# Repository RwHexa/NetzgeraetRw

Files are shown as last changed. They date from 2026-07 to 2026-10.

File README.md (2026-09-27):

# NetzgeraetRw — 12‑V‑Sperrwandler verstehen, prüfen & simulieren

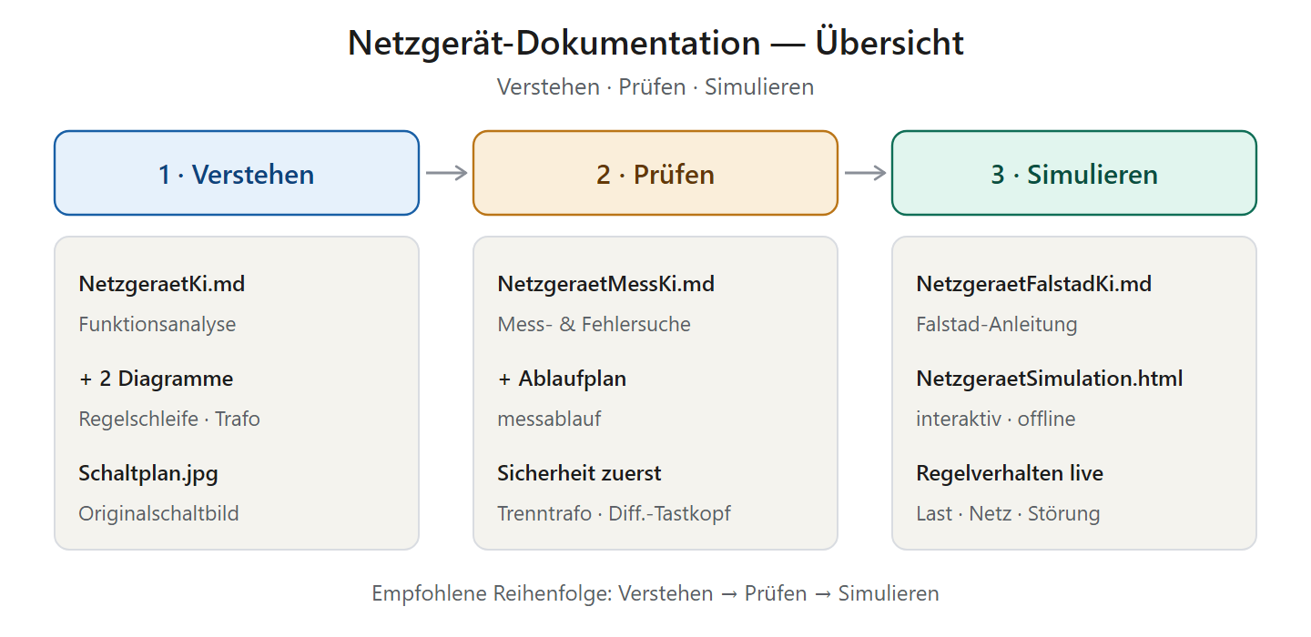
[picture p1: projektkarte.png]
Projektkarte


Dokumentation eines isolierten **Sperrwandler‑Netzteils** (12 V, ~10–15 W) mit dem PWM‑Controller **OB2263**, Optokoppler **PC817** und **TL431** — aufbereitet als Lehr‑/Werkstattbericht in drei Schritten: **Verstehen → Prüfen → Simulieren**.

## 📚 Inhalt

| Teil | Datei | Inhalt |
|---|---|---|
| 🗂️ Start | [NetzgeraetUebersichtKi.md](NetzgeraetUebersichtKi.md) | Gesamtübersicht mit Inhaltsverzeichnis & Lernpfad |
| 📘 Verstehen | [NetzgeraetKi.md](NetzgeraetKi.md) | Funktionsanalyse (Regelung, Trafo, Bauteile) |
| 🔧 Prüfen | [NetzgeraetMessKi.md](NetzgeraetMessKi.md) | Störungs‑ & Fehleranalyse (sichere Messungen) |
| 🖥️ Simulieren | [NetzgeraetFalstadKi.md](NetzgeraetFalstadKi.md) | Aufbau im Falstad‑Browser |
| 🎛️ Interaktiv | [NetzgeraetSimulation.html](NetzgeraetSimulation.html) | Offline‑Simulation des Regelverhaltens |
| 📄 Heft | `NetzgeraetHeft.pdf` | Alles gebündelt als gestaltetes PDF‑Heft |

## 🎛️ Interaktive Simulation

`NetzgeraetSimulation.html` einfach im Browser öffnen (läuft offline, keine Installation). Schieberegler für **Netzspannung** und **Laststrom**, Knöpfe für **Lastsprung** und **Regelung öffnen** — zeigt live, wie der Regelkreis die 12 V hält und was bei offener Rückkopplung passiert.

## 🖼️ Diagramme

Alle selbst erstellten Diagramme liegen als `.svg` (Quelle) **und** `.png` (2×) vor:
`regelschleife` · `trafo_zwei_phasen` · `messablauf` · `vergleich_schaltplaene` · `projektkarte`.

## ⚖️ Rechte & Quellen

- **Eigene Inhalte** (Texte, selbst erstellte Diagramme, HTML‑Simulation, Heft, Logo): © Reinhard Wermeling (RwTec), erarbeitet mit Claude Code.
- ⚠️ **Fremde Bilder** (nur zu Lern‑/Referenzzwecken): einige Bitmap‑Schaltbilder und Fotos stammen aus dem Web und unterliegen fremdem Urheberrecht — u. a. `Schaltplan_vollstaendig.jpg` (Wasserzeichen ornatepixels.com), `Schaltplan.jpg` / `SchaltplanKl.JPG`, `PlatineKl.JPG`. **Nicht für Weiterverbreitung.** Vor einer etwaigen Veröffentlichung entfernen oder durch eigene Nachzeichnungen ersetzen.

---
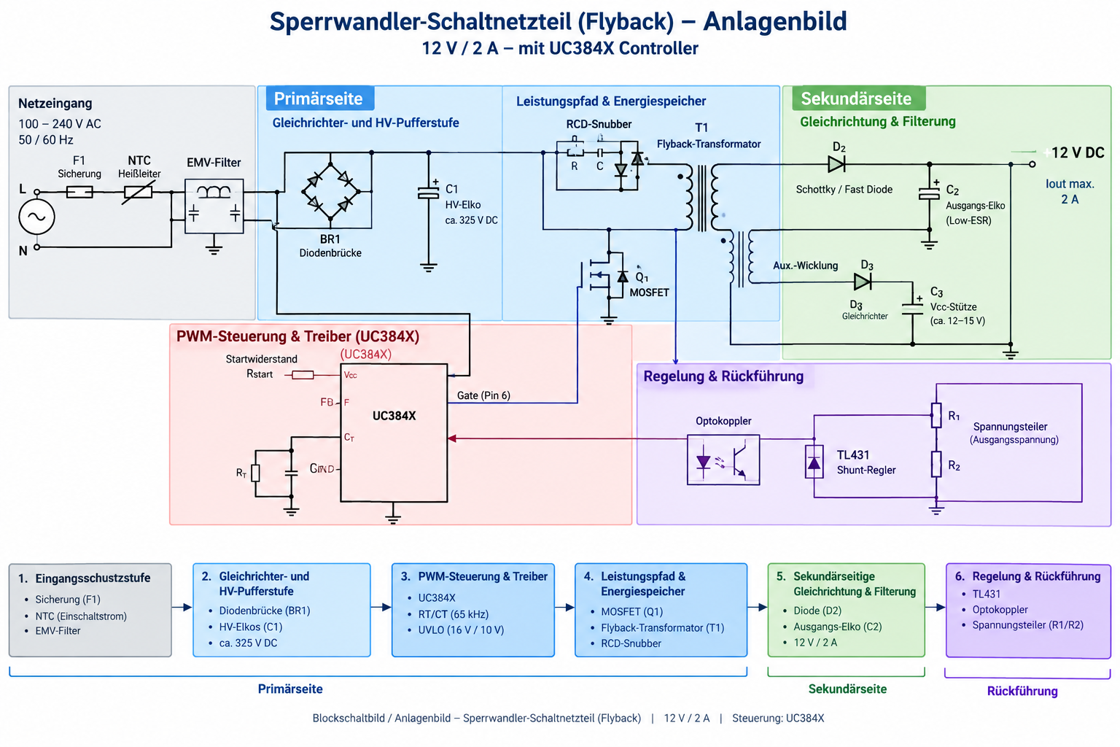
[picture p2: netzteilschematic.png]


*Werkstattbericht · RwTec · 2026 · erstellt mit Claude Code*

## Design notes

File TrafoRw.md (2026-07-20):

## 1. Einleitung und Historie
Der Flyback-Wandler (Sperrwandler) gehört zu den am weitesten verbreiteten Topologien für Schaltnetzteile. Kommerziell wird diese Technologie seit den **1940er und 1950er Jahren** genutzt. Ihr ursprünglicher Einsatzbereich lag in Röhrenfernsehern, wo der Flyback-Transformator (Zeilentransformator) die extrem hohen Spannungen für die Bildröhre generierte. Mit dem Aufkommen moderner Leistungshalbleiter (MOSFETs) in den **1970er Jahren** wandelte sich das Einsatzgebiet hin zu kompakten, hocheffizienten Netzteilen.
## 2. Funktionsprinzip und Besonderheiten
Entgegen einem klassischen Netztransformator überträgt der Flyback-Transformator die elektrische Energie nicht sofort, sondern arbeitet als **gekoppelte Speicherdrossel**:
1. **Leitphase (Ein):** Der primärseitiger Schalter schießt. Energie baut sich im Magnetfeld auf. Die sekundundärseitige Diode sperrt.
2. **Sperrphase (Aus):** Der Schalter oeffnet. Das Magnetfeld bricht zusammen und induziert eine Spannung. Die Diode leitet und die Energie wird zeitversetzt an den Ausgang abgegeben.
Um eine magnetische S\'e4ttigung des Kerns zu verhindern und eine hohe Energiespeicherung zu erm\'f6glichen, besitzt der Kern fast immer einen definierten **Luftspalt**.
## 3. Mathematische Zusammenhänge (Dimensionierung)
Die Ausgangsspannung ($U_\{out\}$) wird nicht allein durch das Windungsverhältnis ($n = N_P / N_S$) bestimmt, sondern maßgeblich durch den Tastgrad ($D$) des Schalters gesteuert:
$$U_\{out\} = U_\{in\} \\cdot \\frac\{1\}\{n\} \\cdot \\frac\{D\}\{1-D\}$$

* **Spannungsbelastung:** Beim oeffnen des Schalters entsteht eine reflektierte Spannung ($U_\{ref\} = n \\cdot U_\{out\}$) auf der Primärseite. Der Halbleiterschalter muss so dimensioniert sein, dass er die Summe aus Eingangsspannung und reflektierte Spannung ($U_\{in\} + U_\{ref\}$) sicher blockieren kann.
## 4. Wicklungsdesign und Querschnitte
Wegen der unterschiedlichen Spannungs- und Stromniveaus sind Primär- und Sekundundärseite asymmetrisch dimensioniert:
* **Leiterquerschnitt ($A$):** Bestimmt sich \'fcber den effektiven Strom ($I_\{RMS\}$) und die zul\'e4ssige Stromdichte ($J$, praxisnah $3$ bis $5\\text\{ A/mm\}^2$) nach der Formel: $A = I_\{RMS\} / J$.
* **Skin-Effekt:** Da Flyback-Wandler bei hohen Frequenzen ($50\\text\{ kHz\}$ bis \'fcber $300\\text\{ kHz\}$) arbeiten, verdr\'e4ngt der Skin-Effekt den Strom an die Drahtoberfläche. 
* **Praktische Umsetzung:** Dicke Einzeldr\'e4hte werden vermieden. Stattdessen kommen mehrere parallel gewickelte, d\'fcnne Dr\'e4hte oder flexible **HF-Litzen** (B\'fcndel isolierter Einzeladern) zum Einsatz, um den Innenwiderstand und die Erw\'e4rmung zu minimieren.
## 5. Heutige Haupteinsatzgebiete
Aufgrund der geringen Bauteilanzahl, der galvanischen Trennung und der kosteng\'fcnstigen Produktion ist der Flyback-Transformator heute der Standard f\'fcr kleine bis mittlere Leistungen (**bis ca. 150 Watt**):
* Steckernetzteile und Ladeger\'e4te (Smartphones, Laptops)
* Hilfs- und Standby-Stromversorgungen in Haushaltsger\'e4ten und PCs
* Treiberstufen f\'fcr LED-Beleuchtungen
* Kompakte Stromversorgungen in der Industrie- und Automobiltechnik
# Anhang: Stückliste ein Flyback-Beispielnetzteil

### Spezifikation des Referenzdesigns:
* **Eingangsspannung ($U_\{in\}$):** 9 V bis 16 V DC (Nennwert: 12 V)
* **Ausgangsspannung ($U_\{out\}$):** 2,67 V DC (geregelt)
* **Ausgangsstrom ($I_\{out\}$):** Max. 3 A ($I_\{RMS\} \\approx 3\\text\{ A\}$ auf der SekundundärSeite)
* **Schaltfrequenz ($f_\{sw\}$):** 100 kHz

| Bauteil-ID | Komponente | Beschreibung / Technische Daten | Menge | Geh\'e4useform / Typ |
| :--- | :--- | :--- | :--- | :--- |
| **TR1** | **Flyback-Transformator** | Kern: Ferrit (z. B. EF20 oder E25/13/7)<br>Luftspalt: ca. 0,2 mm<br>Windungsverh\'e4ltnis (n): 3:1 ($N_P = 18$, $N_S = 6$)<br>Prim\'e4rdraht: 1\'d7 0,4 mm Kupferlackdraht<br>Sekund\'e4rdraht: **HF-Litze 24\'d7 0,2 mm** (wegen Skin-Effekt) | 1 | E-Kern horizontal / Kundenspezifisch |
| **IC1** | **PWM-Controller** | Current-Mode Flyback-Controller mit fester Frequenz (100 kHz), integrierter Unterspannungssperre und Sanftanlauf. | 1 | SOIC-8 (z. B. UC384x-Serie oder LM5021) |
| **Q1** | **Leistungsschalter (MOSFET)** | N-Kanal MOSFET<br>Spannungsfestigkeit: \f1\u8805?\f0  30 V (berechnet: 20 V + Sicherheitsreserve)<br>Strombelastbarkeit: \f1\u8805?\f0  6 A<br>Niedriger Einschaltwiderstand ($R_\{DS(on)\} < 10\\text\{ m\}\\Omega$) | 1 | TO-220 oder DPAK |
| **D1** | **Ausgangsdiode** | Schottky-Diode (f\'fcr schnelles Schalten bei 100 kHz)<br>Sperrspannung: \f1\u8805?\f0  20 V<br>Dauerstrom: \f1\u8805?\f0  5 A (z. B. wegen Anlaufstr\'f6men) | 1 | TO-220AC oder SMC |
| **C_IN** | **Eingangskondensator** | Elektrolytkondensator (Low-ESR)<br>Kapazit\'e4t: 470 \'b5F / Spannungsfestigkeit: 25 V | 1 | Radial, durchsteckbar (PTH) |
| **C_OUT** | **Ausgangskondensator** | Elektrolytkondensator (Low-ESR) zur Gl\'e4ttung der pulsierenden Sperrwandler-Str\'f6me.<br>Kapazit\'e4t: 1000 \'b5F / Spannungsfestigkeit: 6,3 V | 1 | Radial, durchsteckbar (PTH) |\par
| **R_SENSE** | **Strommesswiderstand** | Shunt-Widerstand zur \'dcberwachung des Prim\'e4rstroms (\'dcberlastschutz).<br>Wert: 0,1 \f2\lang1032\'d9 / Leistung: 0,5 W | 1 | SMD 1206 oder Metallschicht |
| **IC2** | **Spannungsregler / Optokoppler** | Zur galvanisch getrennten R\f0\lang1033\'fcckf\'fchrung des Ausgangssignals an den Controller IC1.<br>Bestehend aus Referenz-IC (z. B. TL431) und Optokoppler. | 1 | DIP-4 / SOT-23 |
| **R1, C1** | **Snubber-Netzwerk (RCD)** | Bed\'e4mpft die zerst\'f6rerischen Spannungsspitzen beim Ausschalten von Q1.<br>R: 1 k\f2\lang1032\'d9 (1 W), C: 2,2 nF (100 V), D: Schnelle Diode (z. B. 1N4148) | 1 Set | SMD 1206 / DO-35 |
### Design-Hinweise zur St\f0\lang1033\'fcckliste:
1. **Der Transformator (TR1):** Da es Flyback-Transformatoren selten als Standardbauteil von der Stange gibt, wird er f\'fcr das jeweilige Projekt basierend auf dem Kernmaterial (Ferrit) und den berechneten Drahtquerschnitten (HF-Litze sekund\'e4r) meist selbst gewickelt oder als Custom-Bauteil bestellt.
2. **Die Kondensatoren (C_IN / C_OUT):** Wegen der hohen Schaltfrequenz und Rippelstr\'f6me m\'fcssen unbedingt **Low-ESR-Typen** (geringer Innenwiderstand) verwendet werden, da Standard-Elkos sonst überhitzen.

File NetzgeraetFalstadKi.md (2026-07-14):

# Den Sperrwandler in Falstad simulieren (vereinfacht)

*Schritt für Schritt zu einer animierten, geregelten Flyback‑Schaltung im Browser — ein Werkstattbericht (Simulations‑Teil)*

> **Kurzfassung:** Mit dem kostenlosen **Falstad CircuitJS** (läuft im Browser, keine Installation) lässt sich das Prinzip des Netzteils anschaulich nachbauen: Zwischenkreis → Schalter → Trafo → Gleichrichtung → **geschlossener Regelkreis**. Den OB2263 ersetzen wir durch einen kleinen PWM‑Erzeuger + Fehlerverstärker (gleiche Wirkung). Am Ende siehst du den Strom fließen und kannst live an Last und Eingangsspannung drehen — genau wie im Lern‑Widget.

---

## 🧭 Warum Falstad — und was es kann/nicht kann

- ✅ **Sofort startklar:** [falstad.com/circuit](https://www.falstad.com/circuit/) im Browser öffnen, fertig. Es gibt auch eine Desktop‑Version.
- ✅ **Animierter Stromfluss** — ideal fürs Verstehen von Gleichrichtung, Trafo und Rückkopplung.
- ⚠️ **Kein OB2263‑Modell** (gibt es nirgends frei). Wir bauen seine *Architektur* nach: Sägezahn + Komparator = PWM, Op‑Amp = Fehlerverstärker.
- ⚠️ **Vereinfachte Trennung:** Für die Anschauung lassen wir TL431 + Optokoppler weg und regeln mit **einem** Op‑Amp auf gemeinsamer Masse. Das zeigt das Regelverhalten korrekt — nur eben ohne galvanische Trennung. (Erweiterung siehe unten.)

---

## ⚙️ Vorbereitung (wichtig!)

Ein Schaltnetzteil taktet mit ~65 kHz. Damit Falstad das sauber rechnet:

1. Menü **Options → Other Options**: **Time step size** auf ca. **`1e-7` … `2e-7` s** stellen (Standard 5e‑6 ist viel zu grob → unbrauchbar).
2. Oben den Regler **Simulation Speed** langsam stellen, um die Vorgänge zu beobachten.
3. Menü **Scopes**: Später Messpunkte hinzufügen (Rechtsklick auf Bauteil → *View in Scope*).

---

## 🗺️ Detaillierter Schaltplan (zum Nachbauen)

Dieser Plan zeigt jeden Knoten. **Gleiche Netznamen** (`VOUT`, `GATE`, `CONTROL`, `FB`) sind in Falstad **derselbe Knoten** — du kannst sie entweder direkt verdrahten oder in Falstad als *Labeled Node* (`Draw → Outputs and Labels → Add Labeled Node`) gleich benennen. Die Schaltung ist **nicht isoliert** (eine gemeinsame Masse).

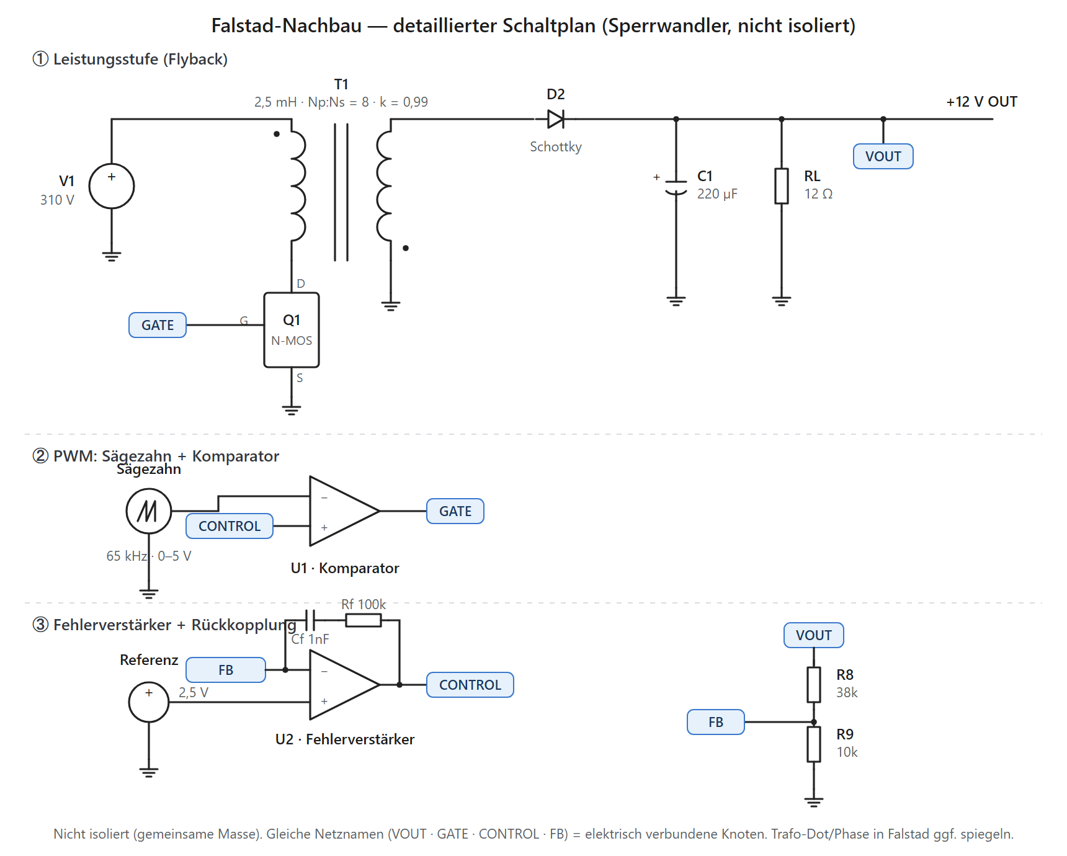
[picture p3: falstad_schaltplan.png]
Detaillierter Falstad-Schaltplan des Sperrwandlers


### Verdrahtungs-Checkliste (Knoten für Knoten)

| Knoten | Verbindet |
|---|---|
| **VIN** | V1 (+) · T1 Primär oben |
| **DRAIN** | T1 Primär unten · Q1 Drain · (Snubber optional) |
| **GATE** | Q1 Gate · Komparator‑Ausgang (U1) |
| **RAMP** | Sägezahn‑Quelle · Komparator **−**‑Eingang (U1) |
| **CONTROL** | Fehlerverstärker‑Ausgang (U2) · Komparator **+**‑Eingang (U1) |
| **SEK** | T1 Sekundär · D2 Anode |
| **VOUT** | D2 Kathode · C1 (+) · RL · R8 (oben) |
| **FB** | R8/R9‑Mittelabgriff · U2 **−**‑Eingang · RC‑Glied (Rf/Cf) |
| **REF** | 2,5‑V‑Quelle · U2 **+**‑Eingang |
| **GND** | V1 (−) · Q1 Source · T1 Sekundär (andere Seite) · C1/RL (−) · R9 · alle Quellen‑Massen |

> 💡 **Reihenfolge, die selten hakt:** erst die **Leistungsstufe** (V1 → T1 → Q1 → D2 → C1/RL) aufbauen und mit einer festen Gate‑Rechteckquelle testen (schaltet der MOSFET, kommt Spannung raus?). Dann **U1 + Sägezahn** dranhängen (PWM steht). Zuletzt **U2 + Teiler + Referenz** — jetzt schließt sich der Regelkreis.

---

## 🛠️ Der Aufbau in 7 Schritten

Bauteile kommen aus dem **Draw**‑Menü (Kategorien heißen je nach Version leicht anders). Werte per **Rechtsklick → Edit** einstellen.

**① Zwischenkreis (die „~310 V")**
- `Draw → Inputs and Sources → Add Var Rail` (einstellbare DC‑Quelle). Wert **310 V**. Der Schieberegler dieser Quelle wird später dein „Netzspannungs"-Regler.
- `Add Ground` als Bezugsmasse.

**② Sperrwandler‑Trafo**
- `Draw → Passive Components → Add Transformer`.
- Rechtsklick → Edit: **Primary Inductance ≈ 2,5 mH**, **Turns Ratio (Np:Ns) ≈ 8**, **Coupling Coefficient 0,99**.
- Primär‑oben an **+310 V**.

**③ Schalttransistor (statt Q1)**
- `Draw → Active Components → Add MOSFET (N‑Channel)`.
- **Drain** an Primär‑unten, **Source** an Masse, **Gate** kommt später vom PWM (Schritt ⑤).

**④ Sekundär‑Gleichrichtung**
- `Add Diode` von der Sekundärwicklung zum Ausgangsknoten (**+12 V**).
- `Add Capacitor` **220 µF** vom Ausgang zur Sekundärmasse.
- `Add Resistor` **12 Ω** als Grundlast (≈ 1 A). Optional einen `Add Switch` mit zweitem Lastwiderstand für den „Lastsprung".
- 🔎 *Dot‑Test:* Leitet die Diode schon in der **Einschaltphase**, ist die Wicklung falsch herum — dann die **beiden Sekundär‑Anschlüsse tauschen** (Flyback ⇒ Diode leitet in der Ausschaltphase).

**⑤ PWM erzeugen (statt Oszillator im OB2263)**
- `Add A/C Voltage Source` → Edit: **Waveform = Sawtooth**, **Frequency = 65k**, Amplitude/Offset so, dass sie **0…5 V** rampt.
- `Add Op Amp` als **Komparator**: **−**‑Eingang = Sägezahn, **+**‑Eingang = Regelspannung (aus ⑥), **Ausgang → Gate** des MOSFET. So gilt: Regelspannung hoch ⇒ Tastverhältnis groß.

**⑥ Rückkopplung / Fehlerverstärker (statt TL431 + Opto)**
- Teiler **R8 = 38 kΩ** (oben, von +12 V) und **R9 = 10 kΩ** (unten, zur Masse). Mittelabgriff = Istwert.
- Referenz **2,5 V**: eigener `Add Var Rail` (2,5 V) oder Zenerdiode.
- `Add Op Amp` als **Fehlerverstärker**: **−**‑Eingang = Istwert (Teiler), **+**‑Eingang = 2,5 V, **Ausgang = Regelspannung** → an den +‑Eingang des Komparators (⑤).
- Zur Stabilität ein **RC‑Glied** (z. B. 100 kΩ + 1 nF) vom Op‑Amp‑Ausgang zurück auf den −‑Eingang (macht ihn zum PI‑Regler).
- 🔑 Vorzeichen: Steigt U_out → Istwert steigt → (invertierender Eingang) Regelspannung sinkt → Duty sinkt → U_out sinkt. **Gegenkopplung.** Ausgangsspannung stellt sich auf `U_out = 2,5 V × (1 + R8/R9) = 2,5 × 4,8 = 12 V` ein.

**⑦ Messen & Ausprobieren**
- Rechtsklick → *View in Scope* auf: **Ausgang (+12 V)**, **Gate**, **Primärwicklung (Strom)**.
- Grundlast ändern (Widerstand editieren) → U_out bleibt ~12 V.
- **Var Rail (310 V) schieben** → U_out bleibt stabil, Duty ändert sich.
- **Regelung „öffnen":** die Regelspannung fest verdrahten (Fehlerverstärker abklemmen) → bei kleiner Last **läuft U_out in die Überspannung** — dieselbe Aussage wie im Lern‑Widget.

---

## 📋 Bauteil-/Wertetabelle

| Element (Falstad) | Wert | Rolle in der echten Schaltung |
|---|---|---|
| Var Rail | 310 V | Zwischenkreis C2 (~325 V) |
| Transformer | L₁ 2,5 mH · n 8 · k 0,99 | T1 (EE16) |
| MOSFET (N) | Standard | Q1 (7N65) |
| Diode | Standard/Schottky | D2 (SR540) |
| Capacitor | 220 µF | C6 |
| Resistor (Last) | 12 Ω | Verbraucher |
| A/C Source (Sawtooth) | 65 kHz, 0–5 V | Oszillator im OB2263 |
| Op Amp (Komparator) | ideal | PWM‑Vergleicher (CS/FB‑Logik) |
| Op Amp (Fehlerverst.) | + RC 100k/1nF | TL431 |
| R8 / R9 | 38 kΩ / 10 kΩ | Sollwert‑Teiler |
| Var Rail (2,5 V) | 2,5 V | interne TL431‑Referenz |

---

## ⚠️ Stolpersteine

- **Time step vergessen** → 65 kHz wird nicht aufgelöst, „Konvergenzfehler" oder Unsinn. Immer ~`1e-7` setzen.
- **Trafo‑Kopplung 0,99**, nicht 1,0 — sonst kein realistisches Verhalten; eine kleine Streuung erzeugt eine Drain‑Spitze (dafür bräuchte man einen Snubber).
- **Falsche Dot‑Orientierung** → Diode leitet zur falschen Zeit → Sekundär‑Anschlüsse tauschen.
- **Vorzeichen der Regelung** → läuft U_out weg oder auf 0, die beiden Op‑Amp‑Eingänge tauschen.
- **Op‑Amp schwingt** → RC‑Kompensation vergrößern (Cf erhöhen).

---

## ✅ Funktionierende Simulation (Ergebnis)

So sieht der laufende Regelkreis in Falstad aus — stabile Ausgangsspannung, alle Blöcke aktiv:

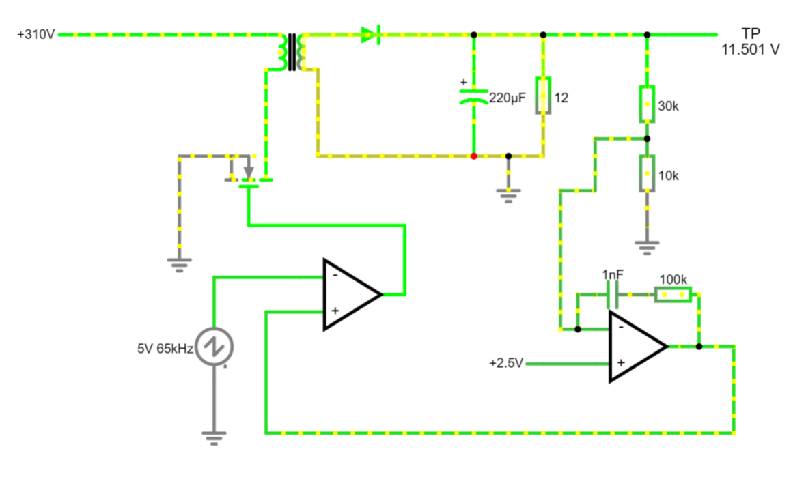
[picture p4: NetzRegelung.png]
Falstad-Simulation der Regelung — TP ≈ 11,5 V


> **Kurzfassung:** Der Teiler **30k/10k** ergibt den Lehrbuch‑Sollwert `2,5 V × (1 + 30/10) = 10 V`; angezeigt werden **11,5 V**. Dieser kleine Rest‑Offset ist normal — der vereinfachte Fehlerverstärker ist kein idealer Integrator (endliche Schleifenverstärkung). Reale Controller wie der OB2263 fahren die Verstärkung so hoch, dass er praktisch verschwindet.

- **Regelung nachweisen:** Last ändern (12 Ω → 8/24 Ω) oder die 310‑V‑Rail schieben → TP bleibt (nahezu) stehen = die Schleife regelt.
- **Exakt 12 V:** oberen Teilerwiderstand trimmen, bis TP 12,0 V zeigt — oder U2 als echten Integrator (Serien‑C + Eingangswiderstand) verschalten.

---

## 🚀 Ausbaustufen

1. **Netzeingang echt:** Var Rail ersetzen durch `A/C Voltage Source` (325 V Spitze, 50 Hz) + 4 Dioden‑Brücke + 47 µF → man sieht die ~310 V entstehen.
2. **Snubber:** RCD‑Glied über der Primärwicklung, um die Drain‑Spitze zu zähmen.
3. **Echte Trennung:** Optokoppler als LED + lichtgesteuerte Stromquelle nachbilden und Fehlerverstärker auf eine zweite Masse legen — anspruchsvoll, aber näher am Original.

> 💡 Für den Unterricht reichen die Schritte ①–⑦ völlig: Man sieht **Leistungspfad** (Var Rail → MOSFET → Trafo → Diode → Last) und **Regelpfad** (Teiler → Fehlerverstärker → Komparator → Gate) zusammenspielen — und im „offenen" Zustand, warum die Rückkopplung überlebenswichtig ist.

---

## 🎯 Fazit

Falstad bildet nicht den Chip, aber sein **Verhalten** ab — und genau das will man beim Verstehen. In wenigen Minuten steht ein animierter, geschlossener Sperrwandler‑Regelkreis, an dem man Last und Eingangsspannung live variieren kann. Wer es quantitativer braucht, baut dieselbe Topologie später in **LTspice** nach.

---



*Erstellt: 2026‑07‑11 · OB2263‑Sperrwandler · Simulation in Falstad · erarbeitet mit Claude Code (Opus 4.8) + Rw*

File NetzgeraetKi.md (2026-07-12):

# Ein 12‑V‑Schaltnetzteil verstehen — OB2263, Optokoppler & TL431

*Wie aus 230 V Netzspannung geregelte, berührsichere 12 V werden — ein Werkstattbericht*

> **Kurzfassung:** Die Schaltung ist ein ==isolierter Sperrwandler== (Flyback‑Schaltnetzteil) mit rund 12 V Ausgang und etwa 10–15 W. Ein PWM‑Controller **OB2263** taktet einen MOSFET, ein kleiner Trafo speichert die Energie häppchenweise und trennt gleichzeitig die gefährliche Netzseite von der sicheren 12‑V‑Seite. Geregelt wird die Ausgangsspannung sekundärseitig mit einem **TL431** und isoliert über einen **Optokoppler PC817** an den Controller zurückgemeldet. Dieses Prinzip steckt in fast jedem Steckernetzteil und Ladegerät.

---

## 🧭 Ausgangslage — was liegt auf dem Tisch?

Vor uns liegt der Schaltplan eines kompakten Netzteils, das aus dem 230‑V‑Wechselstromnetz stabile **12 V Gleichspannung** macht. Es ist ein **primärgetaktetes Schaltnetzteil** — kein schwerer 50‑Hz‑Trafo, sondern ein winziger Hochfrequenz‑Trafo (Kerngröße EE16), der mit rund 65 kHz betrieben wird. Das macht das Ganze klein, leicht und effizient.

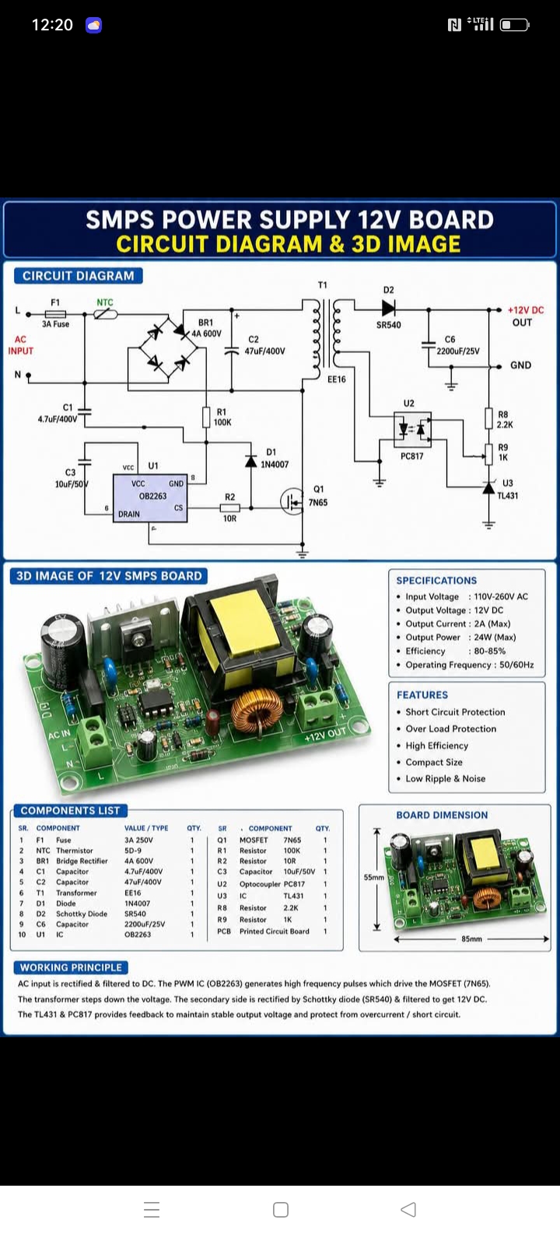
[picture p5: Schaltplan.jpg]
Schaltplan des 12‑V‑Netzteils


Die Schaltung zerfällt in ==zwei galvanisch getrennte Welten==:

- **Primärseite** — direkt am Netz, führt lebensgefährliche ~325 V Gleichspannung
- **Sekundärseite** — berührsichere 12 V für den Verbraucher

Verbunden sind beide **nur** über zwei Bauteile: den **Trafo** (überträgt Energie) und den **Optokoppler** (überträgt Information). Genau diese Trennung ist das Sicherheitsherz der Schaltung.

---

## 📐 Der große Überblick — die Topologie

Das Funktionsprinzip heißt **Sperrwandler** (englisch *flyback*):

> Der MOSFET zerhackt die Gleichspannung in schnelle Impulse. In der Einschaltphase wird Energie im Trafo gespeichert, in der Ausschaltphase an den Ausgang „ausgeworfen". Primär- und Sekundärseite leiten dabei **nie gleichzeitig**.

Der Regelkreis schließt sich einmal im Uhrzeigersinn: Der Controller steuert den Schalter (Leistung), die 12 V werden gemessen und über den Optokoppler zurückgemeldet (Information) — und der Controller korrigiert nach.

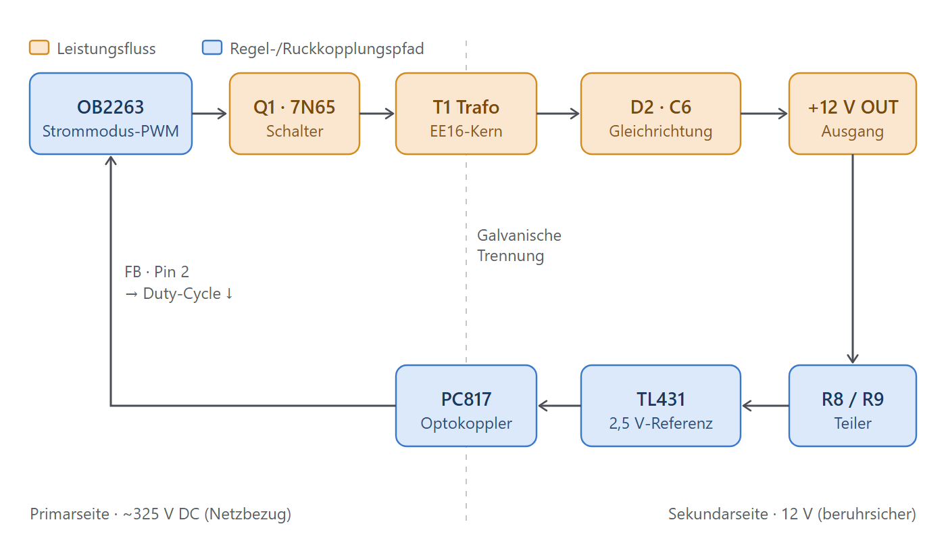
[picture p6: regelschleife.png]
Die Regelschleife im Überblick


🟠 = Leistungsfluss · 🔵 = Regel-/Rückkopplungspfad. Der Trafo (oben) und der Optokoppler (unten) sind die einzigen Brücken über die galvanische Trennung.

---

## 🔩 Signalfluss — Block für Block

**1. Netzeingang & Schutz**
- 🛡️ **F1 (3 A)** — Sicherung gegen Überstrom und Brandfall
- 🛡️ **NTC** — Einschaltstrombegrenzer: kalt hochohmig, dämpft den Ladestromstoß beim Einschalten; erwärmt sich dann und wird niederohmig
- **C1 (4,7 µF / 400 V)** — Eingangs‑/Entstörkondensator

**2. Gleichrichtung & Sieben**
- **BR1 (4 A / 600 V)** — Brückengleichrichter: macht aus 230 V~ pulsierenden Gleichstrom
- **C2 (47 µF / 400 V)** — Lade‑Elko: glättet auf die ==~325 V Zwischenkreisspannung==. Das ist die „Batterie", aus der der Wandler schöpft.

**3. Anlauf & Controller‑Versorgung**
- **R1 (100 k)** — Anlaufwiderstand: lädt beim Einschalten langsam den VCC‑Kondensator, bis der OB2263 seine Einschaltschwelle (UVLO) erreicht
- **C3 (10 µF / 50 V)** — VCC‑Stützkondensator
- **D1 (1N4007) + Hilfswicklung** — nach dem Anlauf versorgt eine Hilfswicklung am Trafo den Controller dauerhaft

**4. Schaltstufe**
- **Q1 (7N65)** — der Leistungs‑MOSFET, das eigentliche Schaltventil (Details unten)
- **T1 (EE16)** — der Sperrwandler‑Trafo, Energiespeicher und Trennstelle (Details unten)
- **R2 (10 Ω)** — Strom‑Messwiderstand für die Stromregelung

**5. Sekundär‑Gleichrichtung**
- **D2 (SR540)** — Schottky‑Diode (5 A / 40 V): leitet in der Ausschaltphase, geringe Verluste
- **C6 (2200 µF / 25 V)** — Ausgangs‑Elko: glättet auf saubere 12 V

---

## 🎯 Herzstück: Die Regelung (OB2263 + Optokoppler + TL431)

Der OB2263 ist ein ==Strommodus‑PWM‑Controller==. Das Besondere: Er regelt nicht direkt die Spannung, sondern in **jedem einzelnen Takt den Spitzenstrom** durch den MOSFET. Daraus ergeben sich zwei ineinander verschachtelte Regelschleifen.

### 🔬 Innere, schnelle Schleife — Stromregelung (CS / R2)

Sobald Q1 einschaltet, steigt der Strom rampenförmig an. R2 (10 Ω) bildet ihn als Spannung am **CS‑Pin** ab. Erreicht diese die vom FB‑Pin vorgegebene Schwelle, schaltet der OB2263 den MOSFET ==Takt für Takt sofort ab==. Vorteile: sehr gute Netzausregelung — und der **Überstromschutz ist praktisch geschenkt**. Interne Extras: *Leading‑Edge‑Blanking* (blendet den Einschalt‑Stromspike aus) und *Slope‑Kompensation* (verhindert Schwingen bei >50 % Tastverhältnis).

### 🔑 Äußere, langsame Schleife — Spannungsregelung (der Optokoppler‑Pfad)

Hier läuft die eigentliche „12 V"-Regelung, komplett **sekundärseitig gemessen** und isoliert zurückgemeldet:

1. **U3 (TL431)** — eine programmierbare Präzisionsreferenz mit interner **2,5‑V‑Referenz**. Sie ist Referenz **und** Fehlerverstärker in einem Bauteil und vergleicht über den Teiler **R8/R9** die Ausgangsspannung mit ihrem Sollwert.
2. **U2 (PC817)** — der Optokoppler. Seine LED steuert der TL431 an; der Fototransistor sitzt primärseitig am **FB‑Pin (Pin 2)** des OB2263 und ist die einzige Signalbrücke über die Trennstelle.

Die Wirkungskette bei **steigender** Ausgangsspannung (das Vorzeichen der Regelung):

> U_out ↑ → Teiler hebt REF über 2,5 V → TL431 zieht mehr Strom → PC817‑LED heller → Fototransistor leitet stärker → **FB‑Pin wird heruntergezogen** → OB2263 senkt die Stromschwelle → Q1 schaltet früher ab → weniger Energie pro Takt → **U_out sinkt wieder.**

Und exakt umgekehrt, wenn die Spannung einbricht. Das ist eine saubere ==Gegenkopplung==. Laut Datenblatt liegt die *Zero‑Duty‑Schwelle* bei FB ≈ 0,75 V: Zieht der Optokoppler FB so weit herunter, geht das Tastverhältnis gegen null.

### 🧮 Der Sollwert (TL431‑Formel)

Der TL431 regelt so, dass an seinem REF‑Pin genau 2,5 V anliegen:

$$U_{out} = 2{,}5\,\text{V} \times \left(1 + \frac{R_{oben}}{R_{unten}}\right)$$

> ⚠️ **Zum Mitrechnen:** Mit den *im Schaltbild angeschriebenen* Werten R8 = 2,2 k / R9 = 1 k käme rechnerisch 2,5 × (1 + 2,2) = **≈ 8 V** heraus, nicht 12 V. Für echte 12 V braucht man R_oben/R_unten ≈ 3,8 (z. B. ~3,8 k / 1 k). Solche „Circuit‑Diagram"-Grafiken sind **prinzipiell** korrekt — die konkreten Bauteilwerte sollte man aber nicht als exakt nehmen.

---

## 🧲 Der Sperrwandler‑Trafo als Energiespeicher

Das Wichtigste vorweg: **T1 ist gar kein „Trafo" im klassischen Sinn**, sondern eine ==gekoppelte Speicherdrossel==. Er arbeitet im Zweitakt.

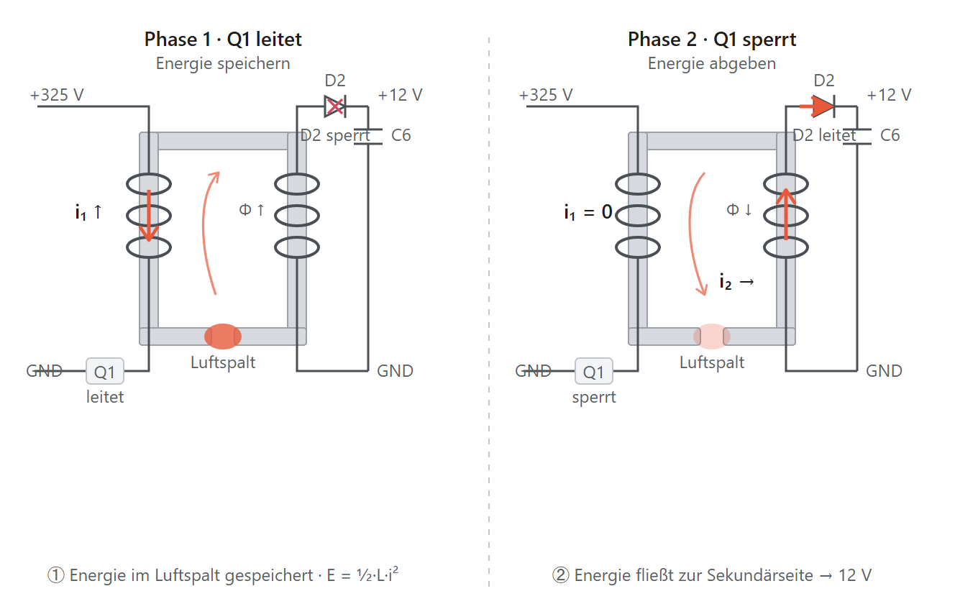
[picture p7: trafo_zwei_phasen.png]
Energie speichern und abgeben — die zwei Phasen


| Klassischer Trafo | Sperrwandler‑Trafo (Flyback) |
|---|---|
| Energie fließt gleichzeitig rein und raus | erst speichern, dann abgeben |
| Primär & Sekundär leiten zusammen | leiten **nie** gleichzeitig |
| speichert (idealerweise) keine Energie | **muss** Energie zwischenspeichern |

**① Speichern (Q1 leitet):** Der Primärstrom steigt rampenförmig, der magnetische Fluss wächst, Feldenergie lädt sich auf: $E = \tfrac{1}{2}\,L\,i^2$. Die Diode D2 sperrt — noch fließt nichts zum Ausgang.

**② Abgeben (Q1 sperrt):** Der Strom wird schlagartig unterbrochen. Der Fluss kann nicht springen, also kehrt sich die Spannung um, D2 wird leitend, und die gespeicherte Energie wird an C6/den Ausgang „ausgeworfen" (daher *Fly‑back*).

> 🔑 **Warum der Luftspalt entscheidend ist:** Im kleinen Luftspalt des EE16‑Kerns steckt der Löwenanteil der Energie. Ohne Spalt würde das Ferrit schon bei kleinem Strom in die **Sättigung** gehen und der MOSFET durchbrennen. Ein reiner Trafo *will* keinen Spalt — ein Flyback‑Trafo *braucht* ihn.

Nebenbei leistet T1 noch zweierlei: die **Spannungsübersetzung** über das Windungsverhältnis $n = N_p/N_s$ (aus 325 V werden 12 V) und die **galvanische Trennung** der beiden Wicklungen.

**Die Brücke zur Regelung:** Die pro Takt übertragene Leistung ist im lückenden Betrieb (DCM) grob $P \approx \tfrac{1}{2}\,L\,i_{pk}^2 \cdot f$. Genau an dieser Schraube — *wie hoch der Primärstrom pro Takt laufen darf* — dreht der Regelkreis.

---

## 🔦 Der Optokoppler PC817 — Information über die Grenze

Der PC817 vereint **LED und Fototransistor** in einem Gehäuse, die sich nur mit Licht verständigen. Es gibt ==keine elektrische Verbindung== — es wandern nur Photonen über einen Isolierspalt (typ. bis ~5000 V spannungsfest). Das übertragene Signal ist ein **Strom bzw. eine Lichtstärke**, keine Spannung.

Der Kennwert ist das **CTR** (Current Transfer Ratio), das Verhältnis von Kollektor‑ zu LED‑Strom:

$$I_C = \text{CTR} \times I_{LED}$$

Beim PC817 liegt CTR grob bei 50–600 % (die Bauteile sind in Klassen sortiert). Wichtig: Er arbeitet hier **analog im linearen Bereich** — er überträgt einen stufenlosen Fehlerpegel, nicht nur „ein/aus". Weil der Fototransistor relativ langsam ist, begrenzt er die Regelbandbreite; deshalb braucht der TL431 in der Praxis noch ein RC‑Kompensationsglied.

> 💡 **Merksatz:** Der Trafo überträgt die **Energie** isoliert, der Optokoppler überträgt die **Information** isoliert. Zusammen schließen sie den Regelkreis über die Sicherheitsgrenze hinweg.

---

## 🔀 Der MOSFET 7N65 — der Zerhacker

Q1 (**650 V / ~7 A N‑Kanal‑Leistungs‑MOSFET**) ist das schnell schaltende Ventil, das aus der ruhenden Gleichspannung erst die hochfrequenten Impulse macht — ein Trafo koppelt nur *Wechsel*-/Impulsgrößen, reinen Gleichstrom nicht.

**Warum ausgerechnet 650 V?** In der Ausschaltphase liegt am Drain die Summe aus:

$$U_{Drain} \approx \underbrace{U_{Bus}}_{\sim325\,V} + \underbrace{n\cdot(U_{out}+U_{D2})}_{\text{reflektiert}} + \underbrace{\text{Leck-Spitze}}_{\text{Streuinduktivität}}$$

Das kann leicht 450–550 V erreichen — der 650‑V‑Typ liefert die nötige Sicherheitsreserve.

Q1 spielt drei Rollen zugleich:

| Rolle | Wie |
|---|---|
| **Leistungsschalter** | zerhackt den HV‑Bus mit ~65 kHz → Energie in den Trafo |
| **Stellglied der Regelung** | seine Einschaltdauer bestimmt die übertragene Energie |
| **Strom‑Messpunkt** | sein Source‑Strom über R2 liefert die Strommodus‑Info + Überstromschutz |

Q1 ist damit der Punkt, an dem **Steuerung (Gate), Leistung (Drain/Trafo) und Rückmeldung (Source/CS)** zusammenlaufen.

---

## 🛡️ Schutzfunktionen (im OB2263 integriert)

- ✅ **UVLO** — Unterspannungssperre für sicheren An-/Auslauf
- ✅ **Zyklischer Überstromschutz** — über CS/R2, Takt für Takt
- ✅ **Überlast / Kurzschluss** — Umschalten in *Hiccup*/Auto‑Restart (periodisches Wiederanlaufen statt Durchbrennen)
- ✅ **Übertemperatur** und teils **Ausgangs‑Überspannungsschutz**

---

## ⚠️ Stolpersteine & Hinweise zum Schaltbild

Das vorliegende „Circuit‑Diagram" ist vereinfacht und an einigen Stellen ungenau — gut zu wissen beim Nachvollziehen:

- **Pin‑Beschriftung „DRAIN / 6" am U1** passt nicht zum realen OB2263‑Pinout. Funktional relevant: **FB (Pin 2)** ← Optokoppler, **CS (Pin 4)** ← R2, dazu **GATE** (treibt Q1), **VDD**, **GND**, **RT** (Frequenz). Der Pin zum MOSFET ist der Gate‑Treiber.
- Die **Hilfswicklung** für die VCC‑Versorgung ist nicht eingezeichnet (D1 gehört dazu).
- Ein **Primär‑Snubber (RCD‑Klemme)** über der Primärwicklung, der die Leck‑Spitze am Drain begrenzt, fehlt — auf einer echten Platine ist er praktisch immer vorhanden.
- Der **Spannungsteiler R8/R9** ergibt rechnerisch ~8 V (siehe Formel‑Kasten oben).

---

## 🔁 Vollständiger vs. vereinfachter Schaltplan

Das obige „Circuit‑Diagram" (`Schaltplan.jpg`) lässt einige Verbindungen weg — vor allem die **Rückmeldeleitung vom Optokoppler zum FB‑Pin**. Deshalb wirkt der Optokoppler dort scheinbar „unverbunden". Ein vollständigerer Referenzplan desselben Prinzips (generischer Controller **U1**, aus dem Kontext „LED‑TV — PWM Controlled SMPS") zeichnet sie ausdrücklich ein:

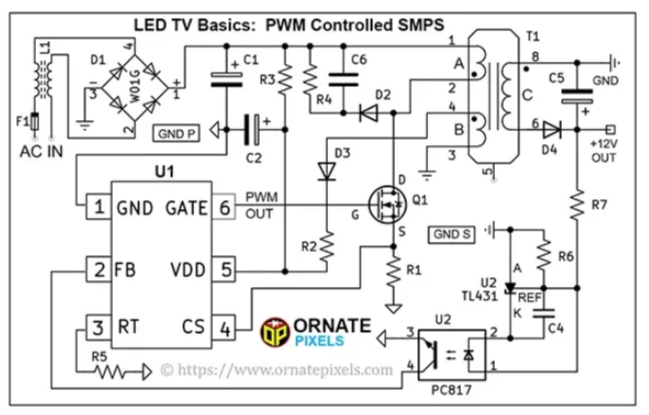
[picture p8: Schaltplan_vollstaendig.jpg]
Vollständiger Referenz-Schaltplan (gleiches Sperrwandler-Prinzip)


Dort trägt der Controller genau das Pin‑Schema, das wir für den OB2263 beschrieben haben: **1 GND · 2 FB · 3 RT · 4 CS · 5 VDD · 6 GATE**. Und der Regelweg ist lückenlos gezeichnet:

> **+12 V OUT** → Teiler **R7 / R6** → **REF** des **TL431** → TL431 steuert den **PC817**‑LED‑Strom → Licht → Fototransistor → **FB (Pin 2)** von U1 → Emitter auf **GND P**.

Damit wird sichtbar, was im ersten Bild fehlte:

| Detail | Vereinfacht (`Schaltplan.jpg`) | Vollständig (Referenzplan) |
|---|---|---|
| FB‑Pin + Opto‑Rückleitung | fehlt | ✅ gezeichnet |
| RT‑Widerstand (Frequenz) | fehlt | ✅ R5 an Pin 3 |
| Primär‑Snubber (RCD‑Klemme) | fehlt | ✅ R3 / R4 / C6 / D2 |
| Getrennte Massen | nicht markiert | ✅ GND P / GND S |

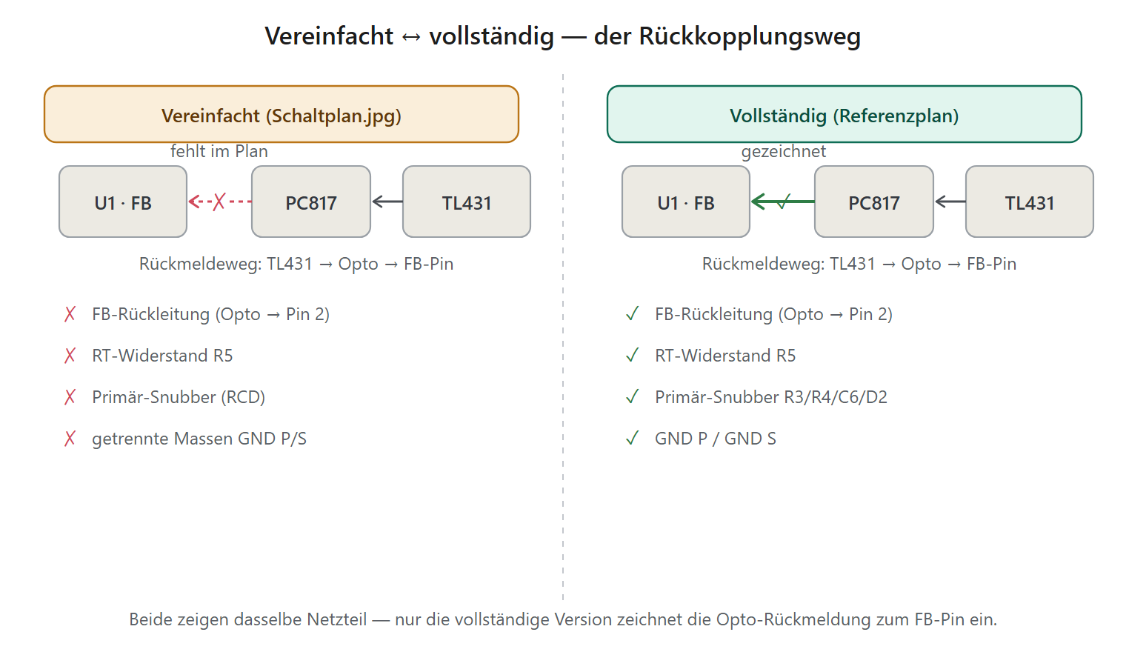
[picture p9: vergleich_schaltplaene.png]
Gegenüberstellung: vereinfachter vs. vollständiger Schaltplan — der Rückkopplungsweg


> 🔑 **Merke:** Über die galvanische Trennung führt **nie ein Draht** — die „Verbindung" ist das Licht im Optokoppler. Die einzige elektrische Rückleitung liegt auf der Primärseite: ==Fototransistor‑Kollektor → FB (Pin 2)==.

Zwei Beschriftungs‑Stolpersteine in diesem Referenzplan: **TL431 und PC817 sind beide mit „U2" beschriftet** (richtig wäre U2 / U3), und **D2** ist dort die **Klemmdiode des Snubbers** — der Ausgangsgleichrichter heißt hier **D4**.

---

## 📚 Bauteilliste

| Bauteil | Wert / Typ | Funktion |
|---|---|---|
| F1 | 3 A | Netzsicherung |
| NTC | Thermistor | Einschaltstrombegrenzung |
| C1 | 4,7 µF / 400 V | Eingangs‑/Entstörkondensator |
| BR1 | 4 A / 600 V | Brückengleichrichter |
| C2 | 47 µF / 400 V | Zwischenkreis‑Elko (~325 V) |
| R1 | 100 k | Anlaufwiderstand |
| D1 | 1N4007 | Gleichrichter Hilfswicklung (VCC) |
| C3 | 10 µF / 50 V | VCC‑Stützkondensator |
| U1 | OB2263 | Strommodus‑PWM‑Controller |
| Q1 | 7N65 | Leistungs‑MOSFET (650 V / ~7 A) |
| R2 | 10 Ω | Strom‑Messwiderstand (CS) |
| T1 | EE16 | Sperrwandler‑Trafo (Speicher + Trennung) |
| D2 | SR540 | Schottky‑Sekundärgleichrichter (5 A / 40 V) |
| C6 | 2200 µF / 25 V | Ausgangs‑Elko |
| U3 | TL431 | Präzisionsreferenz / Fehlerverstärker |
| U2 | PC817 | Optokoppler (isolierte Rückmeldung) |
| R8 / R9 | 2,2 k / 1 k | Spannungsteiler (Sollwert) |

---

## 💡 Verständnisfragen (für den Unterricht)

1. Warum leiten Primär- und Sekundärseite eines Sperrwandlers nie gleichzeitig?
2. Wozu dient der Luftspalt im Trafokern — und was passiert ohne ihn?
3. Welchen Weg nimmt die Regelinformation vom 12‑V‑Ausgang zurück zum Controller?
4. Warum muss der MOSFET 650 V aushalten, obwohl der Bus nur ~325 V führt?
5. Was übernimmt der Optokoppler, was der Trafo — und warum braucht es beide?

---

## 🎯 Fazit

Dieses kleine Netzteil zeigt ein komplettes Regelungskonzept auf engstem Raum: Ein **Strommodus‑Controller** taktet einen MOSFET, ein **Speichertrafo** portioniert die Energie und trennt sicher, und eine **sekundärseitige Regelung aus TL431 + Optokoppler** hält die 12 V stabil — isoliert und präzise. Wer dieses Zusammenspiel aus **Leistungspfad** und **Regelpfad** einmal verstanden hat, erkennt es in fast jedem modernen Steckernetzteil wieder.

---



*Erstellt: 2026‑07‑11 · OB2263‑Sperrwandler‑Analyse · erarbeitet mit Claude Code (Opus 4.8) + Rw*

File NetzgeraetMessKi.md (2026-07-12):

# Störungs- und Fehleranalyse am 12‑V‑Sperrwandler

*Durchführbare Messungen an der OB2263‑Schaltung — ein Werkstattbericht (Service‑Teil)*

> **Kurzfassung:** Dieser Zusatz zeigt, **wie** man das Netzteil systematisch durchmisst — vom spannungsfreien Bauteiltest bis zur Oszilloskop‑Messung unter Spannung. ==Achtung: Die Primärseite führt Netzpotential (~325 V).== Die primäre „Masse" ist **nicht** Schutzerde. Ohne Trenntransformator und Differenztastkopf ist Messen an der Primärseite lebensgefährlich. Zu jedem Messpunkt steht der Sollwert und was eine Abweichung bedeutet.

---

## ⚡ Sicherheit zuerst — bitte vollständig lesen

> 🛑 **Lebensgefahr.** Ein Fehler an der Primärseite kann tödlich sein. Wer sich unsicher ist, misst **nicht** unter Spannung.

- **Primäre „Masse" ≠ Schutzerde.** Der Minuspol von C2 liegt am gleichgerichteten Netz (~325 V gegen Erde). ==Niemals die Masseklemme eines geerdeten Oszilloskops an die Primärseite klemmen== → Kurzschluss über den Schutzleiter, Lichtbogen, Lebensgefahr.
- **Trenntransformator ist Pflicht** für alle Arbeiten unter Spannung. Er hebt den Erdbezug auf, sodass eine einzelne versehentliche Erdberührung nicht sofort einen Stromschlag auslöst. ⚠️ Er macht die Schaltung **nicht** berührsicher — zwischen den Primärpunkten liegen weiterhin ~325 V.
- **Differenztastkopf** (oder galvanisch getrenntes Oszilloskop) für jede primärseitige Scope‑Messung. Sonst gilt die Masse‑Regel oben.
- **C2 entladen vor jeder Arbeit.** Der 47‑µF‑Elko hält nach dem Abschalten gefährliche Ladung. Über einen Widerstand (~10 kΩ / 5 W) entladen, dann mit dem Multimeter auf **< 30 V** prüfen — erst dann anfassen.
- **Erst‑Einschalten über Reihen‑Glühlampe** („Dim‑Bulb‑Tester", 40–100 W in Reihe zum Netz): begrenzt den Strom bei einem Kurzschluss. Lampe leuchtet dauerhaft hell = Kurzschluss; kurz hell, dann dunkel = normal.
- **Einhand‑Regel**, isoliertes Werkzeug, trockener Standplatz, **nie allein** arbeiten.
- Bauteile können **heiß** sein (Q1, Trafo, D2, R1).

---

## 🧰 Ausrüstung

| Gerät | Wofür |
|---|---|
| Trenntransformator (ideal: regelbar / Stelltrafo) | netzbezugsfreies Arbeiten unter Spannung |
| Differenztastkopf + Oszilloskop | Gate‑, Drain‑, CS‑, FB‑Signale primärseitig |
| Digital‑Multimeter (True‑RMS, Dioden-/Ω‑Bereich) | statische Bauteiltests, DC‑Pegel |
| Reihen‑Glühlampe (Dim‑Bulb‑Tester) | Strombegrenzung beim ersten Einschalten |
| Entladewiderstand ~10 kΩ / 5 W | C2 sicher entladen |
| ESR‑Messgerät | Elkos C2 / C6 / C3 bewerten (im ausgebauten/entladenen Zustand) |
| Elektronische Last oder Lastwiderstände | Verhalten unter Last, Regelung prüfen |

---

## 🟢 Teil A — Statische Prüfung (spannungsfrei, C2 entladen)

Multimeter im **Dioden-/Ω‑Bereich**. Deckt die häufigsten Totalausfälle ab, bevor überhaupt Netz angelegt wird.

| Prüfling | Messung | Sollwert / Befund | Deutung bei Abweichung |
|---|---|---|---|
| **F1** | Durchgang | ~0 Ω | unterbrochen → Folgefehler (oft Q1/BR1‑Kurzschluss) suchen |
| **BR1** | 4 Dioden vorwärts/rückwärts | je ~0,4–0,6 V vorwärts, sperrt rückwärts | Kurzschluss → Ursache für durchgebrannte F1 |
| **Q1 (7N65)** | D–S, G–S, G–D | D–S sperrt beidseitig (mit Bodydiode 1 Richtung); G isoliert | ==D–S niederohmig = MOSFET durchlegiert== (klassischer Defekt) |
| **R2** | Widerstand | 10 Ω | hochohmig/offen → kein CS‑Signal, Q1 ungeschützt |
| **R1** | Widerstand | 100 kΩ | offen → kein Anlauf (keine VCC) |
| **D1 / D2** | Diodentest | Durchlass ~0,3 V (D2 Schottky) / ~0,6 V (D1) | Kurzschluss D2 → Ausgang tot / Hiccup |
| **C2 / C6 / C3** | Sichtprüfung + ESR | keine Wölbung, niedriger ESR | aufgebläht/hoher ESR → Ripple, Anlaufprobleme |
| **PC817‑LED** | Diodentest (Pins 1–2) | Durchlass ~1,0–1,2 V | offen → Regelkreis unterbrochen → Überspannung |
| **R8 / R9** | Widerstand | 2,2 kΩ / 1 kΩ | Drift → falsche Ausgangsspannung |

---

## 🟠 Teil B — Messungen unter Spannung (Trenntrafo + Differenztastkopf!)

Reihenfolge nach dem Ablauf‑Diagramm unten. Netz **über den Dim‑Bulb‑Tester** zuschalten.

| Messpunkt | Gerät | Sollwert | Deutung bei Abweichung |
|---|---|---|---|
| **C2 (Zwischenkreis)** | DMM DC, Ref. Primärmasse | ~300–325 V DC | kein/zu niedrig → Eingang, BR1, NTC, C2, Last/Kurzschluss |
| **VCC / VDD am OB2263** | Scope, Ref. Primärmasse | steigt auf Einschaltschwelle (~16 V), dann stabil aus Hilfswicklung | ==sägezahnartig pulsierend (2–16 V) = Hiccup== → Überlast, Kurzschluss sekundär, offener Regelkreis oder fehlende Hilfsversorgung |
| **Gate von Q1** | Differenztastkopf | Rechteck, ~65 kHz, ~10–18 V | kein Signal → Controller startet nicht (VCC/UVLO); Dauer‑High/Low → Defekt |
| **Drain von Q1** | Differenztastkopf | Schaltflanken; Spitze = Bus + reflektiert + Leck‑Spike | ==Spitze nahe/über 650 V== → Snubber fehlt/defekt, Q1 gefährdet |
| **CS‑Pin (an R2)** | Differenztastkopf | Sägezahn je Takt, Spitze an der Strombegrenzung (~0,5–1 V) | flach/0 → R2 offen; ständig am Limit → Überlast/Trafo/Kurzschluss |
| **FB‑Pin** | Differenztastkopf | DC ~1–3 V im Regelbetrieb | ~0,75 V = Duty→0 (Überspannung sekundär?); dauerhaft hoch = offener Regelkreis → volle Leistung |
| **+12 V Ausgang** | DMM DC + Scope AC, Ref. Sekundärmasse | 12 V ±5 %, Ripple < ~100 mVpp | zu niedrig/instabil → Regelkreis/Last/C6; zu hoch → Regelkreis offen |
| **C6 Ripple** | Scope AC‑Kopplung | einige 10 mVpp | großer Ripple/Brumm → C6 Kapazität/ESR, D2 |
| **TL431 REF** | DMM, Ref. Sekundärmasse | ~2,5 V bei Regelung | ≠ 2,5 V → TL431 oder Teiler R8/R9 defekt |

> 💡 **Massebezug beachten:** Sekundärmessungen (Ausgang, TL431) referenzieren die **Sekundärmasse** (sicher, isoliert) — hier genügt ein normaler Tastkopf. Primärmessungen (C2, VCC, Gate, Drain, CS, FB) referenzieren die **Primärmasse** (netzbezogen) — nur mit Differenztastkopf.

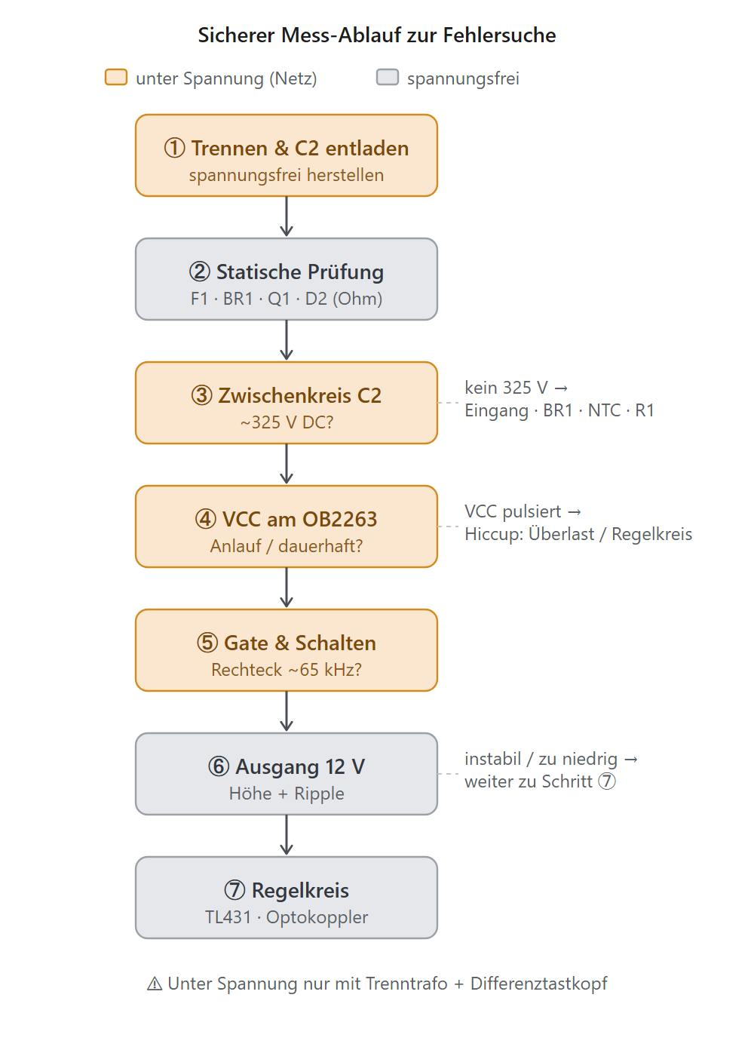
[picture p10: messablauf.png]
Sicherer Mess-Ablauf zur Fehlersuche


---

## 🔎 Symptom → Ursache (Schnelldiagnose)

| Symptom | Wahrscheinliche Ursachen | Zuerst prüfen |
|---|---|---|
| **Völlig tot, keine VCC** | F1 offen, BR1/Q1 kurz, C2 defekt, R1 offen, OB2263 defekt | Teil A + C2 |
| **Tickt/pfeift, Ausgang bricht ein (Hiccup)** | Überlast/Kurzschluss sekundär, D2 kurz, C6 kurz, offener Regelkreis (Opto/TL431) | VCC‑Verlauf, D2, Opto |
| **Ausgang zu hoch** | Regelkreis offen: PC817‑LED, TL431, R8/R9 | FB‑Pin, Opto, TL431 |
| **Ausgang zu niedrig / bricht unter Last ein** | C2‑ESR, C6‑ESR, D2, schwache Regelung | ESR C2/C6, D2 |
| **Hoher Ripple / Brummen** | C6 (Kapazität/ESR), D2 | Ripple am Ausgang |
| **F1 schwarz durchgebrannt** | primärer Kurzschluss: Q1, BR1, C2 | Teil A statisch |
| **Q1 wird sehr heiß** | Snubber fehlt/defekt, Überlast, hoher Schaltverlust | Drain‑Spitze, Last |

---

## 🧪 Praxistipps

- **Hiccup verstehen:** Ein periodisches „Ticken" mit auf‑ und abschwellender VCC ist der Auto‑Restart‑Schutz des OB2263. Er zeigt: Der IC *will*, aber etwas belastet den Ausgang oder die Rückkopplung fehlt. Das ist ein **Symptom**, keine Ursache.
- **Regelkreis gezielt testen:** Ausgang leicht belasten und beobachten, ob FB reagiert. Reagiert FB nicht auf Laständerung → Opto/TL431‑Pfad unterbrochen.
- **Leerlauf‑Pfeifen** bei sehr kleiner Last ist oft der Burst-/Sparbetrieb — meist normal, kein Defekt.
- **Erst hochfahren, dann belasten:** Mit Stelltrafo langsam hochregeln, dabei C2 und den Dim‑Bulb beobachten — so erkennt man Kurzschlüsse, bevor etwas abraucht.
- **Immer wieder entladen:** Nach jedem Abschalten C2 erneut entladen und nachmessen, bevor du greifst.

---

## 🎯 Fazit

Die Fehlersuche folgt einem klaren Pfad: **erst spannungsfrei** die üblichen Verdächtigen (F1, BR1, Q1, D2) ausschließen, dann **unter Spannung** entlang der Signalkette C2 → VCC → Gate → Ausgang messen — und Auffälligkeiten mit der Symptomtabelle verknüpfen. Der wichtigste Satz bleibt: ==Primärseite = Netzpotential; unter Spannung nur mit Trenntrafo und Differenztastkopf.==

---



*Erstellt: 2026‑07‑11 · OB2263‑Sperrwandler · Mess- & Fehleranalyse · erarbeitet mit Claude Code (Opus 4.8) + Rw*

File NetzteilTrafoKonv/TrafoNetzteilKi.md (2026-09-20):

# Ein symmetrisches Trafo-Netzteil verstehen — MOSFET-Vorregler + 78xx/79xx

*Warum zwischen Gleichrichter und Festspannungsregler noch ein Leistungs-MOSFET sitzt — ein Werkstattbericht*

> **Kurzfassung:** Die Schaltung ist ein ==klassisches symmetrisches Linearnetzteil== mit zwei Netztrafos, deren Sekundärwicklungen in Reihe liegen; der Mittelpunkt ist Masse. Eine einzige Brücke erzeugt daraus **±33 V Rohspannung**. Das Besondere ist die Stufe dazwischen: je ein **MOSFET als Source-Folger** (IRF640 / IRF9530) arbeitet als *Kapazitätsvervielfacher* und *Spannungsdeckel*. Er siebt den 100-Hz-Brumm praktisch vollständig weg und begrenzt die Eingangsspannung der nachfolgenden **78xx/79xx**-Regler auf ~25 V — ohne diesen Deckel würden die Regler im Leerlauf mit 37 V über ihrer zulässigen Eingangsspannung betrieben.

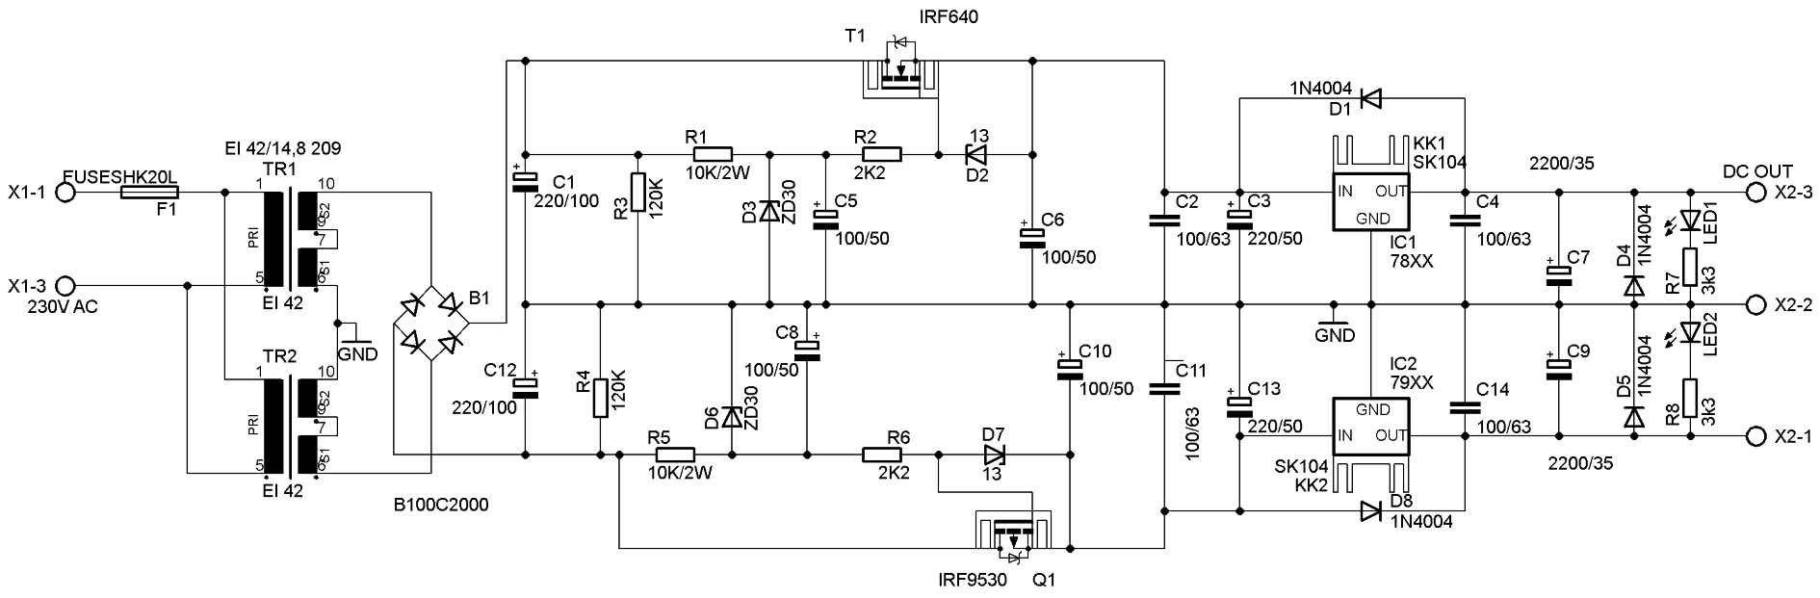
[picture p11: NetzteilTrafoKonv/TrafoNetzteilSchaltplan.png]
Schaltplan des symmetrischen Trafo-Netzteils


---

## 🧭 Ausgangslage — was liegt auf dem Tisch?

Ein Netzteil, das aus 230 V~ eine **symmetrische Gleichspannung** macht: eine positive und eine gleich große negative Schiene gegen eine gemeinsame Masse. So etwas braucht man überall dort, wo Operationsverstärker, Analogschaltungen oder Messverstärker versorgt werden sollen — die brauchen beide Polaritäten.

Im Gegensatz zum [Sperrwandler](../NetzgeraetKi.md) arbeitet hier **nichts getaktet**. Es gibt keinen Controller, keinen Optokoppler, keine Regelschleife im eigentlichen Sinn. Alles ist ==analog, stetig und langsam== — und genau deshalb ist die Schaltung so gutmütig: kein HF-Dreck, kein Layout-Drama, keine Streuinduktivität.

Die Schaltung zerfällt in **vier Stufen**, die die Spannung schrittweise abbauen:

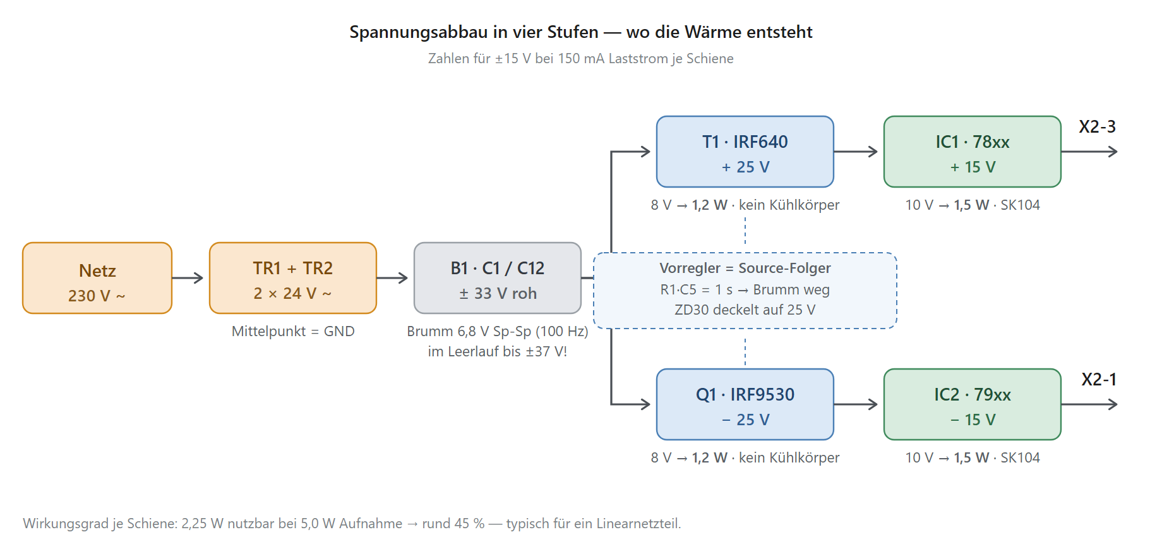
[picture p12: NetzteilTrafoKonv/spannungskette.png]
Spannungsabbau in vier Stufen


---

## 🔌 Stufe 1 — Zwei Trafos, eine Brücke, ein Mittelpunkt

**TR1 und TR2** (EI 42/14,8, je rund 5–6 VA) hängen mit ihren **Primärwicklungen parallel** am Netz. Bei beiden sind die zwei Sekundärwicklungen über **Pin 7 in Reihe** geschaltet — aus 2 × 12 V werden also je 24 V.

Der Trick steckt in der Verschaltung der beiden Trafos:

| Knoten | Verbindung |
|---|---|
| TR1 Pin 10 | → Brücke B1, Wechselstrom-Eingang 1 |
| TR1 unten **+** TR2 Pin 10 | → **GND** (der Mittelpunkt) |
| TR2 unten | → Brücke B1, Wechselstrom-Eingang 2 |
| B1 `+` → C1 → GND | positive Rohschiene |
| B1 `−` → C12 → GND | negative Rohschiene |

> 🔑 **Warum das elegant ist:** Beide Sekundärwicklungen liegen in Reihe, die Brücke sieht die Summe (48 V~) — aber weil der Mittelpunkt auf Masse liegt, teilt sich das Ergebnis in zwei symmetrische Schienen auf. Der Strompfad geht dabei jeweils nur über **eine** Diode, nicht über zwei. Das spart einen Diodenabfall gegenüber zwei getrennten Brücken.

$$U_{roh} \approx U_{sek} \cdot \sqrt{2} - 0{,}9\,\text{V} \quad \text{je Schiene, Brummfrequenz 100 Hz}$$

Konkret mit 24 V Sekundärspannung:

| Betriebsfall | Ergebnis |
|---|---|
| Nennlast (~150 mA) | **± 33 V** |
| Leerlauf (kleine Trafos haben +10…15 % Überspannung) | **± 37 V** ⚠️ |

Und genau dieser Leerlaufwert ist der Grund für die ganze nächste Stufe: ==ein 7815 verträgt nur 35 V am Eingang==.

**C1 / C12 (220 µF/100 V)** sind die Ladeelkos, **R3 / R4 (120 k)** die Symmetrier- und Entladewiderstände darüber. Letztere ziehen 0,27 mA und entladen die Elkos nach dem Abschalten mit τ = 26 s — nach gut zwei Minuten ist die Schaltung spannungsfrei.

---

## 🎚️ Stufe 2 — Das Herzstück: der MOSFET-Vorregler

Beide Schienen sind spiegelbildlich aufgebaut. Für die positive Seite: **R1, D3, C5, R2, D2 und T1 (IRF640)**; negativ dasselbe mit **R5, D6, C8, R6, D7 und Q1 (IRF9530)**.

**T1 arbeitet als Source-Folger:** Drain an der Rohspannung, Source am Eingang des 78xx. Der Ausgang folgt dem Gate — abzüglich der Gate-Source-Spannung:

$$U_{vor} = U_{Gate} - U_{GS} \approx U_{Gate} - 4\,\text{V}$$

Die ganze Kunst steckt darin, **wie die Gate-Spannung erzeugt wird**.

### 🧊 R1 + C5 — der Kapazitätsvervielfacher

R1 (10 k) und C5 (100 µF) bilden einen Tiefpass mit der Zeitkonstante

$$\tau = R_1 \cdot C_5 = 10\,\text{k}\Omega \cdot 100\,\mu\text{F} = \mathbf{1\ Sekunde}$$

Gegenüber der Brummperiode von 10 ms ist das der **Faktor 100**. Am Gate steht damit praktisch reine Gleichspannung — und weil der Source ihr folgt, ist auch die Ausgangsspannung der Stufe brummfrei. Das Gate zieht dabei keinen Strom, der große Widerstand kostet also nichts.

> 💡 **Der Clou:** C5 mit seinen 100 µF wirkt am Ausgang so, als hinge dort ein Elko von *C5 × Stromverstärkung* — bei einem MOSFET also praktisch unendlich groß. Man bekommt die Siebwirkung eines riesigen Elkos für 10 Cent. Deshalb der Name **Kapazitätsvervielfacher**.

### 🧢 D3 (ZD30) — der Deckel, nicht die Referenz

Hier wird gern falsch gelesen: Die 30-V-Z-Diode ist **keine Referenz, die den Arbeitspunkt bestimmt**, sondern eine **obere Begrenzung**.

- Solange U_roh unter 30 V liegt, sperrt D3 und C5 lädt sich einfach auf den **Mittelwert** der Rohspannung auf.
- Steigt U_roh darüber (Leerlauf, Netzüberspannung), klemmt D3 das Gate bei ~30 V fest.

$$U_{vor} = \min\left(\overline{U_{roh}}\ ;\ U_{Z}\right) - U_{GS} \approx \mathbf{25\ V}$$

Damit ist garantiert, dass der 78xx **nie** mehr als ~25 V am Eingang sieht — auch nicht ohne Last. Das ist die eigentliche Existenzberechtigung der Stufe.

### 🛡️ R2 und D2 — zwei kleine Bauteile, zwei echte Probleme gelöst

**R2 (2k2) ist der Gate-Stopper.** Mit der Eingangskapazität des IRF640 (C_iss ≈ 1,3 nF) ergibt das ein RC-Glied von rund 3 µs. Source-Folger mit steilen Leistungs-MOSFETs neigen an kapazitiver Last zum **HF-Schwingen** — der Gate-Widerstand bedämpft das zuverlässig. Ein Detail, das in vielen Nachbauten fehlt und dann stundenlanges Rätselraten am Oszilloskop verursacht.

**D2 (Z-Diode 13 V) schützt die Gate-Source-Strecke.** Im Normalbetrieb liegt U_GS bei ~4 V, die Diode tut nichts. Bei einem **Ausgangskurzschluss** wird der Source aber auf Masse gezogen — dann läge die volle Gate-Spannung von 30 V über Gate-Source. Der IRF640 verträgt nur ±20 V, das Gate-Oxid würde sofort durchschlagen. D2 klemmt bei 13 V. ==Ohne diese Diode ist die Schaltung nicht kurzschlussfest.==

### 🐣 Sanftanlauf — gratis dazu

Beim Einschalten lädt C5 über R1 mit τ = 1 s. Das Gate fährt also langsam hoch, der Source folgt, und der Ausgang erreicht seinen Endwert erst nach etwa **3 Sekunden**. Damit entfällt der sonst übliche Einschaltstromstoß in die 2200-µF-Elkos am Ausgang — ein Nebeneffekt, den man sonst mit zusätzlicher Schaltung erkaufen müsste.

---

## 🧱 Stufe 3 — Die Festspannungsregler

| Bauteil | Funktion |
|---|---|
| **IC1 78xx / IC2 79xx** auf **SK104** | die eigentliche Spannungsregelung |
| **C2, C3, C11, C13** | Eingangspufferung |
| **C4, C14 (100 µF) + C7, C9 (2200 µF)** | Ausgangssiebung; deckt zugleich die Stabilitätsforderung des 79xx ab |
| **D1, D8 (1N4004)** | Rückstromschutz OUT → IN. Bei 2200 µF am Ausgang **Pflicht**: beim Abschalten darf der Ausgang nicht über den Eingang steigen ✔ |
| **D4, D5 (1N4004)** | Schutz gegen Verpolung und gegen das Durchziehen der Gegenschiene bei induktiven oder unsymmetrischen Lasten ✔ |
| **R7, R8 (3k3) + LED1, LED2** | Betriebsanzeige, ~3,9 mA bei 15 V |

> ⚠️ **Die „XX" sind Platzhalter.** Der Schaltplan legt sich nicht fest. Aus U_vor ≈ 25 V und den 3k3-LED-Vorwiderständen ergibt sich als sinnvoller Bereich **±12 V oder ±15 V**. ±24 V ginge nicht mehr — der Spannungsabstand (Dropout) reicht nicht.

---

## 🌡️ Wärmebilanz — wo die Verluste bleiben

Bei ±15 V und 150 mA je Schiene:

| Bauteil | Spannungsabfall | Verlustleistung | Kühlung im Plan |
|---|---|---|---|
| T1 / Q1 (MOSFET) | 33 → 25 V = **8 V** | **1,2 W** | ❌ keine |
| IC1 / IC2 (Regler) | 25 → 15 V = **10 V** | **1,5 W** | ✔ SK104 |
| Nutzleistung | | 2,25 W | |

Wirkungsgrad rund **45 %** — für ein Linearnetzteil völlig normal. Der Sinn der Vorstufe ist genau diese **Aufteilung der Wärme auf zwei Bauteile** statt auf eines.

Der Laststrom ist übrigens nicht vom 78xx (1 A) begrenzt, sondern von den Trafos: bei ~6 VA und Ladeelko-Betrieb sind realistisch **100–150 mA je Schiene** entnehmbar.

---

## ⚠️ Befunde — was ich vor dem Aufbau ändern würde

### ① T1 und Q1 haben keinen Kühlkörper

Der klarste Schwachpunkt. Ein freistehendes TO-220 hat rund 62 K/W; 1,2 W bedeuten schon im Normalbetrieb **+75 K Übertemperatur**. Schlimmer im Fehlerfall: Bei Ausgangskurzschluss begrenzt der 78xx auf ~1,5 A — dann liegen am MOSFET 33 V × 1,5 A = **50 W** an, bis der Trafo einbricht. Die Vorstufe hat *keine eigene Strombegrenzung*.

> 🔧 **Abhilfe:** Kühlkörper an T1/Q1 (mindestens SK129 o. ä.) — oder eine einfache Strombegrenzung mit Source-Widerstand und BC547 ergänzen. Kurios ist die jetzige Verteilung: die Bauteile mit dem *kleineren* Verlustanteil haben Kühlkörper, die MOSFETs nicht.

### ② C1 / C12 mit 220 µF sind zu klein

$$\Delta U = \frac{I}{f \cdot C} = \frac{0{,}15\,\text{A}}{100\,\text{Hz} \cdot 220\,\mu\text{F}} \approx \mathbf{6{,}8\ V_{SS}}$$

Damit rutscht die Untergrenze der Rohspannung auf ~30 V — knapp an der Grenze, ab der dem Source-Folger der Spannungsabstand ausgeht. Die 100 V Spannungsfestigkeit sind dagegen unnötig (es liegen 33 V an).

> 🔧 **Abhilfe:** **1000 µF / 63 V** statt 220 µF / 100 V. Etwa gleiche Baugröße, ein Drittel des Brumms, echte Reserve.

### ③ Es fehlen keramische Abblockkondensatoren

Die Datenblätter der 78xx/79xx verlangen 0,33 µF am Eingang und 0,1 µF am Ausgang, **möglichst dicht an den Pins**. Im Plan stehen nur Elkos. Reine Elkos an längeren Leiterbahnen provozieren HF-Schwingen — beim 79xx besonders gern.

> 🔧 **Abhilfe:** je 100 nF Keramik direkt an IN/GND und OUT/GND beider Regler.

### ④ Kein Schutzleiter im Plan

X1 führt nur L und N. Bei einem Metallgehäuse ist **PE Pflicht** (Schutzklasse I). Nur zulässig, wenn Kunststoffgehäuse *und* schutzisolierte Trafos nach EN 61558 verwendet werden — dann bitte im Plan vermerken.

### ⑤ F1 ohne Wert

„HK20L" bezeichnet nur den Halter (5 × 20 mm). Bei 2 × 6 VA fließen primär rund 55 mA → **T 100 mA bis T 160 mA, träge**.

### ⑥ R1 / R5 mit 2 W massiv überdimensioniert

Es fallen dort nur ~2 mW an. Unkritisch, kostet nur Platz auf der Platine.

### ⑦ Aufbau-Fallstrick Nr. 1: die Wicklungsphase

Die vier Sekundärwicklungen müssen **phasenrichtig** in Reihe liegen. Falsch herum heben sie sich gegenseitig auf.

> 🔧 **Prüfung:** Vor dem Einlöten der Brücke die Trafos anschließen und die Serienschaltung im **AC-Bereich** messen. Erwartet werden ~24 V je Trafo und **~48 V über die Gesamtreihe**. Kommen 0 V oder 24 V heraus, ist eine Wicklung verdreht.

---

## 🔎 Inbetriebnahme — der Messplan

Erst ohne Last, dann mit je 100 Ω Lastwiderstand pro Schiene:

| Messpunkt | Erwartung | Alarmzeichen |
|---|---|---|
| Sekundär AC über die Gesamtreihe | ~48 V~ | 0 V oder 24 V → **Phase falsch** |
| C1 / C12 gegen GND | ±37 V leer, ±33 V bei Last | > 45 V → falscher Trafo |
| C5 / C8 (Gate-Referenz) | ~28–29 V DC, **brummfrei** | Brumm sichtbar → C5 defekt |
| Source T1 / Q1 (= Reglereingang) | ± 24…26 V | **> 35 V → ZD30 prüfen!** |
| X2-3 / X2-1 gegen X2-2 | ± U_nenn, ±4 % | |
| Ausgangsbrumm (AC-gekoppelt) | < 1 mV_SS | > 10 mV → Regler schwingt, siehe Befund ③ |

> 💡 Eine kleine Asymmetrie zwischen den Schienen ist **normal**: der IRF9530 (P-Kanal) hat eine etwas höhere U_GS als der IRF640. Der 79xx fängt das auf.

---

## 📋 Bauteilübersicht

| Gruppe | Bauteile | Aufgabe |
|---|---|---|
| Netzeingang | F1, X1 | Absicherung, Anschluss |
| Trafos | TR1, TR2 (EI 42/14,8) | Trennung + Spannungswandlung, Mittelpunkt = GND |
| Gleichrichtung | B1 (B100C2000), C1, C12, R3, R4 | ±33 V roh, Siebung, Entladung |
| Vorregler **+** | R1, D3 (ZD30), C5, R2, D2 (13 V), T1 (IRF640), C6 | Brummsiebung + Spannungsdeckel |
| Vorregler **−** | R5, D6 (ZD30), C8, R6, D7 (13 V), Q1 (IRF9530), C10 | dito, gespiegelt |
| Regler **+** | C2, C3, IC1 (78xx/SK104), D1, C4, C7 | Festspannung, Rückstromschutz |
| Regler **−** | C11, C13, IC2 (79xx/SK104), D8, C14, C9 | dito, gespiegelt |
| Ausgang | D4, D5, R7, R8, LED1, LED2, X2 | Schutzdioden, Anzeige, Klemmen |

---

## 🧾 Was man aus dieser Schaltung lernen kann

1. **Ein Source-Folger ist ein Filter.** Ein einziger MOSFET plus RC-Glied ersetzt einen riesigen Siebelko — und kostet fast nichts.
2. **Z-Dioden sind nicht immer Referenzen.** Die ZD30 hier arbeitet als Obergrenze, nicht als Sollwertgeber. Wer das verwechselt, rechnet die Schaltung falsch.
3. **Wärme teilt man auf.** Zwei Bauteile mit je 1,5 W sind leichter zu kühlen als eines mit 3 W — das ist der eigentliche Grund für die zweistufige Regelung.
4. **Zwei kleine Trafos schlagen einen großen mit Mittelanzapfung**, wenn man gerade zwei gleiche in der Kiste hat. Die Brücke-mit-Mittelpunkt-Schaltung macht daraus eine saubere symmetrische Versorgung.

---

## ⚖️ Rechte & Quellen

- **Eigene Inhalte** (Analysetext, Diagramm `spannungskette.svg/.png`): © Reinhard Wermeling (RwTec), erarbeitet mit Claude Code.
- ⚠️ **`TrafoNetzteilSchaltplan.png`** — Herkunft des Schaltbilds vor einer Veröffentlichung prüfen. Falls fremd, durch eine eigene Nachzeichnung (KiCad) ersetzen.
- Die Sekundärspannung der Trafos (hier mit 2 × 12 V angenommen) ist im Schaltplan **nicht angeschrieben**. Alle Spannungs- und Verlustangaben in diesem Bericht folgen aus dieser Annahme und sind am Aufbau nachzumessen.

---

*Werkstattbericht · RwTec · 2026 · erstellt mit Claude Code*

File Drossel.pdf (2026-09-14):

## In Schaltnetzteilen haben Drosseln (Spulen) vor allem zwei Hauptaufgaben: Sie speichern Energie und sie filtern unerwünschte

Störungen.

## Da Schaltnetzteile Strom sehr schnell ein- und ausschalten, entsteht ein unruhiger Stromfluss. Die Drossel wirkt hier wie ein Stoßdämpfer

für die Elektrizität.

## Die Hauptaufgaben einer Drossel

Je nachdem, wo die Drossel im Netzteil sitzt, übernimmt sie eine andere Funktion:

## 1. Als Energiespeicher (Speicherdrossel)

Wo: Im Herzstück des Netzteils (z. B. bei Abwärtsreglern).
Funktion: Wenn der Schalter im Netzteil an ist, baut die Drossel ein Magnetfeld auf und speichert Energie. Wird der Schalter ausgeschaltet, bricht das Magnetfeld zusammen. Die Drossel gibt die gespeicherte Energie an den Ausgang ab.
Ziel: Sie sorgt dafür, dass am Ende ein gleichmäßiger Strom fließt, obwohl drinnen ständig geschaltet wird.

## 2. Als Filter gegen Störungen (Filterdrossel / Funkentstördrossel)

Wo: Direkt am Stromeingang (230V-Seite) oder am Ausgang.
Funktion: Das schnelle Schalten erzeugt hochfrequente Störungen (Elektrosmog). Eine Drossel blockiert hohe Frequenzen (Wechselstrom), lässt aber glatten Strom (Gleichstrom oder 50-Hz-Netzstrom) ungehindert durch.
Ziel: Sie verhindert, dass das Netzteil andere Geräte stört oder Störungen aus dem Stromnetz in das Netzteil gelangen. Often findet man hier sogenannte „Stromkompensierte Drosseln“.

## Ein einfacher Vergleich (Analogie)

Stellen Sie sich Strom wie Wasser vor, das durch ein Rohr fließt:

Das Schaltnetzteil ist ein Wasserhahn, den jemand schnell auf- und zudreht. Das Wasser würde nur in harten Stößen herausspritzen.
Die Drossel ist wie ein schweres Wasserrad im Rohr.
Wenn das Wasser spritzt, bremst das Rad den ersten harten Stoß ab (Energie speichern). Wenn der Hahn zu ist, dreht sich das schwere Rad durch Schwung weiter und schiebt das Wasser weiter voran (Energie abgeben).
Am Ende fließt das Wasser gleichmäßig und ruhig heraus.

## Übersicht der Drossel-Typen im Netzteil

Drossel-Typ | Typischer Einbauort | Hauptziel
Netzdrossel / EMI- Filter | Direkt am Stromeingang | Blockiert Störsignale in beide Richtungen
Speicherdrossel | Nach dem Schalt-Transistor | Wandelt abgehackten Strom in glatten Strom um
Ausgangsdrossel | Direkt vor dem Stromausgang | Siebt letzte Restwelligkeit ("Rippel") aus

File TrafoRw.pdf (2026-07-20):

# 1. Einleitung und Historie

Der Flyback-Wandler (Sperrwandler) gehört zu den am weitesten verbreiteten Topologien für Schaltnetzteile. Kommerziell wird diese Technologie seit den 1940er und 1950er Jahren genutzt. Ihr ursprünglicher Einsatzbereich lag in Röhrenfernsehern, wo der Flyback-Transformator (Zeilentransformator) die extrem hohen Spannungen für die Bildröhre generierte. Mit dem Aufkommen moderner Leistungshalbleiter (MOSFETs) in den 1970er Jahren wandelte sich das Einsatzgebiet hin zu kompakten, hocheffizienten Netzteilen.

# 2. Funktionsprinzip und Besonderheiten

Entgegen einem klassischen Netztransformator überträgt der Flyback-Transformator die elektrische Energie nicht sofort, sondern arbeitet als gekoppelte Speicherdrossel:

1. Leitphase (Ein): Der primärseitiger Schalter schießt. Energie baut sich im Magnetfeld auf. Die sekundundärseitige Diode sperrt.
2. Sperrphase (Aus): Der Schalter oeffnet. Das Magnetfeld bricht zusammen und induziert eine Spannung. Die Diode leitet und die Energie wird zeitversetzt an den Ausgang abgegeben.
Um eine magnetische S'e4ttigung des Kerns zu verhindern und eine hohe Energiespeicherung zu erm'f6glichen, besitzt der Kern fast immer einen definierten Luftspalt.

# 3. Mathematische Zusammenhänge (Dimensionierung)

Die Ausgangsspannung ( | ) wird nicht allein durch das Windungsverhältnis ( | )
bestimmt, sondern maßgeblich durch den Tastgrad ( ) des Schalters gesteuert:

Spannungsbelastung: Beim oeffnen des Schalters entsteht eine reflektierte Spannung (

) auf der Primärseite. Der Halbleiterschalter muss so dimensioniert sein, dass er die
Summe aus Eingangsspannung und reflektierte Spannung ( | ) sicher blockieren
kann.
U{out} | n = NP /NS
D

U{out} = U{

in}
cdot
frac{1}{n}
cdot
frac{D}{1 − D}

U{ref} = n
cdotU{out}
U{

in} + U{ref}

# 4. Wicklungsdesign und Querschnitte

Wegen der unterschiedlichen Spannungs- und Stromniveaus sind Primär- und Sekundundärseite asymmetrisch dimensioniert:

Leiterquerschnitt ( ): Bestimmt sich 'fcber den effektiven Strom ( | ) und die zul'e4ssige
Stromdichte ( , praxisnah bis
) nach der Formel: | .
Skin-Effekt: Da Flyback-Wandler bei hohen Frequenzen (
bis 'fcber
) arbeiten, verdr'e4ngt der Skin-Effekt den Strom an die Drahtoberfläche. Praktische Umsetzung: Dicke Einzeldr'e4hte werden vermieden. Stattdessen kommen mehrere parallel gewickelte, d'fcnne Dr'e4hte oder flexible HF-Litzen (B'fcndel isolierter Einzeladern) zum Einsatz, um den Innenwiderstand und die Erw'e4rmung zu minimieren.

# 5. Heutige Haupteinsatzgebiete

Aufgrund der geringen Bauteilanzahl, der galvanischen Trennung und der kosteng'fcnstigen Produktion ist der Flyback-Transformator heute der Standard f'fcr kleine bis mittlere Leistungen (bis ca. 150 Watt):

Steckernetzteile und Ladeger'e4te (Smartphones, Laptops)
Hilfs- und Standby-Stromversorgungen in Haushaltsger'e4ten und PCs
Treiberstufen f'fcr LED-Beleuchtungen
Kompakte Stromversorgungen in der Industrie- und Automobiltechnik

# Anhang: Stückliste ein Flyback-Beispielnetzteil

## Spezifikation des Referenzdesigns:

Eingangsspannung ( | ): 9 V bis 16 V DC (Nennwert: 12 V)
Ausgangsspannung ( | ): 2,67 V DC (geregelt)
Ausgangsstrom ( | ): Max. 3 A (

auf der SekundundärSeite)
Schaltfrequenz ( ): 100 kHz

A I{RMS}
J | 3 | 5
text{A/mm}

### 2 A = I{RMS}/J

50
text{kHz} | 300
text{kHz}

U{

in}
U{out}
I{out} | I{RMS}
approx3
text{A}
f{sw}

Bauteil-ID | Komponente | Beschreibung / Technische Daten | Menge | Geh'e4useform / Typ
TR1 | Flyback-Transformator | Kern: Ferrit (z. B. EF20 oder E25/13/7) Luftspalt: ca. 0,2 mm Windungsverh'e4ltnis (n): NP = 18 NS = 6 3:1 ( , ) Prim'e4rdraht: 1'd7 0,4 mm Kupferlackdraht Sekund'e4rdraht: HF-Litze 24'd7 0,2 mm (wegen Skin-Effekt) | 1 | E-Kern horizontal / Kundenspezifisch
IC1 | PWM-Controller | Current-Mode Flyback-Controller mit fester Frequenz (100 kHz), integrierter Unterspannungssperre und Sanftanlauf. | 1 | SOIC-8 (z. B. UC384x-Serie oder LM5021)
Q1 | Leistungsschalter (MOSFET) | N-Kanal MOSFET Spannungsfestigkeit: \f1\u8805?\f0 30 V (berechnet: 20 V + Sicherheitsreserve) Strombelastbarkeit: \f1\u8805?\f0 6 A Niedriger Einschaltwiderstand ( R{DS(on)} < 10 text{m} ) Omega | 1 | TO-220 oder DPAK
D1 | Ausgangsdiode | Schottky-Diode (f'fcr schnelles Schalten bei 100 kHz) Sperrspannung: \f1\u8805?\f0 20 V Dauerstrom: \f1\u8805?\f0
1 | TO-220AC oder
SMC

Bauteil-ID | Komponente | Beschreibung / Technische Daten | Menge | Geh'e4useform / Typ
| | 5 A (z. B. wegen Anlaufstr'f6men)
C_IN | Eingangskondensator | Elektrolytkondensator (Low-ESR) Kapazit'e4t: 470 'b5F / Spannungsfestigkeit: 25 V | 1 | Radial, durchsteckbar (PTH)
C_OUT | Ausgangskondensator | Elektrolytkondensator (Low-ESR) zur Gl'e4ttung der pulsierenden Sperrwandler-Str'f6me. Kapazit'e4t: 1000 'b5F / Spannungsfestigkeit: 6,3 V | 1 | Radial, durchsteckbar (PTH)
R_SENSE | Strommesswiderstand | Shunt-Widerstand zur 'dcberwachung des Prim'e4rstroms ('dcberlastschutz). Wert: 0,1 \f2\lang1032'd9 / Leistung: 0,5 W | 1 | SMD 1206 oder Metallschicht
IC2 | Spannungsregler / Optokoppler | Zur galvanisch getrennten R\f0\lang1033'fcckf'fchrung des Ausgangssignals an den Controller IC1. Bestehend aus Referenz-IC (z. B. TL431) und Optokoppler. | 1 | DIP-4 / SOT-23
R1, C1 | Snubber-Netzwerk (RCD) | Bed'e4mpft die zerst'f6rerischen Spannungsspitzen beim Ausschalten von Q1. R: 1 k\f2\lang1032'd9 (1 W), C: 2,2 nF (100 V), D: Schnelle Diode (z. B. 1N4148) | 1 Set | SMD 1206 / DO-35

## Design-Hinweise zur St\f0\lang1033'fcckliste:

1. Der Transformator (TR1): Da es Flyback-Transformatoren selten als Standardbauteil von der Stange gibt, wird er f'fcr das jeweilige Projekt basierend auf dem Kernmaterial (Ferrit) und den berechneten Drahtquerschnitten (HF-Litze sekund'e4r) meist selbst gewickelt oder als Custom-Bauteil bestellt.
2. Die Kondensatoren (C_IN / C_OUT): Wegen der hohen Schaltfrequenz und Rippelstr'f6me m'fcssen unbedingt Low-ESR-Typen (geringer Innenwiderstand) verwendet werden, da Standard-Elkos sonst überhitzen.

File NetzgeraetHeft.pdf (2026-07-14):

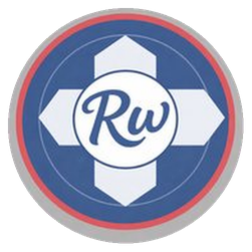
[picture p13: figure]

R W T E C · W E R K S T A T T B E R I C H T

# Netzteil Verstehen

Ein 12-V-Schaltnetzteil verstehen,

## prüfen & simulieren

Isolierter Sperrwandler mit OB2263, Optokoppler & TL431

VERFASSER

### Reinhard Wermeling & KI-Claude

RWTEC · WERKSTATTBERICHT | 12-V-SPERRWANDLER · OB2263
Erstellt 2026-07-11 · OB2263-Sperrwandler | RwTec

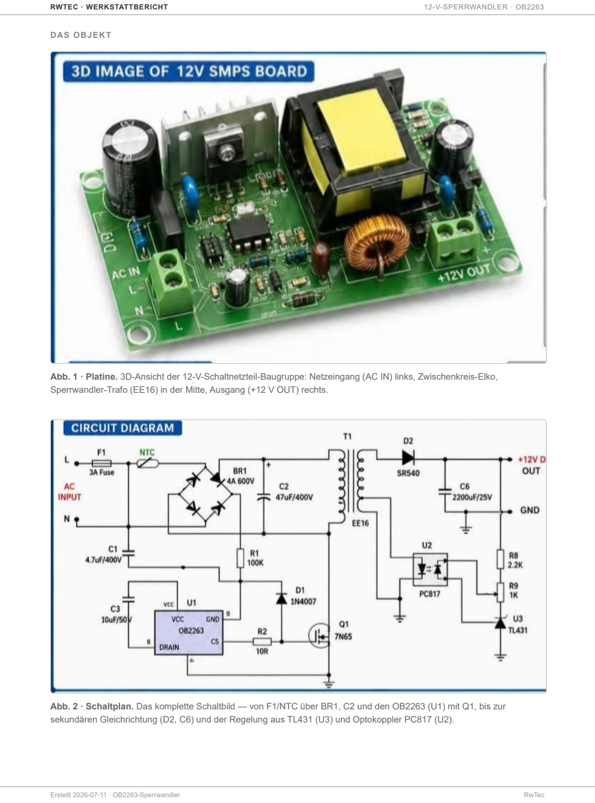
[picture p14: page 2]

DAS OBJEKT

Abb. 1 · Platine. 3D-Ansicht der 12-V-Schaltnetzteil-Baugruppe: Netzeingang (AC IN) links, Zwischenkreis-Elko, Sperrwandler-Trafo (EE16) in der Mitte, Ausgang (+12 V OUT) rechts.

Abb. 2 · Schaltplan. Das komplette Schaltbild — von F1/NTC über BR1, C2 und den OB2263 (U1) mit Q1, bis zur sekundären Gleichrichtung (D2, C6) und der Regelung aus TL431 (U3) und Optokoppler PC817 (U2).

NETZGERÄT-DOKU M ENTATION · GESA M THEFT

# Ein 12-V-Schaltnetzteil verstehen, prüfen & simulieren

### Wie aus 230 V Netzspannung geregelte, berührsichere 12 V werden — ein isolierter Sperrwandler mit OB2263, Optokoppler

und TL431.

KURZFASSUNG
Die Schaltung ist ein isolierter Sperrwandler (Flyback) mit rund 12 V Ausgang und etwa 10–15 W. Ein PWM-Controller OB2263 taktet einen MOSFET mit ~65 kHz; ein kleiner Trafo (EE16) speichert die Energie häppchenweise und trennt die gefährliche Netzseite von der sicheren 12-V-Seite. Geregelt wird sekundärseitig mit einem TL431, isoliert über einen Optokoppler PC817 an den Controller zurückgemeldet. Dieses Heft bündelt alles in drei Schritten: Verstehen → Prüfen → Simulieren.

INHALT
01 Verstehen — Funktionsanalyse der Schaltung | 02 Prüfen — Mess- & Fehleranalyse (sicher)
03 Simulieren — Nachbau im Falstad-Browser | 04 Referenz — Bauteilliste & Kernaussagen

01
TEIL 1 · VERSTEHEN

# Wie das Netzteil arbeitet

### Ausgangslage & Topologie

Vor uns liegt ein kompaktes Netzteil, das aus dem 230-V-Wechselstromnetz stabile 12 V Gleichspannung macht — ein primärgetaktetes Schaltnetzteil. Kein schwerer 50-Hz-Trafo, sondern ein winziger Hochfrequenz-Trafo (Kern EE16), betrieben mit rund 65 kHz. Das macht das Ganze klein, leicht und effizient.

Das Funktionsprinzip heißt Sperrwandler (flyback): Der MOSFET zerhackt die Gleichspannung in schnelle Impulse. In der Einschaltphase wird Energie im Trafo gespeichert, in der Ausschaltphase an den Ausgang „ausgeworfen". Primär- und Sekundärseite leiten dabei nie gleichzeitig.

Verbunden sind beide Welten nur über zwei Bauteile: den Trafo (überträgt Energie) und den Optokoppler (überträgt Information). Genau diese galvanische Trennung ist das Sicherheitsherz der Schaltung.

### Signalfluss — Block für Block

1. Netzeingang & Schutz — F1 (3 A) Sicherung, NTC als Einschaltstrombegrenzer, C1
(4,7 µF/400 V) Entstörung.
2. Gleichrichtung & Sieben — BR1 (4 A/600 V) Brücke, C2 (47 µF/400 V) glättet auf die
~325 V Zwischenkreisspannung .
3. Anlauf & Versorgung — R1 (100 k) lädt VCC bis zur UVLO-Schwelle, C3 (10 µF) stützt; nach dem Anlauf versorgt eine Hilfswicklung (mit D1) den Controller dauerhaft.
4. Schaltstufe — Q1 (7N65) Leistungs-MOSFET, T1 (EE16) Speichertrafo, R2 (10 Ω) Strom-Messwiderstand.
5. Sekundär-Gleichrichtung — D2 (SR540) Schottky-Diode, C6 (2200 µF/25 V) Ausgangs-Elko glättet auf saubere 12 V.

### Herzstück: Die Regelung (OB2263 + Opto + TL431)

Der OB2263 ist ein Strommodus-PWM-Controller: Er regelt nicht direkt die Spannung, sondern in jedem einzelnen Takt den Spitzenstrom durch den MOSFET. Daraus ergeben sich zwei ineinander verschachtelte Regelschleifen.

Innere, schnelle Schleife (Strom, CS/R2): Steigt der Strom rampenförmig an, bildet R2 ihn als Spannung am CS-Pin ab. Erreicht diese die vom FB-Pin vorgegebene Schwelle, schaltet der OB2263 den MOSFET Takt für Takt sofort ab. Überstromschutz ist damit praktisch geschenkt.

Äußere, langsame Schleife (Spannung, Opto): Der TL431 vergleicht über den Teiler R8/R9 die Ausgangsspannung mit seiner 2,5-V-Referenz und steuert die PC817-LED. Der Fototransistor sitzt primärseitig am FB-Pin — die einzige Signalbrücke über die Trennstelle.

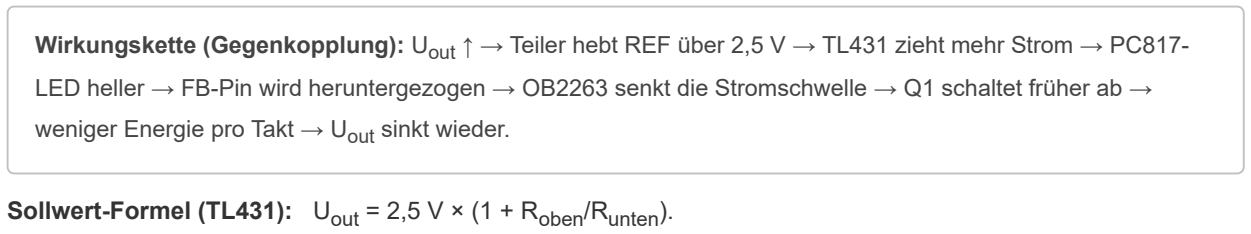
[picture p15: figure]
weniger Energie pro Takt → Uout; sinkt wieder.; Sollwert-Formel (TL431): Uout; = 2,5 V × (1 + Roben; /Runten

Wirkungskette (Gegenkopplung): Uout ↑ → Teiler hebt REF über 2,5 V → TL431 zieht mehr Strom → PC817-LED heller → FB-Pin wird heruntergezogen → OB2263 senkt die Stromschwelle → Q1 schaltet früher ab →

⚠ Hinweis: Mit den angeschriebenen Werten R8 = 2,2 k / R9 = 1 k käme rechnerisch ~8 V heraus, nicht 12 V. Für echte /Runten ≈ 3,8. Solche „Circuit-Diagram"-Werte sind nicht als exakt zu nehmen.

### Der Sperrwandler-Trafo als Energiespeicher

T1 ist gar kein „Trafo" im klassischen Sinn, sondern eine gekoppelte Speicherdrossel, die im

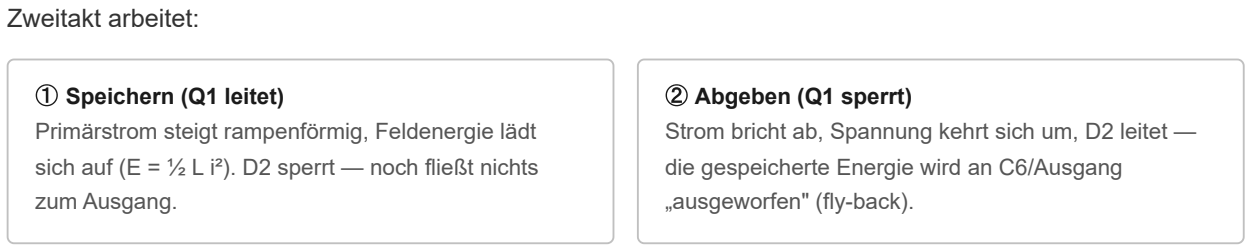
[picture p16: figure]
Zweitakt arbeitet:; ① Speichern (Q1 leitet) Primärstrom steigt rampenförmig, Feldenergie lädt; zum Ausgang.; ② Abgeben (Q1 sperrt); „ausgeworfen" (fly-back).

sich auf (E = ½ L i²). D2 sperrt — noch fließt nichts

Strom bricht ab, Spannung kehrt sich um, D2 leitet — die gespeicherte Energie wird an C6/Ausgang

Warum der Luftspalt entscheidend ist: Im kleinen Luftspalt des EE16-Kerns steckt der Löwenanteil der Energie. Ohne Spalt ginge das Ferrit schon bei kleinem Strom in Sättigung und der MOSFET brennt durch. Ein reiner Trafo will keinen Spalt — ein Flyback-Trafo braucht ihn.

### Optokoppler PC817 & MOSFET 7N65

PC817: LED und Fototransistor in einem Gehäuse, die sich nur mit Licht verständigen — keine elektrische Verbindung (spannungsfest bis ~5000 V). Kennwert ist das CTR: IC = CTR × ILED (~50–600 %). Er arbeitet hier analog im linearen Bereich und überträgt einen stufenlosen Fehlerpegel.

7N65: 650-V-/~7-A-N-Kanal-MOSFET, das schnell schaltende Ventil. 650 V braucht es, weil am Drain in der Ausschaltphase UBus

(~325 V) + reflektierte Spannung + Leck-Spitze zusammenkommen (450–550 V). Q1 vereint drei Rollen: Leistungsschalter, Stellglied der Regelung und Strom-Messpunkt.

Merksatz: Der Trafo überträgt die Energie isoliert, der Optokoppler überträgt die Information isoliert. Zusammen schließen sie den Regelkreis über die Sicherheitsgrenze hinweg.

### Schutzfunktionen (im OB2263 integriert)

✓ UVLO — Unterspannungssperre | ✓ Zyklischer Überstromschutz (CS/R2)
✓ Überlast/Kurzschluss → Hiccup/Auto-Restart | ✓ Übertemperatur & teils Überspannung

02

# Fehler sicher finden

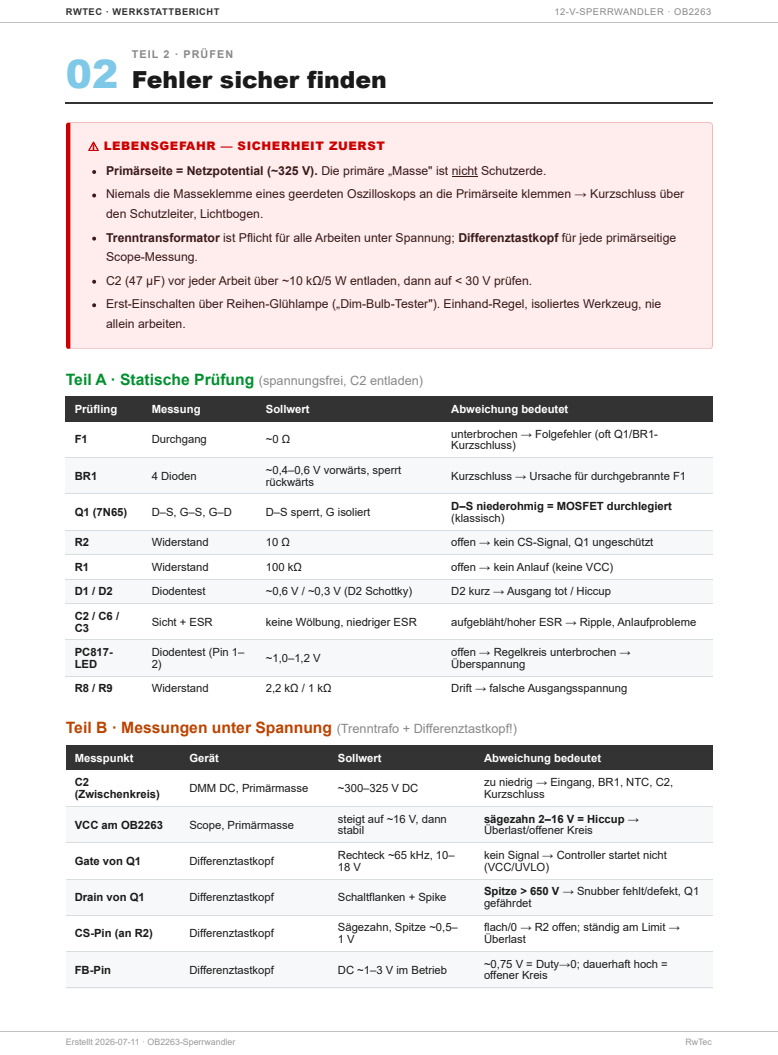
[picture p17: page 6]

Primärseite = Netzpotential (~325 V). Die primäre „Masse" ist nicht Schutzerde.
Niemals die Masseklemme eines geerdeten Oszilloskops an die Primärseite klemmen → Kurzschluss über
den Schutzleiter, Lichtbogen.
Trenntransformator ist Pflicht für alle Arbeiten unter Spannung; Differenztastkopf für jede primärseitige
Scope-Messung.
C2 (47 µF) vor jeder Arbeit über ~10 kΩ/5 W entladen, dann auf < 30 V prüfen.
Erst-Einschalten über Reihen-Glühlampe („Dim-Bulb-Tester"). Einhand-Regel, isoliertes Werkzeug, nie
allein arbeiten.

Teil A · Statische Prüfung (spannungsfrei, C2 entladen)

Prüfling | Messung | Sollwert | Abweichung bedeutet

F1 | Durchgang | ~0 Ω | unterbrochen → Folgefehler (oft Q1/BR1-Kurzschluss)

BR1 | 4 Dioden | ~0,4–0,6 V vorwärts, sperrt rückwärts | Kurzschluss → Ursache für durchgebrannte F1

Q1 (7N65) | D–S, G–S, G–D | D–S sperrt, G isoliert | D–S niederohmig = MOSFET durchlegiert (klassisch)

R2 | Widerstand | 10 Ω | offen → kein CS-Signal, Q1 ungeschützt

R1 | Widerstand | 100 kΩ | offen → kein Anlauf (keine VCC)

D1 / D2 | Diodentest | ~0,6 V / ~0,3 V (D2 Schottky) | D2 kurz → Ausgang tot / Hiccup

C2 / C6 / C3 | Sicht + ESR | keine Wölbung, niedriger ESR | aufgebläht/hoher ESR → Ripple, Anlaufprobleme

PC817-LED | Diodentest (Pin 1– 2) ~1,0–1,2 V | | offen → Regelkreis unterbrochen → Überspannung

R8 / R9 | Widerstand | 2,2 kΩ / 1 kΩ | Drift → falsche Ausgangsspannung

Teil B · Messungen unter Spannung (Trenntrafo + Differenztastkopf!)

Messpunkt | Gerät | Sollwert | Abweichung bedeutet

C2 (Zwischenkreis) | DMM DC, Primärmasse | ~300–325 V DC | zu niedrig → Eingang, BR1, NTC, C2, Kurzschluss

VCC am OB2263 | Scope, Primärmasse | steigt auf ~16 V, dann stabil | sägezahn 2–16 V = Hiccup → Überlast/offener Kreis

Gate von Q1 | Differenztastkopf | Rechteck ~65 kHz, 10– 18 V | kein Signal → Controller startet nicht (VCC/UVLO)

Drain von Q1 | Differenztastkopf | Schaltflanken + Spike | Spitze > 650 V → Snubber fehlt/defekt, Q1 gefährdet

CS-Pin (an R2) | Differenztastkopf | Sägezahn, Spitze ~0,5– 1 V | flach/0 → R2 offen; ständig am Limit → Überlast

FB-Pin | Differenztastkopf | DC ~1–3 V im Betrieb | ~0,75 V = Duty→0; dauerhaft hoch = offener Kreis

Messpunkt | Gerät | Sollwert | Abweichung bedeutet
+12 V Ausgang | DMM+Scope, Sekundärmasse | 12 V ±5 %, Ripple <~100 mVpp | zu niedrig → Regelkreis/Last/C6; zu hoch → Kreis offen
TL431 REF | DMM, Sekundärmasse | ~2,5 V bei Regelung | ≠ 2,5 V → TL431 oder Teiler R8/R9 defekt

Massebezug: Sekundärmessungen (Ausgang, TL431) referenzieren die sichere, isolierte Sekundärmasse — normaler Tastkopf genügt. Primärmessungen (C2, VCC, Gate, Drain, CS, FB) referenzieren die netzbezogene Primärmasse — nur mit Differenztastkopf.

### Symptom → Ursache (Schnelldiagnose)

Symptom | Wahrscheinliche Ursachen | Zuerst prüfen
Völlig tot, keine VCC | F1 offen, BR1/Q1 kurz, C2 defekt, R1 offen, OB2263 defekt | Teil A + C2
Tickt/pfeift, Ausgang bricht ein (Hiccup) | Überlast/Kurzschluss sekundär, D2 kurz, C6 kurz, offener Regelkreis | VCC-Verlauf, D2, Opto
Ausgang zu hoch | Regelkreis offen: PC817-LED, TL431, R8/R9 | FB-Pin, Opto, TL431
Ausgang zu niedrig / bricht unter Last ein | C2-ESR, C6-ESR, D2, schwache Regelung | ESR C2/C6, D2

03
TEIL 3 · SIMULIEREN

# Nachbau im Falstad-Browser

Mit dem kostenlosen Falstad CircuitJS (falstad.com/circuit, keine Installation) lässt sich das Prinzip anschaulich nachbauen: Zwischenkreis → Schalter → Trafo → Gleichrichtung → geschlossener Regelkreis. Den OB2263 ersetzen wir durch Sägezahn + Komparator (PWM) und einen Op-Amp (Fehlerverstärker) — gleiche Wirkung. Der animierte Stromfluss macht Gleichrichtung, Trafo und Rückkopplung sichtbar.

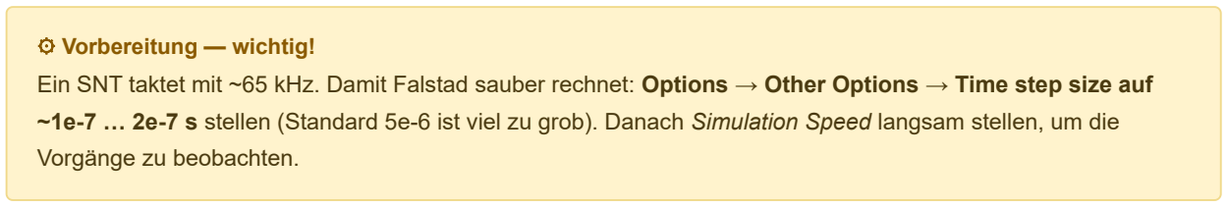
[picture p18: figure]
⚙ Vorbereitung — wichtig!; Vorgänge zu beobachten.

Ein SNT taktet mit ~65 kHz. Damit Falstad sauber rechnet: Options → Other Options → Time step size auf ~1e-7 … 2e-7 s stellen (Standard 5e-6 ist viel zu grob). Danach Simulation Speed langsam stellen, um die

### Der Aufbau in 7 Schritten

① Zwischenkreis (~310 V): Draw → Inputs and Sources → Add Var Rail, Wert 310 V (später dein „Netzspannungs"-Regler). Add Ground als Bezugsmasse.

② Sperrwandler-Trafo: Add Transformer. Edit: Primary Inductance ≈ 2,5 mH, Turns Ratio (Np:Ns) ≈ 8, Coupling 0,99. Primär-oben an +310 V.

③ Schalttransistor (statt Q1): Add MOSFET (N-Channel). Drain an Primär-unten, Source an Masse, Gate kommt vom PWM (Schritt ⑤).

④ Sekundär-Gleichrichtung: Diode von Sekundärwicklung zum Ausgang (+12 V), Capacitor 220 µF, Resistor 12 Ω als Grundlast (~1 A). Optional Switch + zweiter Lastwiderstand für den Lastsprung.

⑤ PWM erzeugen: A/C Voltage Source → Waveform Sawtooth, 65 kHz, 0…5 V. Op-Amp als Komparator: − = Sägezahn, + = Regelspannung, Ausgang → Gate. Regelspannung hoch ⇒ Tastverhältnis groß.

⑥ Rückkopplung (statt TL431+Opto): Teiler R8=38 k / R9=10 k (Mittelabgriff = Istwert), Referenz 2,5 V (Var Rail). Op-Amp als Fehlerverstärker: − = Istwert, + = 2,5 V, Ausgang = Regelspannung. RC-Glied (100 k + 1 nF) für Stabilität (PI-Regler).

⑦ Messen & Ausprobieren: View in Scope auf Ausgang, Gate, Primärstrom. Last ändern → Uout
bleibt ~12 V. Var Rail schieben → Uout

stabil, Duty ändert sich. Regelung „öffnen" → Uout

läuft in
die Überspannung.

### Bauteil-/Wertetabelle

Falstad | Wert | Rolle
Var Rail | 310 V | C2 (~325 V)
Transformer | 2,5 mH · n 8 · k 0,99 | T1 (EE16)
MOSFET (N) | Standard | Q1 (7N65)

### ⚠ Stolpersteine

Time step vergessen → 65 kHz nicht aufgelöst, Konvergenzfehler. Immer ~1e-7 setzen. Trafo-Kopplung 0,99, nicht 1,0 — kleine Streuung erzeugt die realistische Drain-Spitze.

Falstad | Wert | Rolle
Diode | Schottky | D2 (SR540)
Capacitor | 220 µF | C6
Resistor (Last) | 12 Ω | Verbraucher
A/C (Sawtooth) | 65 kHz, 0–5 V | Oszillator
Op-Amp + RC | 100k / 1nF | TL431
R8 / R9 | 38 k / 10 k | Sollwert-Teiler

Falsche Dot-Orientierung → Diode leitet zur falschen Zeit → Sekundäranschlüsse tauschen.
Vorzeichen der Regelung falsch → Uout

läuft weg →
Op-Amp-Eingänge tauschen.
Op-Amp schwingt → RC-Kompensation (Cf) vergrößern.

### 🚀 Ausbaustufen

Echter Netzeingang: A/C 325 V/50 Hz + Brücke + 47 µF. Snubber: RCD-Glied über der Primärwicklung.
Echte Trennung: Opto nachbilden, Fehlerverstärker auf zweite Masse.

## 0 3 · S I M U L I E R E N

# Falstad-Nachbau — detaillierter Schaltplan

Vereinfachter Sperrwandler (nicht isoliert): Leistungsstufe, PWM aus Sägezahn + Komparator und Regelung mit Fehlerverstärker. Gleiche Netznamen (VOUT · GATE · CONTROL · FB) sind elektrisch verbundene Knoten.

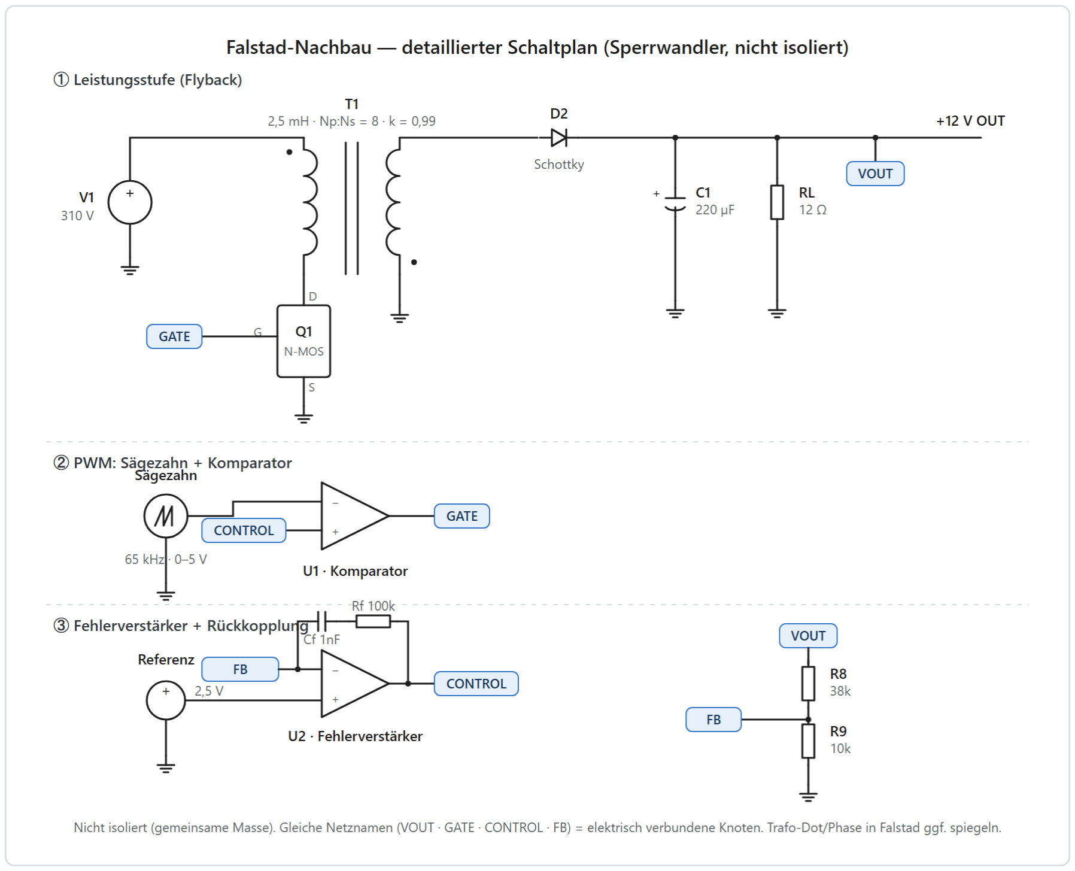
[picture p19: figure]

Abb.: Detaillierter Schaltplan zum Nachbau in Falstad — V1 310 V · T1 (2,5 mH · n=8 · k=0,99) · Q1 · D2 · C1/RL · PWM (U1) · Fehlerverstärker (U2) · Teiler R8/R9.

Netzgerät · OB2263-Sperrwandler | Werkstattbericht · RwTec

## 0 3 · S I M U L I E R E N

# Die Regelung läuft — Falstad-Simulation

## Der geschlossene Regelkreis arbeitet: Sägezahn + Komparator erzeugen die PWM, der

Fehlerverstärker (2,5-V-Referenz, Teiler 30k/10k) hält die Ausgangsspannung stabil.

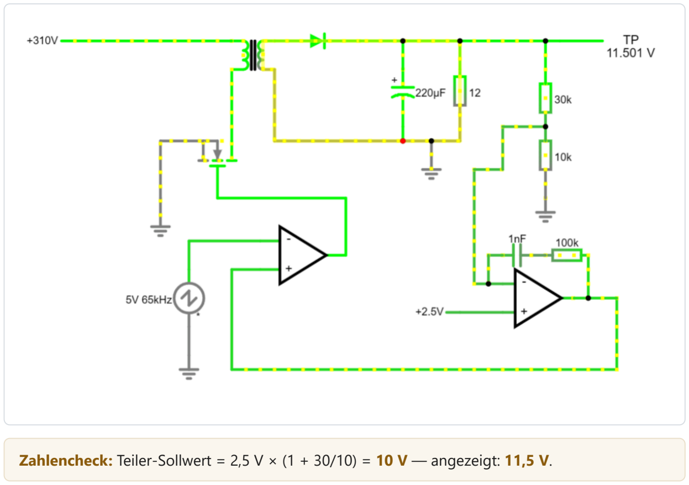
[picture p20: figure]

Zahlencheck: Teiler-Sollwert = 2,5 V × (1 + 30/10) = 10 V — angezeigt: 11,5 V.

Warum der kleine Offset? Dieser vereinfachte Fehlerverstärker ist kein idealer Integrator (endliche Schleifenverstärkung). Reale Controller wie der OB2263 fahren die Verstärkung so hoch, dass der Rest-Offset praktisch verschwindet.

Regelung nachweisen: Last ändern (12 Ω → 8/24 Ω) oder die 310-V-Rail schieben — TP bleibt nahezu stehen (Last- und Netzausregelung).

Exakt 12 V: oberen Teilerwiderstand trimmen, bis TP 12,0 V zeigt — oder U2 als echten Integrator (Serien-C + Eingangswiderstand) verschalten.

Netzgerät · OB2263-Sperrwandler | Werkstattbericht · RwTec

04
TEIL 4 · REFERENZ

# Bauteilliste & Kernaussagen

### Bauteilliste

Bauteil | Wert / Typ | Funktion
F1 | 3 A | Netzsicherung
NTC | Thermistor | Einschaltstrombegrenzung
C1 | 4,7 µF / 400 V | Eingangs-/Entstörkondensator
BR1 | 4 A / 600 V | Brückengleichrichter
C2 | 47 µF / 400 V | Zwischenkreis-Elko (~325 V)
R1 | 100 k | Anlaufwiderstand
D1 | 1N4007 | Gleichrichter Hilfswicklung (VCC)
C3 | 10 µF / 50 V | VCC-Stützkondensator
U1 | OB2263 | Strommodus-PWM-Controller
Q1 | 7N65 | Leistungs-MOSFET (650 V / ~7 A)
R2 | 10 Ω | Strom-Messwiderstand (CS)
T1 | EE16 | Sperrwandler-Trafo (Speicher + Trennung)
D2 | SR540 | Schottky-Sekundärgleichrichter (5 A / 40 V)
C6 | 2200 µF / 25 V | Ausgangs-Elko
U3 | TL431 | Präzisionsreferenz / Fehlerverstärker
U2 | PC817 | Optokoppler (isolierte Rückmeldung)
R8 / R9 | 2,2 k / 1 k | Spannungsteiler (Sollwert)

### Die wichtigsten Kernaussagen

Zwei getrennte Welten: Der Trafo überträgt die Energie isoliert, der Optokoppler die Information — zusammen schließen sie den Regelkreis über die Sicherheitsgrenze.

Strommodus-Regelung: Der OB2263 regelt Takt für Takt den Spitzenstrom; die 12 V werden sekundär mit TL431 gemessen und per Opto zurückgemeldet.

Der „Trafo" ist ein Speicher: Energie wird im Luftspalt zwischengelagert (Speichern/Abgeben), nicht direkt durchgereicht.

Sicherheit: Primärseite führt Netzpotential; unter Spannung nur mit Trenntrafo und Differenztastkopf. Ohne Rückkopplung droht Überspannung.

### Empfohlener Lernpfad

1. Zuerst Teil 1 (Verstehen) lesen — das Prinzip verinnerlichen.
2. Dann die interaktive Simulation öffnen und am Modell „spielen", bis das Regelverhalten sitzt.
3. Optional Teil 3 (Simulieren) — die Schaltung selbst im Browser nachbauen.
4. Bei Reparatur/Defekt Teil 2 (Prüfen) — nach dem Sicherheits-Ablauf messen.

A
ANHANG

# Vollständiger Schaltplan

Referenz-Schaltbild · PWM Controlled SMPS. Kompletter Sperrwandler von AC IN über Brückengleichrichter (W10G), Zwischenkreis (C1/C2) und PWM-Controller U1 (GND/FB/RT · GATE/VDD/CS) mit MOSFET Q1, bis zum Trafo T1, der sekundären Gleichrichtung (D4, C5) am +12-V-Ausgang und der isolierten Regelung aus TL431 (U2) und Optokoppler PC817. GND P (Primärmasse) und GND S (Sekundärmasse) sind getrennt.

OB2263-Sperrwandler · Gesamtheft · Verstehen → Prüfen → Simulieren Erstellt 2026-07-11 · RwTec Werkstattbericht

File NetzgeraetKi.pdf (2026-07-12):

Ein 12‑V‑Schaltnetzteil verstehen — OB2263,

# Optokoppler & TL431

Wie aus 230 V Netzspannung geregelte, berührsichere 12 V werden — ein Werkstattbericht

Kurzfassung: Die Schaltung ist ein ==isolierter Sperrwandler== (Flyback‑Schaltnetzteil) mit rund 12 V Ausgang und etwa 10–15 W. Ein PWM‑Controller OB2263 taktet einen MOSFET, ein kleiner Trafo speichert die Energie häppchenweise und trennt gleichzeitig die gefährliche Netzseite von der sicheren 12‑V‑Seite. Geregelt wird die Ausgangsspannung sekundärseitig mit einem TL431 und isoliert über einen Optokoppler PC817 an den Controller zurückgemeldet. Dieses Prinzip steckt in fast jedem Steckernetzteil und Ladegerät.

## 🧭 Ausgangslage — was liegt auf dem Tisch?

Vor uns liegt der Schaltplan eines kompakten Netzteils, das aus dem 230‑V‑Wechselstromnetz stabile 12 V Gleichspannung macht. Es ist ein primärgetaktetes Schaltnetzteil — kein schwerer 50‑Hz‑Trafo, sondern ein winziger Hochfrequenz‑Trafo (Kerngröße EE16), der mit rund 65 kHz betrieben wird. Das macht das Ganze klein, leicht und effizient.

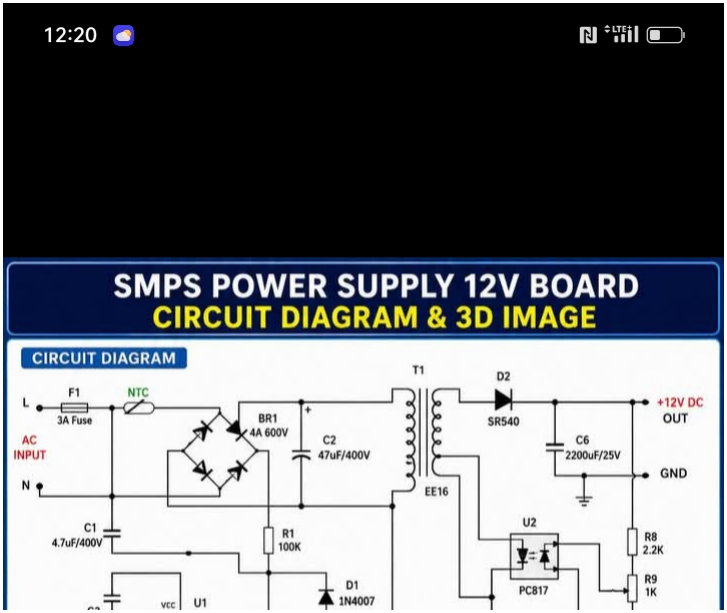
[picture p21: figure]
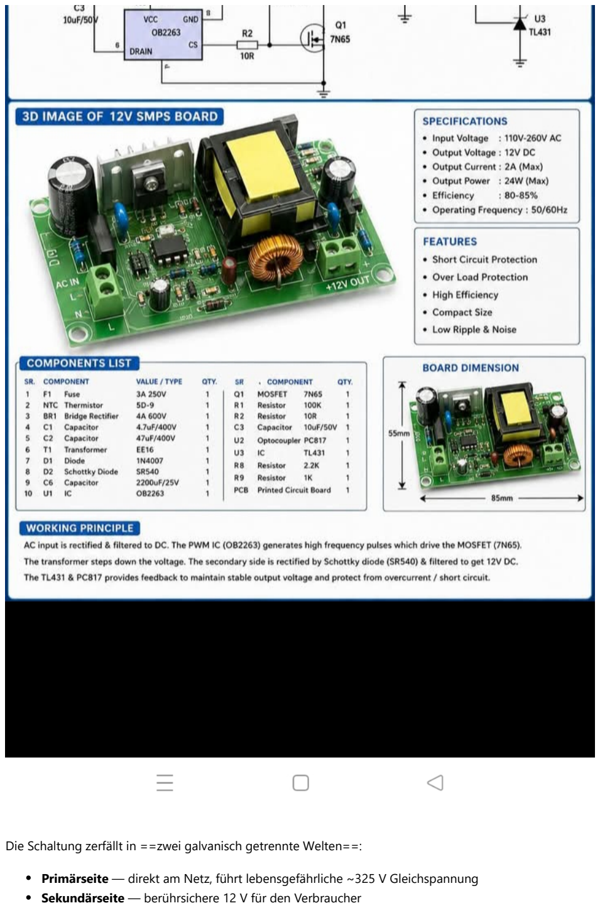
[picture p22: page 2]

Die Schaltung zerfällt in ==zwei galvanisch getrennte Welten==:

Primärseite — direkt am Netz, führt lebensgefährliche ~325 V Gleichspannung Sekundärseite — berührsichere 12 V für den Verbraucher

Verbunden sind beide nur über zwei Bauteile: den Trafo (überträgt Energie) und den Optokoppler (überträgt Information). Genau diese Trennung ist das Sicherheitsherz der Schaltung.

## 📐 Der große Überblick — die Topologie

Das Funktionsprinzip heißt Sperrwandler (englisch flyback):

Der MOSFET zerhackt die Gleichspannung in schnelle Impulse. In der Einschaltphase wird Energie
im Trafo gespeichert, in der Ausschaltphase an den Ausgang „ausgeworfen". Primär- und Sekundärseite leiten dabei nie gleichzeitig.

Der Regelkreis schließt sich einmal im Uhrzeigersinn: Der Controller steuert den Schalter (Leistung), die 12 V werden gemessen und über den Optokoppler zurückgemeldet (Information) — und der Controller korrigiert nach.


🟠 = Leistungsfluss · 🔵 = Regel-/Rückkopplungspfad. Der Trafo (oben) und der Optokoppler (unten) sind die einzigen Brücken über die galvanische Trennung.

## 🔩 Signalfluss — Block für Block

### 1. Netzeingang & Schutz

🛡 F1 (3 A) — Sicherung gegen Überstrom und Brandfall
🛡 NTC — Einschaltstrombegrenzer: kalt hochohmig, dämpft den Ladestromstoß beim Einschalten; erwärmt sich dann und wird niederohmig
C1 (4,7 µF / 400 V) — Eingangs‑/Entstörkondensator

### 2. Gleichrichtung & Sieben

BR1 (4 A / 600 V) — Brückengleichrichter: macht aus 230 V~ pulsierenden Gleichstrom
C2 (47 µF / 400 V) — Lade‑Elko: glättet auf die ==~325 V Zwischenkreisspannung==. Das ist die „Batterie", aus der der Wandler schöpft.

### 3. Anlauf & Controller‑Versorgung

R1 (100 k) — Anlaufwiderstand: lädt beim Einschalten langsam den VCC‑Kondensator, bis der OB2263 seine Einschaltschwelle (UVLO) erreicht
C3 (10 µF / 50 V) — VCC‑Stützkondensator
D1 (1N4007) + Hilfswicklung — nach dem Anlauf versorgt eine Hilfswicklung am Trafo den Controller dauerhaft

### 4. Schaltstufe

Q1 (7N65) — der Leistungs‑MOSFET, das eigentliche Schaltventil (Details unten) T1 (EE16) — der Sperrwandler‑Trafo, Energiespeicher und Trennstelle (Details unten) R2 (10 Ω) — Strom‑Messwiderstand für die Stromregelung

### 5. Sekundär‑Gleichrichtung

D2 (SR540) — Schottky‑Diode (5 A / 40 V): leitet in der Ausschaltphase, geringe Verluste C6 (2200 µF / 25 V) — Ausgangs‑Elko: glättet auf saubere 12 V

## 🎯 Herzstück: Die Regelung (OB2263 + Optokoppler + TL431)

Der OB2263 ist ein ==Strommodus‑PWM‑Controller==. Das Besondere: Er regelt nicht direkt die Spannung, sondern in jedem einzelnen Takt den Spitzenstrom durch den MOSFET. Daraus ergeben sich zwei ineinander verschachtelte Regelschleifen.
🔬 Innere, schnelle Schleife — Stromregelung (CS / R2)

Sobald Q1 einschaltet, steigt der Strom rampenförmig an. R2 (10 Ω) bildet ihn als Spannung am CS‑Pin ab. Erreicht diese die vom FB‑Pin vorgegebene Schwelle, schaltet der OB2263 den MOSFET ==Takt für Takt sofort ab==. Vorteile: sehr gute Netzausregelung — und der Überstromschutz ist praktisch geschenkt. Interne Extras: Leading‑Edge‑Blanking (blendet den Einschalt‑Stromspike aus) und Slope‑Kompensation (verhindert Schwingen bei >50 % Tastverhältnis).
🔑 Äußere, langsame Schleife — Spannungsregelung (der Optokoppler‑Pfad)

Hier läuft die eigentliche „12 V"-Regelung, komplett sekundärseitig gemessen und isoliert zurückgemeldet:

1. U3 (TL431) — eine programmierbare Präzisionsreferenz mit interner 2,5‑V‑Referenz. Sie ist Referenz und Fehlerverstärker in einem Bauteil und vergleicht über den Teiler R8/R9 die Ausgangsspannung mit ihrem Sollwert.
2. U2 (PC817) — der Optokoppler. Seine LED steuert der TL431 an; der Fototransistor sitzt primärseitig am FB‑Pin (Pin 2) des OB2263 und ist die einzige Signalbrücke über die Trennstelle.

Die Wirkungskette bei steigender Ausgangsspannung (das Vorzeichen der Regelung):

U_out ↑ → Teiler hebt REF über 2,5 V → TL431 zieht mehr Strom → PC817‑LED heller → Fototransistor leitet stärker → FB‑Pin wird heruntergezogen → OB2263 senkt die Stromschwelle
→ Q1 schaltet früher ab → weniger Energie pro Takt → U_out sinkt wieder.

Und exakt umgekehrt, wenn die Spannung einbricht. Das ist eine saubere ==Gegenkopplung==. Laut Datenblatt liegt die Zero‑Duty‑Schwelle bei FB ≈ 0,75 V: Zieht der Optokoppler FB so weit herunter, geht das Tastverhältnis gegen null.
🧮 Der Sollwert (TL431‑Formel)

Der TL431 regelt so, dass an seinem REF‑Pin genau 2,5 V anliegen:

$$U_{out} = 2{,}5,\text{V} \times \left(1 + \frac{R_{oben}}{R_{unten}}\right)$$

⚠ Zum Mitrechnen: Mit den im Schaltbild angeschriebenen Werten R8 = 2,2 k / R9 = 1 k käme rechnerisch 2,5 × (1 + 2,2) = ≈ 8 V heraus, nicht 12 V. Für echte 12 V braucht man R_oben/R_unten ≈ 3,8 (z. B. ~3,8 k / 1 k). Solche „Circuit‑Diagram"-Grafiken sind prinzipiell korrekt — die konkreten Bauteilwerte sollte man aber nicht als exakt nehmen.

## 🧲 Der Sperrwandler‑Trafo als Energiespeicher

Das Wichtigste vorweg: T1 ist gar kein „Trafo" im klassischen Sinn, sondern eine ==gekoppelte Speicherdrossel==. Er arbeitet im Zweitakt.


Klassischer Trafo | Sperrwandler‑Trafo (Flyback)

Energie fließt gleichzeitig rein und raus erst speichern, dann abgeben

Klassischer Trafo | Sperrwandler‑Trafo (Flyback)
Primär & Sekundär leiten zusammen | leiten nie gleichzeitig
speichert (idealerweise) keine Energie | muss Energie zwischenspeichern

① Speichern (Q1 leitet): Der Primärstrom steigt rampenförmig, der magnetische Fluss wächst, Feldenergie lädt sich auf: $E = \tfrac{1}{2},L,i^2$. Die Diode D2 sperrt — noch fließt nichts zum Ausgang.

② Abgeben (Q1 sperrt): Der Strom wird schlagartig unterbrochen. Der Fluss kann nicht springen, also kehrt sich die Spannung um, D2 wird leitend, und die gespeicherte Energie wird an C6/den Ausgang „ausgeworfen" (daher Fly‑back).

🔑 Warum der Luftspalt entscheidend ist: Im kleinen Luftspalt des EE16‑Kerns steckt der Löwenanteil der Energie. Ohne Spalt würde das Ferrit schon bei kleinem Strom in die Sättigung gehen und der MOSFET durchbrennen. Ein reiner Trafo will keinen Spalt — ein Flyback‑Trafo braucht ihn.

Nebenbei leistet T1 noch zweierlei: die Spannungsübersetzung über das Windungsverhältnis $n = N_p/N_s$ (aus 325 V werden 12 V) und die galvanische Trennung der beiden Wicklungen.

Die Brücke zur Regelung: Die pro Takt übertragene Leistung ist im lückenden Betrieb (DCM) grob $P \approx \tfrac{1}{2},L,i_{pk}^2 \cdot f$. Genau an dieser Schraube — wie hoch der Primärstrom pro Takt laufen darf — dreht der Regelkreis.

## 🔦 Der Optokoppler PC817 — Information über die Grenze

Der PC817 vereint LED und Fototransistor in einem Gehäuse, die sich nur mit Licht verständigen. Es gibt ==keine elektrische Verbindung== — es wandern nur Photonen über einen Isolierspalt (typ. bis ~5000 V spannungsfest). Das übertragene Signal ist ein Strom bzw. eine Lichtstärke, keine Spannung.

Der Kennwert ist das CTR (Current Transfer Ratio), das Verhältnis von Kollektor‑ zu LED‑Strom:

$$I_C = \text{CTR} \times I_{LED}$$

Beim PC817 liegt CTR grob bei 50–600 % (die Bauteile sind in Klassen sortiert). Wichtig: Er arbeitet hier analog im linearen Bereich — er überträgt einen stufenlosen Fehlerpegel, nicht nur „ein/aus". Weil der Fototransistor relativ langsam ist, begrenzt er die Regelbandbreite; deshalb braucht der TL431 in der Praxis noch ein RC‑Kompensationsglied.

💡 Merksatz: Der Trafo überträgt die Energie isoliert, der Optokoppler überträgt die Information isoliert. Zusammen schließen sie den Regelkreis über die Sicherheitsgrenze hinweg.

## 🔀 Der MOSFET 7N65 — der Zerhacker

Q1 (650 V / ~7 A N‑Kanal‑Leistungs‑MOSFET) ist das schnell schaltende Ventil, das aus der ruhenden Gleichspannung erst die hochfrequenten Impulse macht — ein Trafo koppelt nur Wechsel-/Impulsgrößen, reinen Gleichstrom nicht.

Warum ausgerechnet 650 V? In der Ausschaltphase liegt am Drain die Summe aus:

$$U_{Drain} \approx \underbrace{U_{Bus}}{\sim325,V} + \underbrace{n\cdot(U{out}+U_{D2})} {\text{reflektiert}} + \underbrace{\text{Leck-Spitze}}{\text{Streuinduktivität}}$$

Das kann leicht 450–550 V erreichen — der 650‑V‑Typ liefert die nötige Sicherheitsreserve.

Q1 spielt drei Rollen zugleich:

Rolle | Wie
Leistungsschalter | zerhackt den HV‑Bus mit ~65 kHz → Energie in den Trafo

Stellglied der Regelung seine Einschaltdauer bestimmt die übertragene Energie

Strom‑Messpunkt | sein Source‑Strom über R2 liefert die Strommodus‑Info + Überstromschutz

Q1 ist damit der Punkt, an dem Steuerung (Gate), Leistung (Drain/Trafo) und Rückmeldung (Source/CS) zusammenlaufen.

## 🛡 Schutzfunktionen (im OB2263 integriert)

✅ UVLO — Unterspannungssperre für sicheren An-/Auslauf
✅ Zyklischer Überstromschutz — über CS/R2, Takt für Takt
✅ Überlast / Kurzschluss — Umschalten in Hiccup/Auto‑Restart (periodisches Wiederanlaufen statt Durchbrennen)
✅ Übertemperatur und teils Ausgangs‑Überspannungsschutz

## ⚠ Stolpersteine & Hinweise zum Schaltbild

Das vorliegende „Circuit‑Diagram" ist vereinfacht und an einigen Stellen ungenau — gut zu wissen beim Nachvollziehen:

Pin‑Beschriftung „DRAIN / 6" am U1 passt nicht zum realen OB2263‑Pinout. Funktional relevant: FB (Pin 2) ← Optokoppler, CS (Pin 4) ← R2, dazu GATE (treibt Q1), VDD, GND, RT (Frequenz). Der Pin zum MOSFET ist der Gate‑Treiber.
Die Hilfswicklung für die VCC‑Versorgung ist nicht eingezeichnet (D1 gehört dazu).
Ein Primär‑Snubber (RCD‑Klemme) über der Primärwicklung, der die Leck‑Spitze am Drain begrenzt, fehlt — auf einer echten Platine ist er praktisch immer vorhanden.
Der Spannungsteiler R8/R9 ergibt rechnerisch ~8 V (siehe Formel‑Kasten oben).

## 🔁 Vollständiger vs. vereinfachter Schaltplan

Das obige „Circuit‑Diagram" (Schaltplan.jpg) lässt einige Verbindungen weg — vor allem die Rückmeldeleitung vom Optokoppler zum FB‑Pin. Deshalb wirkt der Optokoppler dort scheinbar „unverbunden". Ein vollständigerer Referenzplan desselben Prinzips (generischer Controller U1, aus dem Kontext „LED‑TV — PWM Controlled SMPS") zeichnet sie ausdrücklich ein:


Dort trägt der Controller genau das Pin‑Schema, das wir für den OB2263 beschrieben haben: 1 GND · 2 FB · 3 RT · 4 CS · 5 VDD · 6 GATE. Und der Regelweg ist lückenlos gezeichnet:

+12 V OUT → Teiler R7 / R6 → REF des TL431 → TL431 steuert den PC817‑LED‑Strom → Licht → Fototransistor → FB (Pin 2) von U1 → Emitter auf GND P.

Damit wird sichtbar, was im ersten Bild fehlte:

Detail | Vereinfacht (Schaltplan.jpg) Vollständig (Referenzplan)
FB‑Pin + Opto‑Rückleitung | fehlt | ✅ gezeichnet
RT‑Widerstand (Frequenz) | fehlt | ✅ R5 an Pin 3
Primär‑Snubber (RCD‑Klemme) fehlt | ✅ R3 / R4 / C6 / D2
Getrennte Massen | nicht markiert | ✅ GND P / GND S


🔑 Merke: Über die galvanische Trennung führt nie ein Draht — die „Verbindung" ist das Licht im Optokoppler. Die einzige elektrische Rückleitung liegt auf der Primärseite: ==Fototransistor‑Kollektor → FB (Pin 2)==.

Zwei Beschriftungs‑Stolpersteine in diesem Referenzplan: TL431 und PC817 sind beide mit „U2" beschriftet (richtig wäre U2 / U3), und D2 ist dort die Klemmdiode des Snubbers — der Ausgangsgleichrichter heißt hier D4.

## 📚 Bauteilliste

Bauteil Wert / Typ | Funktion
F1 | 3 A | Netzsicherung
NTC | Thermistor | Einschaltstrombegrenzung
C1 | 4,7 µF / 400 V | Eingangs‑/Entstörkondensator
BR1 | 4 A / 600 V | Brückengleichrichter
C2 | 47 µF / 400 V | Zwischenkreis‑Elko (~325 V)
R1 | 100 k | Anlaufwiderstand
D1 | 1N4007 | Gleichrichter Hilfswicklung (VCC)
C3 | 10 µF / 50 V | VCC‑Stützkondensator
U1 | OB2263 | Strommodus‑PWM‑Controller
Q1 | 7N65 | Leistungs‑MOSFET (650 V / ~7 A)

Bauteil Wert / Typ | Funktion
R2 | 10 Ω | Strom‑Messwiderstand (CS)
T1 | EE16 | Sperrwandler‑Trafo (Speicher + Trennung)
D2 | SR540 | Schottky‑Sekundärgleichrichter (5 A / 40 V)
C6 | 2200 µF / 25 V Ausgangs‑Elko
U3 | TL431 | Präzisionsreferenz / Fehlerverstärker
U2 | PC817 | Optokoppler (isolierte Rückmeldung)
R8 / R9 2,2 k / 1 k | Spannungsteiler (Sollwert)

## 💡 Verständnisfragen (für den Unterricht)

1. Warum leiten Primär- und Sekundärseite eines Sperrwandlers nie gleichzeitig?
2. Wozu dient der Luftspalt im Trafokern — und was passiert ohne ihn?
3. Welchen Weg nimmt die Regelinformation vom 12‑V‑Ausgang zurück zum Controller?
4. Warum muss der MOSFET 650 V aushalten, obwohl der Bus nur ~325 V führt?
5. Was übernimmt der Optokoppler, was der Trafo — und warum braucht es beide?

## 🎯 Fazit

Dieses kleine Netzteil zeigt ein komplettes Regelungskonzept auf engstem Raum: Ein Strommodus‑Controller taktet einen MOSFET, ein Speichertrafo portioniert die Energie und trennt sicher, und eine sekundärseitige Regelung aus TL431 + Optokoppler hält die 12 V stabil — isoliert und präzise. Wer dieses Zusammenspiel aus Leistungspfad und Regelpfad einmal verstanden hat, erkennt es in fast jedem modernen Steckernetzteil wieder.

Erstellt: 2026‑07‑11 · OB2263‑Sperrwandler‑Analyse · erarbeitet mit Claude Code (Opus 4.8) + Rw

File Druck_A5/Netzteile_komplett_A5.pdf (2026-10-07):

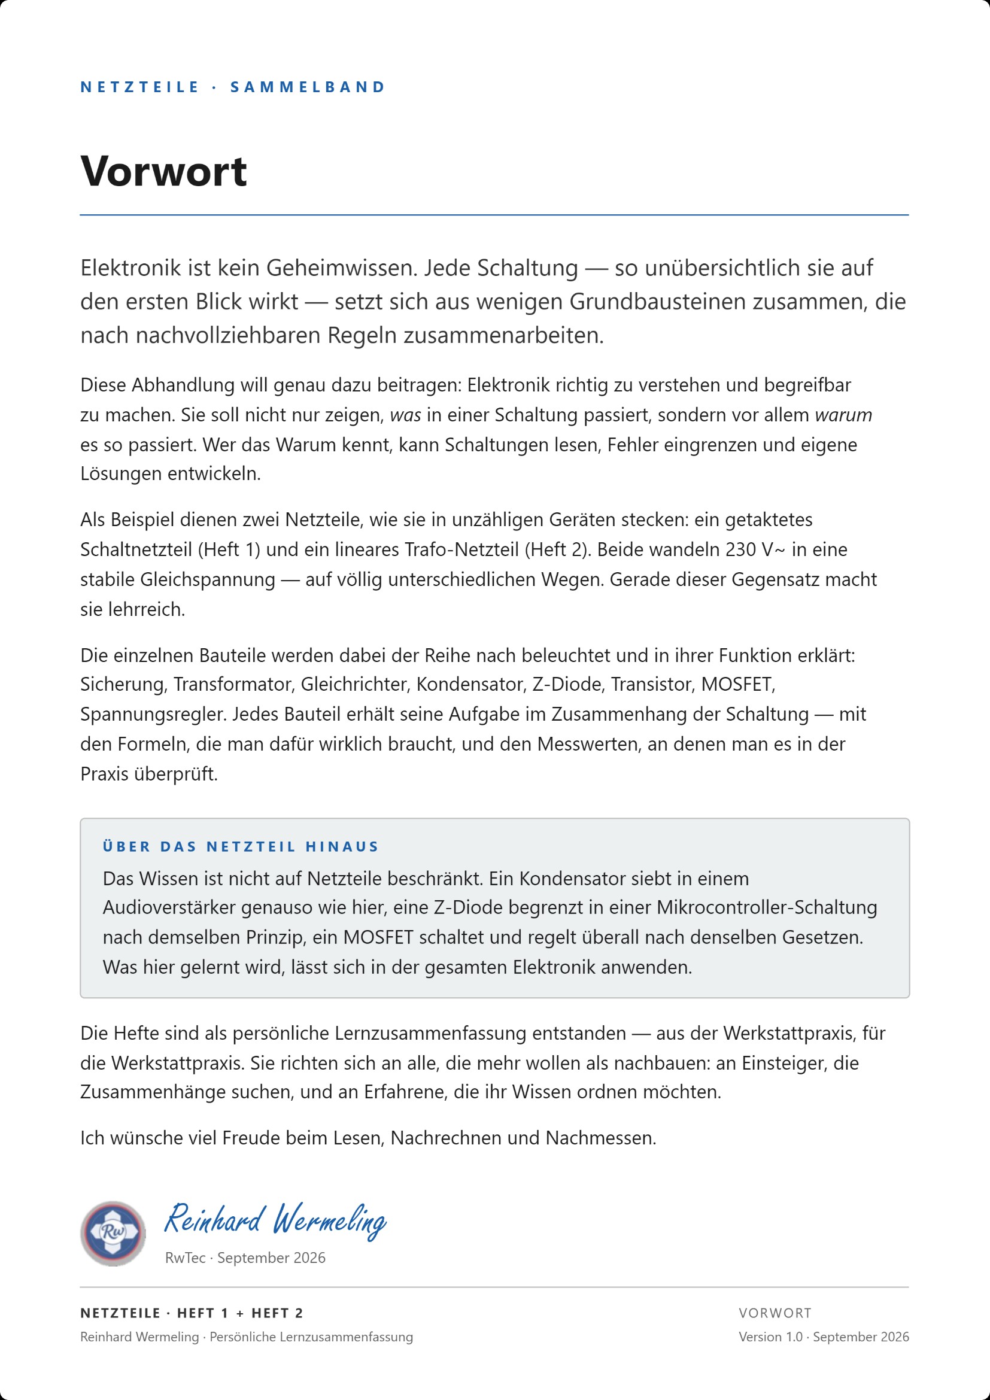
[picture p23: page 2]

### A B H A N D L U N G

HE F T 1 L E I S TUNGS E L EKTRONIK · L ERNRE IHE

# Schaltnetzteil verstehen

Flyback-Wandler mit UC384X — Auslegungsbeispiel 12 V / 2 A. Schaltbild, Anlauf, Regelung, Messung, Fehlersuche.

VERFAS S ER

## Reinhard Wermeling

Abb. 1 — Offenes Schaltnetzteil (PD-25, 100–240 V AC → 5 V / 12 V). Links Eingangsstufe und HV-Elko, Mitte der Flyback-Trafo, rechts Sekundärseite und Ausgangsfilter.

Das durchgehende Beispiel — ein handelsübliches 12-V-Netzteil — macht die Elektronik begreifbar: jeder Block im Schaltbild lässt sich am realen Gerät wiederfinden, messen und im Fehlerfall eingrenzen. Wer diesen einen Wandler versteht, erkennt das Prinzip in nahezu jedem modernen Netzteil wieder.

UMFANG
23 Kapitel in zwei Teilen — Grundlagen, Messung, Vertiefung

ZIEL
Netzgerät verstehen, messen und typische Defekte eingrenzen

SICHERHEIT
Primärseite: Lebensgefahr. Nur mit Trenntrafo messen.
HEFT 1 · SCHALTNETZTEIL VERSTEHEN | FLYBACK · UC384X · 12 V / 2 A
Reinhard Wermeling · Persönliche Lernzusammenfassung | Version 1.2 · 16. September 2026

# Inhalt

TEIL I | Aufbau, Funktion, Messung

0 Schaltbild (Referenz)
1 Einleitung
2 Überblick und Topologie
3 Eingangsstufe
4 Flyback-Wandler und Leistungspfad 5 PWM-Steuerung UC384X
6 Sekundärseite und Ausgang 12 V 7 Startverhalten

8 Regelkreis
9 Betriebspunkt 12 V / 2 A
10 Signalfluss und Merksätze
11 Glossar
12 Checkliste Messung und Fehlersuche 13 Oszilloskop-Messungen 12 V / 2 A 14 Typische Defekte und Bauteiltest
TEIL II | Vertiefung

15 Schaltnetzteil gegen Trafo-Netzteil
16 Der UC3842 im Detail
17 Der Flyback-Transformator
18 UC3842 und Flyback-Trafo im Zusammenspiel 19 Die Hilfswicklung: Anlasser und Lichtmaschine

20 MOSFET und „Ticken“ prüfen 21 Drosseln im Schaltnetzteil 22 Kondensatoren und Elkos 23 Dioden im Schaltnetzteil

Teil I folgt dem Schaltbild von links nach rechts und endet mit Messablauf und Fehlerbaum. Teil II vertieft einzelne Bauteile — jedes Kapitel dort ist für sich lesbar.

T E I L I

# Aufbau, Funktion und Messung

### Kapitel 0 bis 14 — vom Netzstecker über den Flyback-Trafo bis

zum Oszilloskop-Protokoll am Betriebspunkt 12 V / 2 A.

# 0 Schaltbild (Referenz)

Das folgende Schaltbild ist die Referenz für dieses Heft: Flyback-Topologie, UC384X als Steuer-IC, isolierte Rückkopplung. Die farbigen Bereiche entsprechen den Funktionsblöcken in den Kapiteln 2 bis 6.

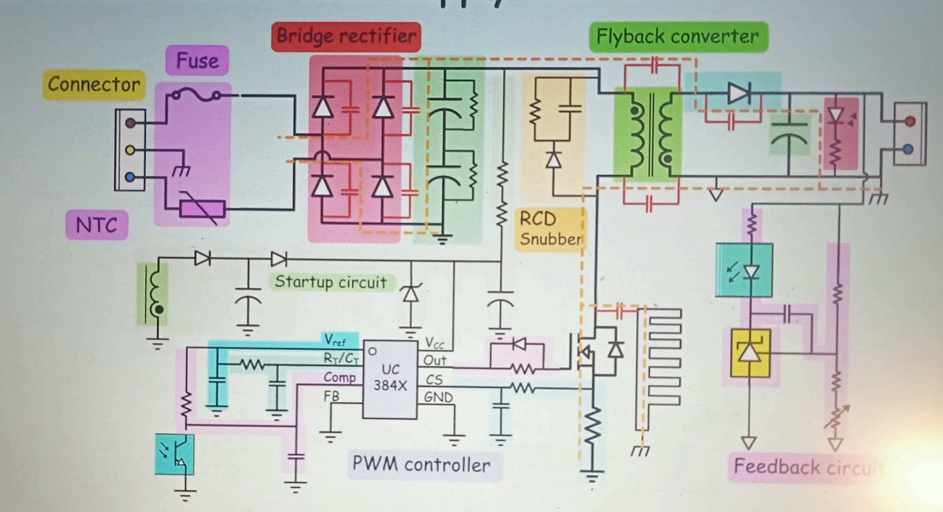
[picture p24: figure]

Abb. 2 — Referenzschaltbild mit farbig markierten Funktionsblöcken.

Bereich im Bild | Block
Links: Stecker, Sicherung, NTC | Eingangsschutz
Rot: vier Dioden | Brückengleichrichter
Grün (Eingang): Elkos | HV-Puffer
Mitte: Trafo, MOSFET, orange RCD | Flyback + Snubber
Unten: UC384X, Start, Hilfswicklung | PWM + Versorgung
Rechts oben: Diode, Elko, LED | Ausgang 12 V
Rechts unten: TL431, Opto, Teiler | Regelkreis

HINWEIS

Am Brückengleichrichter sind oft kleine Kondensatoren parallel zu den Dioden eingezeichnet. Sie dämpfen schnelle Spannungswechsel und mindern HF-Störungen (EMI) am Netzeingang.

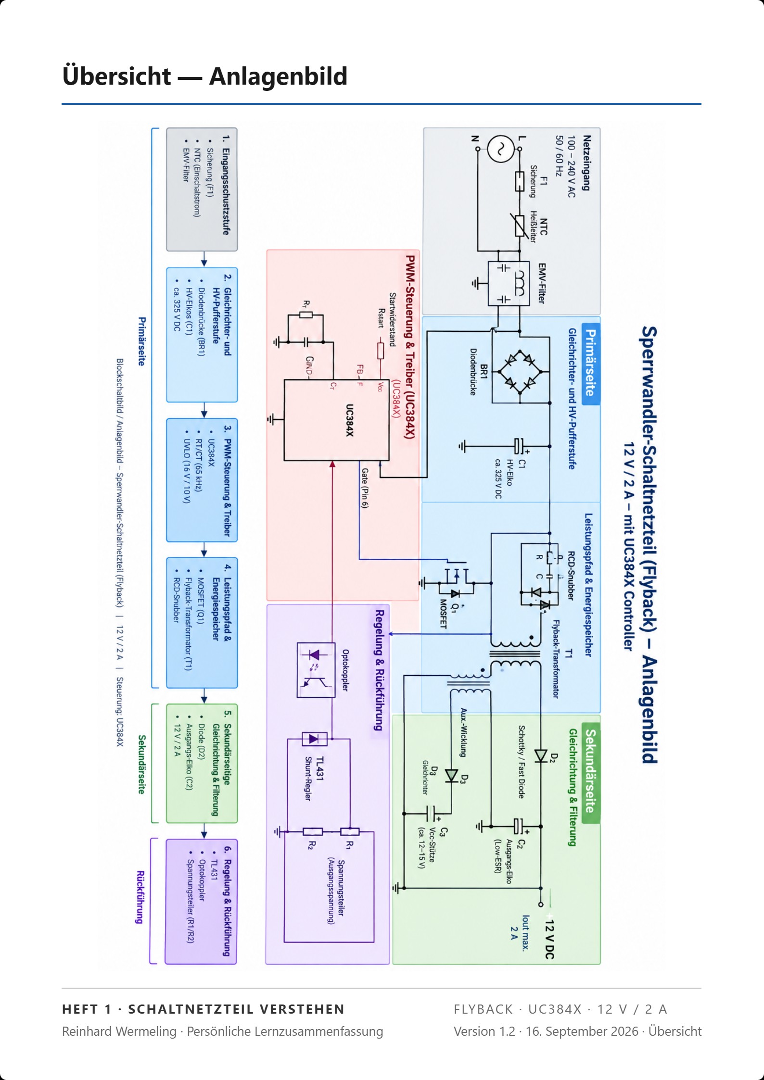
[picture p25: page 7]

# 1 Einleitung

Ein Schaltnetzteil (SMPS) wandelt Netzwechselspannung in eine geregelte Gleichspannung um — hier 12 V bei bis zu 2 A, also 24 W. Im Schaltbild wird die Flyback-Topologie mit dem Baustein UC384X realisiert.

Warum „Schalt“? Die Energieübertragung erfolgt nicht dauerhaft über einen Transformator im Dauerstrombetrieb, sondern in hochfrequenten Paketen, typisch im kHz-Bereich. Ein MOSFET schaltet die Primärwicklung; der Transformator speichert Energie und gibt sie ab — galvanisch getrennt zwischen Netzseite und Ausgang.

### Dieses Heft fasst zusammen

was jeder Block im Schaltbild macht,
wie Anlauf und Regelung zusammenspielen, Oszilloskop-Messungen am Betriebspunkt 12 V / 2 A, typische Defekte und Bauteilprüfung.

# 2 Überblick und Topologie

### 2.1 Funktionsblöcke (links nach rechts)

Block | Funktion
Netzanschluss | L, N, PE
Schutz (Sicherung, NTC) | Überstrom, Einschaltstrom begrenzen
Brückengleichrichter | AC zu pulsierender DC
Eingangsfilter / Elkos | Glättung zur HV-Gleichspannung
Flyback-Trafo + MOSFET | Energie paketweise übertragen
RCD-Snubber | Spannungsspitzen beim MOSFET-Aus dämpfen
UC384X | PWM, Stromgrenze, Regelung
Startschaltung / Hilfswicklung | Versorgung Vcc
Sekundär: Diode + Elko | HF zu 12 V DC
Rückkopplung: TL431 + Opto | Ausgang messen, isoliert regeln

### 2.2 FLYBACK IN EINEM SATZ

MOSFET ein: Energie im Magnetfeld der Primärwicklung. MOSFET aus: Feld kollabiert, die Sekundärwicklung liefert Strom in Ausgang und Elko.

# 3 Eingangsstufe

### 3.1 Sicherung

Schützt bei schweren Fehlern wie Kurzschluss oder defektem Halbleiter. Nach dem Durchbrennen zuerst die Ursache klären, dann neu einschalten.

### 3.2 NTC (Inrush-Limiter)

Große Eingangs-Elkos ziehen beim Einschalten einen Stromstoß. Der kalte NTC hat hohen Widerstand und dämpft ihn; nach Erwärmung ist der Widerstand niedrig, der Normalbetrieb wird kaum beeinträchtigt.

### 3.3 Brücke und HV-Puffer

Brücke: Vollwellengleichrichtung, ca. 325 V Spitze bei 230 V AC am leeren Puffer.
Elkos (ggf. mit Balancing-Widerständen): Glättung und Energiepuffer für jeden Schaltzyklus. Ab hier beginnt die Primär-HV-Schiene für den Wandler.

# 4 Flyback-Wandler und Leistungspfad

### 4.1 MOSFET

Der Leistungsschalter. Die Gate-Ansteuerung kommt vom Out-Pin des UC384X.

### 4.2 Strommesswiderstand (CS)

Kleiner Widerstand zwischen MOSFET-Source und Masse. Der Spannungsabfall geht an Pin CS: Überstrombegrenzung, oft zyklusweise Stromregelung (Peak-Current-Mode).

### 4.3 RCD-Snubber

Beim Abschalten des MOSFET entstehen durch Streuinduktivität schnelle Spannungsspitzen am Drain. R, C und D schützen MOSFET und Wicklungen.

### 4.4 Zwei Phasen pro Takt

Phase | MOSFET | Primär | Sekundär (typ. Flyback)
Ein | leitend | Strom steigt, Energie im Feld | Diode sperrt
Aus | sperrt | Feld bricht zusammen | Diode leitet in Elko und Last

# 5 PWM-Steuerung UC384X

Der UC384X (Familie UC3842/43/44/45) ist das Steuer-IC des Wandlers.

Pin | Rolle
Vcc / GND | IC-Versorgung
RT/CT | Schaltfrequenz über externe R/C
Out | Gate-Treiber zum MOSFET
CS | Primärstrom über Shunt
FB / Comp | Rückkopplung und Kompensation
Vref | Interne Referenz, typ. 5 V am REF-Pin

UVLO

Unterhalb einer Mindestspannung an Vcc schaltet der IC ab. Typisch: Start bei etwa 16 V, Abschalten bei etwa 10 V — die genauen Werte stehen im Datenblatt.

# 6 Sekundärseite und Ausgang 12 V

Die Sekundärwicklung liefert HF-Pulse.
Schnelle Gleichrichterdiode für hohen Wiederholungsstrom und kurze Reverse-Recovery.
Der Ausgangselko glättet auf 12 V DC.
LED optional als Betriebsanzeige.
Im Schaltbild: Spannungsteiler und Trimmer in der Rückkopplung zum Feinabgleich der 12 V — nur im unbelasteten oder definierten Lastzustand einstellen.
Primär und Sekundär sind über den Trafo galvanisch getrennt.

# 7 Startverhalten

### 7.1 Ablauf beim Netz-Einschalten

1. Die HV-Schiene lädt, im Millisekundenbereich.
2. Der UC384X ist noch aus, Vcc ist zu niedrig.
3. Startschaltung: ein hochohmiger Pfad von +HV lädt den Vcc-Elko.
4. Vcc überschreitet die Startschwelle, der IC oszilliert, der MOSFET schaltet.
5. Die Hilfswicklung übernimmt Vcc (Diode und Elko).
6. Der Ausgang lädt von 0 V — der Regelkreis fordert zunächst hohen Duty Cycle.

### 7.2 Start gegen Dauerbetrieb

Phase | Vcc-Quelle | Anmerkung
Vor erstem Takt | Startwiderstand von HV | Ladezeit abhängig von R, C, HV
Nach erstem Takt | Hilfswicklung, dominant | Vcc etwa 11 bis 15 V stabil
Vcc zu tief | UVLO | Stop, dann erneuter Start

### 7.3 Anlauf der 12 V

Leerer Ausgangselko: maximaler Duty bis zur CS-Grenze oder zum max. Duty.
Die 12 V rampen hoch, im Bereich Millisekunden bis Zehntel-Millisekunden. Möglich ist ein kleines Überschwingen beim Eintritt in den linearen Regelbereich.

### 7.4 Typische Startprobleme

Symptom | Mögliche Ursache
Hiccup (Ticken, Wiederstart) | Vcc-Elko altersschwach (ESR), Hilfswicklung, Startwiderstand
Kein Ausgang | Kein Oszillieren; MOSFET, Trafo, Diode; Regelkreis blockiert
Heißer Startwiderstand | Kurzzeitig normal; dauerhaft Dimensionierung prüfen

# 8 Regelkreis

### 8.1 Regelziel und Stellgröße

Soll sind 12 V am Ausgang. Stellgröße ist der Duty Cycle D.

### 8.2 Sekundär: TL431 und Spannungsteiler

Der Teiler skaliert die 12 V auf etwa 2,5 V am REF-Pin der TL431:

Vout · Rlower / (Rupper + Rlower) ≈ 2,5 V

Ausgang zu hoch: die TL431 leitet stärker, mehr Opto-LED-Strom. Ausgang zu niedrig: weniger LED-Strom.

### 8.3 Optokoppler zum UC384X

Der Fototransistor auf der Primärseite zieht Comp bzw. FB — ohne galvanische Verbindung zur 12-V-Seite.

### 8.4 Kompensation (Comp)

Das RC-Glied an Comp verhindert Schwingen bei Last- und Netzänderungen.

### 8.5 Lastverhalten bei 12 V / 2 A

Situation | Erwartung
Leerlauf | Kleiner Duty
0 bis 2 A | Duty passt sich an
Sprung 0 auf 2 A | Kurzer Einbruch, dann Nachregelung
Netz schwankt | Duty-Korrektur

# 9 Betriebspunkt 12 V / 2 A

AUSGANGSLEISTUNG

## 24 W

WIRKUNGSGRAD (TYP.)
75 – 85 %

PRIMÄRLEISTUNG
28 – 32 W

NETZSTROM BEI 230 V (GROB)
130 – 150 mA

HV-PUFFER

## ~325 V Spitze

SCHALTFREQUENZ (BEISPIEL)

## 65 kHz

Bei 2 A Dauerlast müssen Trafo, MOSFET, Diode, Elkos und Kühlung die Verluste dauerhaft abführen. CS soll bei Volllast noch Reserve vor der Begrenzung haben.

TAF E L ZU KAP I T E L 1 0
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

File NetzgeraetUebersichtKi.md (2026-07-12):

# Netzgerät (OB2263‑Sperrwandler) — Gesamtübersicht

*Startseite und Wegweiser durch die komplette Dokumentation — ein Werkstattbericht*

> **Kurzfassung:** Diese Seite bündelt alles, was wir zum 12‑V‑Schaltnetzteil erarbeitet haben, in drei Schritten: ==Verstehen → Prüfen → Simulieren==. Unten findest du ein Inhaltsverzeichnis, zu jeder Datei eine Notiz mit ihrem Inhalt und einen empfohlenen Lernpfad. Die Startdatei zum Reinlesen ist immer `NetzgeraetKi.md`.

Projektkarte der Netzgerät-Dokumentation

---
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

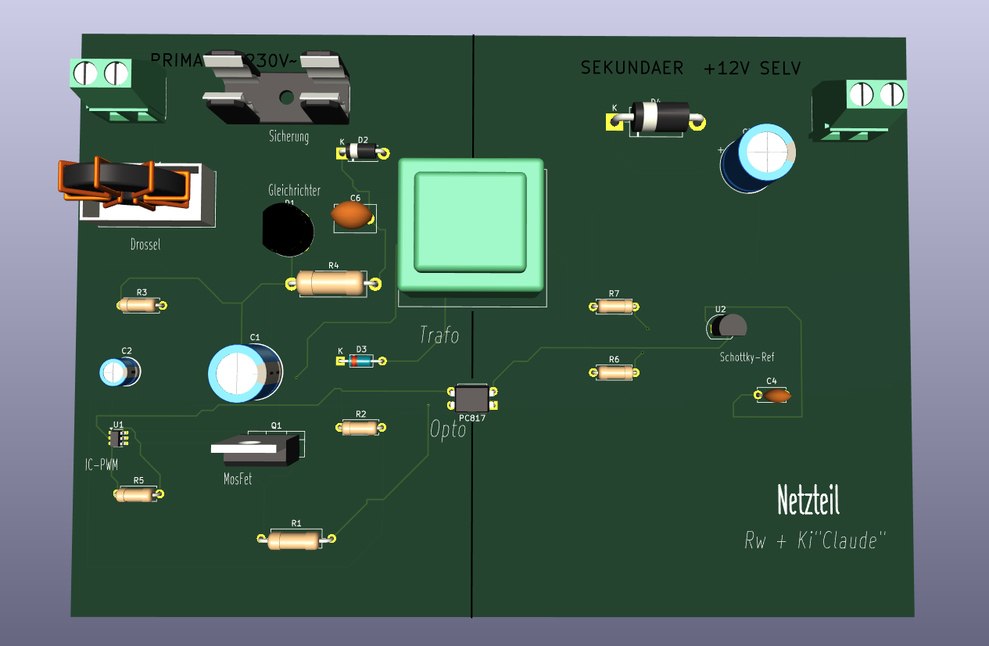
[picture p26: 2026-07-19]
PlatineBeschr.png

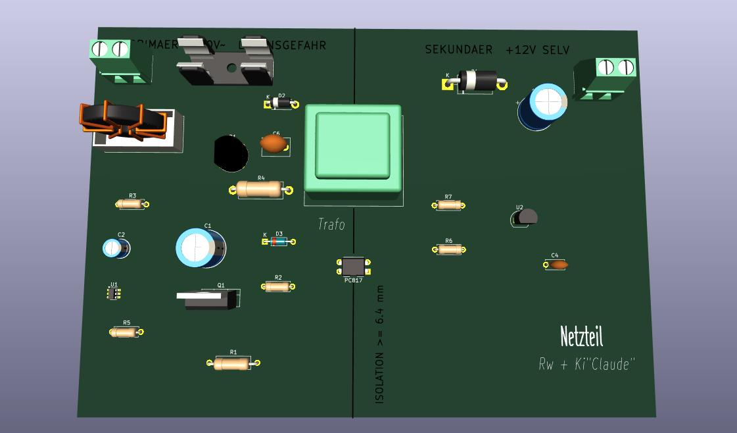
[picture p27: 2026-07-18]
PlatineAnsicht.jpg

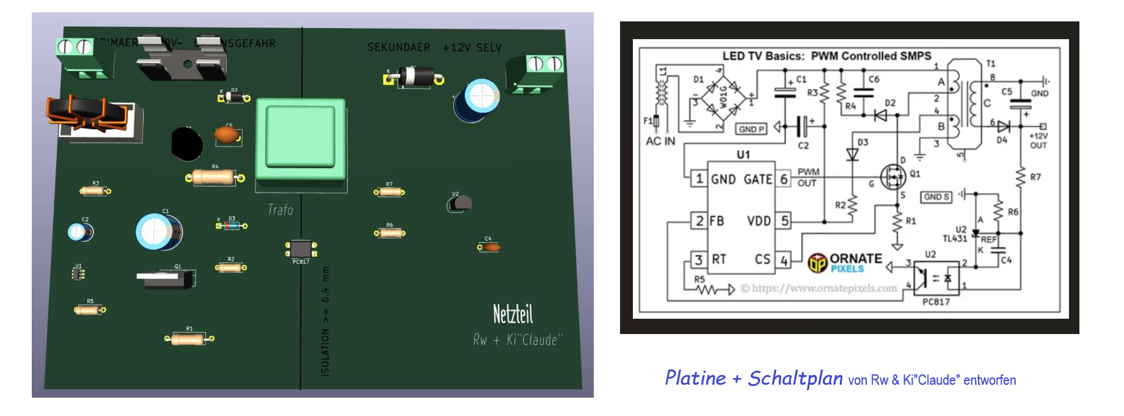
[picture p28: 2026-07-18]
PlatineGesamt.png

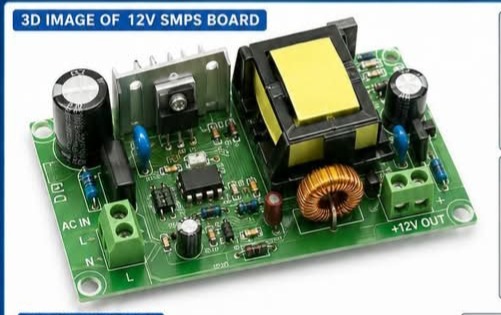
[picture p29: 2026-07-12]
PlatineKl.JPG

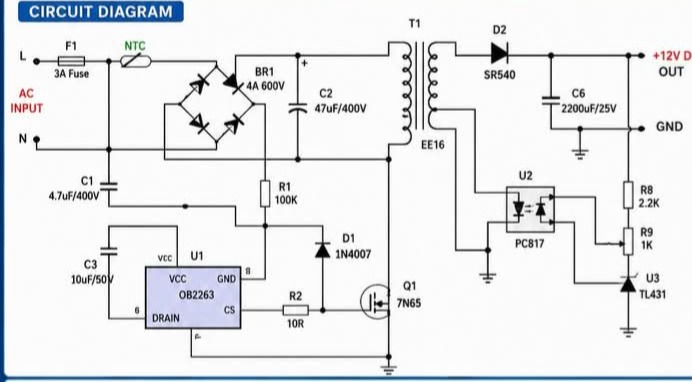
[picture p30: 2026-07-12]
SchaltplanKl.JPG

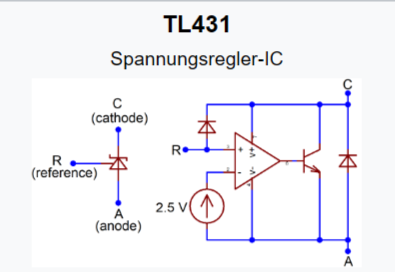
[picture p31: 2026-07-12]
TL431.png

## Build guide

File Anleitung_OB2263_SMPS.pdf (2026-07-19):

# Umfassendes Handbuch: Flyback-Schaltnetzteil (SMPS) mit PWM-Controller OB2263

Dieses Handbuch dokumentiert detailliert die Funktionsweise, die Schaltungsauslegung, die Stückliste (BOM) sowie Strategien zur Fehlersuche für das hocheffiziente, PWM-gesteuerte Flyback-Schaltnetzteil (Sperrwandler), welches auf dem Controller-IC OB2263 (bzw. DP2263) basiert und eine stabile Ausgangsspannung von +12V DC liefert.

## Inhaltsverzeichnis

1. Sicherheits- und Warnhinweise
2. Schaltungsunterlagen & Bilddokumentation
3. Funktionsgruppen & Technische Kapitel
1. Systemüberblick & Sperrwandler-Prinzip
2. EMV-Netzfilter & Gleichrichtung
3. Einschaltphase & Hilfsstromversorgung (Startup/VDD)
4. Der PWM-Controller OB2263 im Detail
5. Leistungsstufe & RCD-Snubber
6. Isolierte Spannungsregelung & Feedback-Schleife
7. Sekundärseitige Gleichrichtung & Glättung
4. Bauteil-Stückliste (Bill of Materials - BOM)
5. Anleitung zur Fehlersuche & Reparatur (Troubleshooting)
6. PCB-Design & Layout-Empfehlungen

## Sicherheits- und Warnhinweise

[!WARNING]
LEBENSGEFAHR DURCH ELEKTRISCHEN SCHLAG!
Dieses Schaltnetzteil arbeitet auf der Primärseite mit gefährlichen Netzspannungen von 230V AC und internen Gleichspannungen von bis zu 325V DC (am Primär-Ladekondensator C1).

Trennen Sie das Gerät vor jeglichen Arbeiten vollständig vom Stromnetz. Entladungszeit beachten: Der Primärkondensator C1 kann die gefährliche Hochspannung (325V) auch Minuten nach dem Trennen vom Netz speichern. Messen Sie stets die Spannung über C1 und entladen Sie ihn kontrolliert über einen geeigneten Entladewiderstand (z. B. 1 kΩ / 5W), bevor Sie Kontakte berühren.
Galvanische Trennung: Verwenden Sie bei Messungen an der aktiven Primärseite zwingend einen Trenntransformator und ein differentielles Tastkopfsystem. Schließen Sie niemals die Masse Ihres Oszilloskops direkt an die Primärmasse (GND_P) an, da dies zu einem Kurzschluss führt.

## Schaltungsunterlagen & Bilddokumentation

Bestückte Platine (mit Beschriftung)

Hier sehen Sie die fertig aufgebaute Platine des Flyback-Schaltnetzteils mit allen beschrifteten Hauptkomponenten:


Prinzipschaltplan (Flyback SMPS)

Hier sehen Sie das vollständige Schaltbild des Sperrwandlers basierend auf dem OB2263:


## Funktionsgruppen & Technische Kapitel

1. Systemüberblick & Sperrwandler-Prinzip

Ein Schaltnetzteil (engl. Switched-Mode Power Supply, SMPS) wandelt elektrische Energie hocheffizient um. Im Gegensatz zu herkömmlichen Linearnetzteilen, die überschüssige Spannung an Längsreglern in Verlustwärme umsetzen, arbeitet dieses System nach dem Sperrwandler-Prinzip (Flyback Converter).

Als zentraler Steuerbaustein dient das hochentwickelte PWM-Controller-IC OB2263 (bzw. DP2263). Es regelt den Leistungstransistor Q1 (N-Kanal-MOSFET) mit einer festen Arbeitsfrequenz von 65 kHz. Der wesentliche Vorteil dieser hohen Schaltfrequenz liegt darin, dass der Transformator T1 mit einem wesentlich kleineren Ferritkern betrieben werden kann als ein herkömmlicher 50Hz-Netztrafo mit schwerem Eisenkern.

Das System lässt sich funktional in folgende Blöcke unterteilen:

1. Eingangsfilter & Gleichrichtung: Filterung von EMI-Störungen und Erzeugung der DC-Busspannung (~325V DC).
2. Steuerelektronik (PWM U1): Taktgenerierung, Schutzschaltungen und Auswertung des Regelkreises.
3. Leistungsschalter & Transformator: Getakteter Stromfluss durch die Primärwicklung zur Energieübertragung.
4. Ausgangskreis: Gleichrichtung der sekundärseitig induzierten Impulse und Glättung zu stabilen +12V DC.
5. Isolierter Regelkreis: Rückführung der Ausgangsspannung über TL431 und Optokoppler PC817 zur Pulsweitenregelung unter Gewährleistung absoluter galvanischer Trennung.

2. EMV-Netzfilter & Gleichrichtung

Die Wechselspannung aus dem öffentlichen Netz (typisch 230 V AC, 50 Hz) gelangt über die Schmelzsicherung F1 zur EMV-Filterstufe.

Die Gleichtaktdrossel L1 (auch als EMV-Filtertransformator bezeichnet) besitzt zwei gegensinnig gewickelte Spulen auf einem gemeinsamen Kern. Sie hat folgende Hauptaufgaben:

Blockade von Gleichtaktstörungen: Ströme, die sich gleichphasig auf Phase und Neutralleiter ausbreiten (z. B. eingekoppelte Gewitterstörungen oder hochfrequenter Elektrosmog), erzeugen im Kern Magnetfelder, die sich addieren. Dadurch wirkt L1 für diese Störsignale wie eine extrem hohe Impedanz und blockiert sie.
Durchlass des Nutzstroms: Der normale Betriebsstrom fließt auf dem einen Leiter hin und auf dem anderen zurück (Gegentaktstrom). Die erzeugten Magnetfelder im Kern heben sich gegenseitig auf, sodass L1 für den 50Hz-Betriebsstrom nahezu unsichtbar ist.
Rückwirkungsschutz: Sie verhindert, dass die durch das schnelle Schalten des MOSFETs Q1 entstehenden hochfrequenten Oberwellen zurück in das Hausnetz gelangen und andere Geräte stören (Einhaltung der EMV-Richtlinien).

Nach der Filterung wandelt der Brückengleichrichter D1 (Bestehend aus vier Siliziumdioden in Grätz-Schaltung, z. B. Typ W01G) die AC-Wechselspannung in pulsierende DC-Gleichspannung um. Diese wird im Ladekondensator C1 (Primär-Elko) zwischengespeichert und geglättet. An C1 liegt nun die sogenannte DC-Busspannung an. Bei einer Netzspannung von 230 V AC beträgt diese theoretisch:

$$V_{DC} = V_{AC} cdot sqrt{2} approx 230 ext{ V} cdot 1,414 approx 325 ext{ V DC}$$

Unter realer Last schwankt dieser Wert (Rippelspannung) je nach Kapazität von C1 zwischen ca. 280 V und 325 V DC.

3. Einschaltphase & Hilfsstromversorgung (Startup/VDD)

Beim Anlegen der Netzspannung ist das PWM-IC U1 noch stromlos und schaltet nicht. Um den Betrieb aufzunehmen, benötigt es eine Versorgungsspannung am VDD-Pin (Pin 5) von mindestens 14,5 V (UVLO On-Schwelle).

Hierzu dient der Anlaufwiderstand R3 (~82 kΩ). Er verbindet den positiven Pol von C1 direkt mit dem VDD-Pin.

Die Einschaltphase (Startup): Ein kleiner Strom (wenige Mikroampere) fließt über R3 und lädt den Stützkondensator C2 langsam auf. Sobald die Spannung an C2 die Start-Schwelle von ca. 14,5 V erreicht, wacht das IC auf und beginnt, PWM-Signale am Gate-Pin (Pin 6) auszugeben. Der MOSFET Q1 schaltet nun ein und aus, das Netzteil beginnt zu schwingen.
Dauerversorgung (Normalbetrieb): Würde man das IC dauerhaft über R3 versorgen, entstünde an R3 ein unnötig hoher Leistungsverlust:

$$P_{ ext{verlust}} = rac{(V_{ ext{bus}} - V_{ ext{DD}})^2}{R3} = rac{(325 ext{ V} - 15 ext{ V})^2}{82 ext{ k}Omega} approx 1,17 ext{ W}$$

Dieser Verlust würde im Standby-Betrieb einen extrem schlechten Wirkungsgrad verursachen und den Widerstand im Dauerbetrieb überhitzen. Daher besitzt der Haupttransformator T1 eine Hilfswicklung B.

Halbwellengleichrichtung: Während der Sperrphase des MOSFETs Q1 wird in der Spule B eine Wechselspannung induziert. Die Diode D3 richtet diese Spannung gleich, und der Widerstand R2 begrenzt Spitzenströme und filtert hochfrequentes Rauschen. Diese erzeugte Hilfsspannung lädt C2 auf ein stabiles Niveau von ca. 12 V bis 15 V auf. Da diese Spannung nun höher ist als die Mindestbetriebsspannung des ICs, übernimmt die Hilfswicklung komplett die Stromversorgung des ICs. R3 liefert weiterhin einen vernachlässigbar kleinen Strom, während das IC hocheffizient läuft.

4. Der PWM-Controller OB2263 im Detail

Das PWM-IC OB2263 (U1) regelt die Pulsweite des Treibersignals für den MOSFET. Es arbeitet nach dem Current-Mode-Control-Verfahren. Das bedeutet, dass nicht nur die Ausgangsspannung überwacht wird, sondern im laufenden Taktzyklus auch der fließende Strom durch den Leistungspfad gemessen und als direkte Regelgröße herangezogen wird.

Pinbelegung des OB2263 (SOT23-6 / DIP-8)

1. Pin 1 (GND): Referenzmasse für die gesamte primärseitige Elektronik.
2. Pin 2 (FB - Feedback): Hier wird das optisch isolierte Regelsignal des Optokopplers PC817 eingespeist. Der interne Schaltkreis des ICs vergleicht diese Spannung mit einer internen Schwelle. Sinkt die FB-Spannung gegen Masse (Optokoppler leitet stark, d.h. Ausgangsspannung zu hoch), verringert das IC das Tastverhältnis (Duty Cycle). Steigt die FB-Spannung (Optokoppler sperrt, d.h. Ausgangsspannung bricht ein), erhöht das IC das Tastverhältnis, um mehr Energie zu übertragen.
3. Pin 3 (RT): Ein externer Widerstand R5 (typisch 100 kΩ) bestimmt die Arbeitsfrequenz des internen Oszillators. Bei 100 kΩ schaltet das Netzteil mit 65 kHz. Das IC verfügt über ein integriertes Frequenz-Jittering: Die Schaltfrequenz schwankt minimal um den Sollwert, wodurch sich die EMI-Störstrahlung über ein breiteres Frequenzband verteilt und die EMV-Filterung erleichtert wird.
4. Pin 4 (CS - Current Sense): Dieser Pin überwacht den Strom durch den MOSFET Q1 über den Shunt-Widerstand R1 (0,22 Ω). Erreicht die am CS-Pin anliegende Spannung im aktuellen Schaltzyklus einen bestimmten Grenzwert (typisch maximal 0,75 V bis 0,85 V), schaltet das IC den GATE-Ausgang sofort ab. Dies schützt den MOSFET effektiv vor Zerstörung durch Sättigung des Trafokerns.
5. Pin 5 (VDD): Stromversorgungseingang des ICs (Startup-Schwelle: >14,5 V, Betrieb: ca. 12-15 V, Abschaltung bei Unterspannung (UVLO): < 9,0 V).
6. Pin 6 (GATE): Der Ausgang des internen Push-Pull-Treibers. Er liefert scharfkantige Rechteckimpulse mit ausreichender Stromstärke (bis zu mehreren hundert Milliampere), um die Gate-Kapazität des MOSFETs Q1 blitzschnell umzuladen und Schaltverluste extrem gering zu halten.
5. Leistungsstufe & RCD-Snubber

Die Leistungsstufe besteht aus dem N-Kanal-MOSFET Q1, dem Flyback-Transformator T1 und dem RCD-Snubber-Netzwerk (D2, C6, R4).

Einschaltphase des MOSFETs ($T_{ ext{on}}$): Liefert Pin 6 von U1 ein Logisch-1-Signal, schaltet Q1 ein. Die primäre Busspannung liegt nun fast vollständig über der Primärwicklung A von T1 an. Der Strom durch die Primärwicklung steigt linear an. Da die sekundärseitige Gleichrichterdiode D4 in dieser Phase sperrt (Sperrwandler-Prinzip!), fließt sekundärseitig kein Strom. Die elektrische Energie wird als magnetische Energie im Luftspalt des Ferritkerns von T1 gespeichert. Ausschaltphase des MOSFETs ($T_{ ext{off}}$): Schaltet das PWM-Signal auf Logisch-0, sperrt Q1 abrupt. Der Stromfluss durch die Primärwicklung reißt ab. Das zusammenbrechende Magnetfeld induziert nun in allen Wicklungen von T1 Spannungen mit umgekehrter Polarität. Jetzt öffnet die Sekundärdiode D4, und die im Kern gespeicherte Energie entlädt sich in Form eines abklingenden Stroms über D4 in den Ausgangskondensator C5 und an die angeschlossene Last.
Das Problem der Streuinduktivität: Kein Transformator ist perfekt gekoppelt. Ein kleiner Teil des magnetischen Feldes der Primärspule ist nicht mit der Sekundärspule gekoppelt (Streuinduktivität). Beim Abschalten des MOSFETs kann diese Energie nicht auf die Sekundärseite übertragen werden und erzeugt an der Primärseite eine extrem hohe, extrem schnelle Spannungsspitze (Spike). Diese Spitze addiert sich zur Busspannung und kann die maximale Drain-Source-Spannung von Q1 (z. B. 600V beim 4N60) überschreiten, was zum sofortigen Durchbruch des Transistors führt.
Schutz durch den RCD-Snubber: Das Netzwerk aus D2, C6 und R4 schützt den MOSFET. Im Moment des Ausschaltens wird die gefährliche Spannungsspitze über die schnelle Diode D2 in den Snubber-Kondensator C6 geleitet. C6 absorbiert den Stoß, wodurch die Spannung am Drain-Pin sicher geklemmt wird (typischerweise auf ca. 450V bis 500V). In der anschließenden Einschaltphase entlädt sich C6 kontrolliert über den Leistungswiderstand R4, sodass er beim nächsten Ausschalten wieder aufnahmebereit ist.
6. Isolierte Spannungsregelung & Feedback-Schleife

Um die Ausgangsspannung exakt auf +12 V DC zu halten, muss jede Abweichung sofort an die Primärseite zurückgemeldet werden. Gleichzeitig verbieten Sicherheitsvorschriften eine direkte elektrische Verbindung zwischen dem lebensgefährlichen Primärkreis (Netzspannung) und dem berührbaren Sekundärkreis. Diese galvanische Trennung wird durch den Optokoppler PC817 (U3) realisiert.

Die Regelung funktioniert im Detail wie folgt:

Spannungsteiler R7 / R6: Diese Widerstände teilen die Ausgangsspannung herunter. Am Mittelpunkt liegt der REF-Pin der Präzisions-Referenzquelle TL431 (U2) an.
TL431 als Fehlerverstärker: Der TL431 vergleicht die geteilte Spannung mit einer hochstabilen internen Referenz von exakt 2,5 V.
Steigt die Ausgangsspannung über 12,0 V, überschreitet die Spannung an REF die 2,5 V-Schwelle. Der TL431 schaltet durch und leitet Strom von seiner Kathode zur Anode gegen Sekundär-Masse.
Sinkt die Ausgangsspannung unter 12,0 V, sperrt der TL431.
Optokoppler-Kopplung: Der vom TL431 gezogene Strom fließt direkt durch die eingebaute Infrarot-LED des PC817 (Pins 1 und 2). Je höher die Ausgangsspannung, desto heller leuchtet diese LED. Das emittierte Infrarotlicht gelangt auf den primärseitigen Fototransistor des Optokopplers (Pins 3 und 4).
PWM-Anpassung: Der Fototransistor leitet den Strom proportional zur Lichtstärke von Pin 2 (FB) des PWM-ICs gegen Primär-Masse ab. Ein starkes Leuchten zieht die FB-Spannung nach unten. Das

IC erkennt dies und verkürzt die Einschaltdauer des MOSFETs (Duty Cycle verringert sich). Es wird weniger Energie übertragen, und die Ausgangsspannung sinkt wieder auf den Sollwert von 12V.

$$V_{ ext{out}} = 2,5 ext{ V} cdot left(1 + rac{R7}{R6}
ight) = 2,5 ext{ V} cdot left(1 + rac{38 ext{ k}Omega}{10 ext{ k}Omega}
ight) = 2,5 ext{ V} cdot 4,8 = 12,0 ext{ V DC}$$

Frequenzkompensation (C4): Der Kondensator C4 bildet zusammen mit dem TL431 ein frequenzkompensiertes Regelverhalten (PI-Charakteristik). Er dämpft schnelle Störungen und verhindert, dass der Regelkreis anfängt zu schwingen, was sich in pfeifenden Geräuschen des Trafos oder einer instabilen Ausgangsspannung äußern würde.

7. Sekundärseitige Gleichrichtung & Glättung

Die in der Sekundärwicklung C induzierten hochfrequenten Rechteck-Spannungsimpulse müssen im letzten Schritt in eine stabile, saubere Gleichspannung umgewandelt werden.

Dies übernehmen die folgenden Komponenten:

Die Schottky-Diode D4: Sie dient als Gleichrichterdiode. Da das Netzteil mit 65 kHz arbeitet, würde eine normale Siliziumdiode (wie z. B. eine 1N4007) versagen. Gewöhnliche Dioden haben eine zu lange Sperrverzögerungszeit (Reverse Recovery Time) von mehreren Mikrosekunden. Sie würden in Sperrrichtung noch leiten, wenn der MOSFET bereits wieder einschaltet, was zu extremen Verlusten und zur sofortigen Zerstörung führen würde. Die verwendete Schottky-Diode SR360 zeichnet sich durch extrem schnelles Schalten (nahezu ohne Sperrverzögerungszeit) und eine geringe Schwellenspannung ($V_f approx 0,4 ext{ V}$ im Vergleich zu $0,7 ext{ V}$ bei Standarddioden) aus. Dadurch wird die Verlustleistung minimiert.
Der Ausgangs-Glättungskondensator C5: Er pufferert die von D4 durchgelassenen Strompulse und glättet sie zu einer stabilen +12V DC-Ausgangsspannung. Da die Ladeimpulse mit 65 kHz eintreffen, muss C5 ein Low-ESR-Elektrolytkondensator sein. Ein geringer äquivalenter Serienwiderstand (ESR) verhindert, dass sich der Kondensator durch die hochfrequenten Rippelströme stark erwärmt und frühzeitig austrocknet oder beschädigt wird.
Zusammenwirken: Die harmonische Abstimmung von T1, der ultraschnellen Diode D4 und dem Low-ESR-Elko C5 sorgt dafür, dass am Ausgang eine hochstabile Spannung mit minimalem Rauschen (Rippel typisch < 50 mVss) bereitgestellt wird, welche die nachfolgende LED-Hintergrundbeleuchtung oder Steuerplatinen des Fernsehers perfekt versorgt.

## Bauteil-Stückliste (Bill of Materials - BOM)

Referenz Bauteilname / Typ Kategorie Funktion

Technische
Spezifikationen
F1 | Schmelzsicherung | Eingang | Überstromschutz | 250V / 2A Träge
L1 | Gleichtaktdrossel | Eingang | Netzfilterung (EMV) | 10mH - 30mH EMV- Filter

Referenz Bauteilname / Typ Kategorie Funktion

Technische
Spezifikationen
D1 | Brückengleichrichter | Eingang | AC-DC Gleichrichtung | W01G (600V / 1A)
C1 | Elektrolytkondensator | Eingang | Glättung Busspannung | 47µF - 100µF / 400V Elko
R3 | Metallschichtwiderstand Leistung
| | | Anlaufwiderstand (Startup) | 82 kΩ / 0.5W
C2 | Elektrolytkondensator | Steuerung VDD-Pufferung des U1
| | | | 10µF - 22µF / 50V Elko
U1 | OB2263 (DIP-8 / SOT23- 6)
Steuerung PWM-Controller-IC
| | | | OB2263 SOT23-6 / DIP-8
R5 | Metallfilmwiderstand | Steuerung | Frequenzeinstellung (RT) | 100 kΩ / 1% Metallfilm
Q1 | N-Kanal MOSFET | Leistung | Primärer Schalttransistor | 4N60 (600V / 4A, $R_{DS(on)} approx 2.2Omega$)
R1 | Metallschichtwiderstand Leistung | Strommess-Shunt (CS) | 0.22 Ω / 1W
T1 | Flyback-Transformator | Leistung | Energieübertragung | EE25/EE20 Ferrit-Kern
D2 | Fast Recovery Diode | Leistung | Snubber-Diode | FR107 (1000V / 1A Fast Recovery)
C6 | Keramikkondensator | Leistung | Snubber-Kondensator | 2.2nF / 1kV
R4 | Leistungswiderstand | Leistung | Snubber- Entladewiderstand | 100 kΩ / 2W Leistungswiderstand
D3 | Diode (1N4148 / FR102) Steuerung Hilfsgleichrichter (VDD) | 1N4148 oder FR102
R2 | Kohleschichtwiderstand | Steuerung | VDD- Begrenzungswiderstand | 10 Ω / 0.25W
D4 | Schottky-Diode | Ausgang | Sekundärgleichrichter | SR360 (60V / 3A Schottky-Diode)
C5 | Low-ESR Elko | Ausgang | Ausgangs- Filterkondensator | 1000µF / 25V Low- ESR Elko
R7 | Metallfilmwiderstand | Regelung | Feedback- Spannungsteiler High | 38 kΩ / 1% Präzisionswiderstand
R6 | Metallfilmwiderstand | Regelung | Feedback- Spannungsteiler Low | 10 kΩ / 1% Präzisionswiderstand

Referenz Bauteilname / Typ Kategorie Funktion

Technische
Spezifikationen
U2 | TL431 | Regelung

Präzisions-Referenzregler

TL431 TO-92 / SOT-23

C4 | Keramikkondensator | Regelung

Regelkreis-Kompensation

100nF / 50V
Vielschicht-Keramik
U3 | PC817 (DIP-4) | Regelung

Optokoppler
(Isolierung)

PC817 DIP-4 (5kV
Isolationsspannung)

## Anleitung zur Fehlersuche & Reparatur (Troubleshooting)

Symptom 1: Das Netzteil ist komplett tot. Die Sicherung F1 ist durchgebrannt.

Mögliche Ursache: Schwerer Kurzschluss auf der Primärseite. Meistens ist der Leistungstransistor MOSFET Q1 kurzgeschlossen (Drain-Source-Schluss), wodurch ein unbegrenzter Strom über die Primärwicklung floss. Auch der Brückengleichrichter D1 oder der Primär-Elko C1 könnten einen
| Durchschlag haben.
Überprüfung (NUR im stromlosen Zustand!):
1. Entladen Sie C1 kontrolliert.
2. Messen Sie mit dem Multimeter im Widerstandsmessbereich / Diodentest zwischen Drain und Source von Q1. Ist der Wert nahe $0,Omega$, ist der MOSFET durchgeschlagen.
3. Prüfen Sie die vier Dioden des Brückengleichrichters D1. Jede Diode darf nur in eine Richtung eine Flussspannung von ca. 0,5 - 0,7 V anzeigen.
| Lösung:
Ersetzen Sie den defekten MOSFET Q1.
Ersetzen Sie das PWM-IC U1 (da der Gate-Treiber durch den MOSFET-Defekt über das Gate
| fast immer mitzerstört wird).
Ersetzen Sie den Strommesswiderstand R1 (er brennt bei Q1-Schluss fast immer hochohmig durch und wirkt als Sicherung).
Ersetzen Sie ggf. den defekten Brückengleichrichter D1 und setzen Sie erst ganz zum Schluss
| eine neue Sicherung F1 ein.
Symptom 2: Das Netzteil ist tot, aber die Sicherung F1 ist intakt. Am Primärkondensator C1 liegen ca. 325V DC an.

Mögliche Ursache: Das PWM-IC U1 erhält keinen Startstrom. Der Anlaufwiderstand R3 (82 kΩ) ist hochohmig geworden (Alterung oder Überhitzung) oder der VDD-Glättungskondensator C2 hat einen internen Kurzschluss gegen Masse.
| Überprüfung:
1. Messen Sie vorsichtig die Spannung an Pin 5 (VDD) des U1 gegen Primärmasse (GND_P).
2. Liegt diese bei nahe 0V, trennen Sie das Netzteil, entladen Sie C1 und löten Sie ein Bein von
| R3 aus.
3. Messen Sie den Widerstand von R3. Ist er hochohmig (unendlich), liegt der Fehler hier.

Lösung: Ersetzen Sie den defekten Anlaufwiderstand R3. Verwenden Sie vorzugsweise einen schwer entflammbaren Metallschichtwiderstand (Sicherheitswiderstand) mit mindestens 0,5 W Belastbarkeit. Tauschen Sie C2 vorsorglich mit aus.
Symptom 3: Das Netzteil versucht zu starten, pumpt aber periodisch (Ausgangsspannung schwankt im Sekundentakt, leises Klicken oder Ticken hörbar).

Mögliche Ursache: Das IC befindet sich im "Hiccup-Mode" (Schluckauf-Modus). Dies ist eine Schutzfunktion des OB2263 bei Überlast, Kurzschluss oder unzureichender Eigenversorgung. Typische Fehlerquellen sind eine defekte Sekundär-Gleichrichterdiode D4 (Kurzschluss), ein gealterter VDD-Kondensator C2 (Kapazitätsverlust) oder ein Kurzschluss in der nachfolgenden Verbraucherschaltung.
Überprüfung:
1. Messen Sie im stromlosen Zustand den Widerstand direkt am Ausgang (+12V OUT gegen GND_S). Ist dieser sehr niederohmig (nahe $0,Omega$), liegt ein Kurzschluss vor.
2. Prüfen Sie die Schottky-Diode D4 im Diodentest. Zeigt sie in beide Richtungen Durchlass, ist sie defekt.
3. Ist der Ausgangswirkwiderstand normal, prüfen Sie die Kapazität und den ESR des VDD-Kondensators C2. Hat er Kapazität verloren, bricht die VDD-Spannung nach dem ersten Schaltimpuls zusammen, bevor die Hilfswicklung die Versorgung übernehmen kann. Lösung:
Ersetzen Sie bei sekundärseitigem Kurzschluss die Diode D4 (unbedingt wieder eine schnelle Schottky-Diode wie SR360 verwenden!).
Tauschen Sie defekte Ausgangsfilter-Elkos C5 (stets Low-ESR-Typen mit $105^circ ext{C}$ Spezifikation wählen).
Ersetzen Sie den gealterten VDD-Elko C2.
Symptom 4: Die Ausgangsspannung ist viel zu hoch, viel zu niedrig oder schwankt stark unter Last. Der Transformator gibt ein pfeifendes oder zischendes Geräusch ab.

Mögliche Ursache: Der Regelkreis (Feedback-Schleife) ist unterbrochen oder instabil. Der Optokoppler PC817 (U3) oder der Referenzregler TL431 (U2) ist defekt. Alternativ ist einer der Widerstände im Spannungsteiler (R6/R7) gealtert oder der Kompensationskondensator C4 hat seine Kapazität verloren.
Überprüfung:
1. Prüfen Sie die Widerstände R7 (38 kΩ) und R6 (10 kΩ) auf korrekte Werte.
2. Überprüfen Sie den Kompensationskondensator C4 auf mechanische Risse oder Kurzschluss.
3. Testen Sie den Optokoppler PC817 primär- und sekundärseitig.
Lösung: Ersetzen Sie den Optokoppler PC817 und den Regelbaustein TL431. Tauschen Sie den Kompensationskondensator C4 aus, um den Regelkreis wieder zu stabilisieren und Schwingungen zuverlässig zu dämpfen.

## PCB-Design & Layout-Empfehlungen

Beim Design einer Leiterplatte (PCB) für das OB2263-Schaltnetzteil müssen strenge Layoutregeln befolgt werden, um Störstrahlung (EMI) zu minimieren und die elektrische Sicherheit (Kriechstrecken) zu

garantieren:

1. Sicherheitsabstände (Creepage & Clearance): Zwischen der Primärseite (Hochspannung) und der Sekundärseite (SELV/Berührbar) muss ein Mindestabstand von 6,0 mm bis 8,0 mm eingehalten werden.
Auf der Platine sollte unter dem Optokoppler U3 und dem Transformator T1 eine physische Isolationsfräsung (Schlitz in der Platine) integriert werden, um Kriechströme bei Feuchtigkeit zu verhindern.
2. Leistungsstromschleifen minimieren: Die Stromschleife der Primärseite (C1 (+) -> T1 Primärwicklung -> Q1 Drain-Source -> R1 -> C1 (-)) muss so kurz und kompakt wie möglich gehalten werden. Große Schleifen wirken wie Rahmenantennen und strahlen massive elektromagnetische Störungen ab.
Die sekundärseitige Leistungsschleife (T1 Sekundärwicklung -> D4 -> C5 -> T1 Masse) muss ebenfalls extrem kompakt ausgelegt werden.
3. Masseführung (GND):
Verwenden Sie getrennte Leitungen für die Signalmasse des Steuer-ICs U1 (Pin 1) und die Leistungsmasse (Source von Q1, Unterseite des Shunts R1, Minuspol von C1). Verbinden Sie diese Massen sternförmig an genau einem Punkt: dem Minuspol des Primär-Ladekondensators C1.
4. Gate-Leitung:
Die Verbindung vom GATE-Pin 6 des U1 zum Gate des MOSFETs Q1 muss so kurz wie möglich sein, um parasitäres Schwingen im Schaltmoment zu unterdrücken. Ein kleiner Serienwiderstand (z. B. $10,Omega$ bis $22,Omega$) direkt am Gate-Pin dämpft Schwingungen zusätzlich.

Dieses Dokument wurde mit größter Sorgfalt für Entwickler, Servicetechniker und Elektroniker zusammengestellt. Beachten Sie bei allen Arbeiten stets die geltenden Sicherheitsvorschriften der VDE/EN.

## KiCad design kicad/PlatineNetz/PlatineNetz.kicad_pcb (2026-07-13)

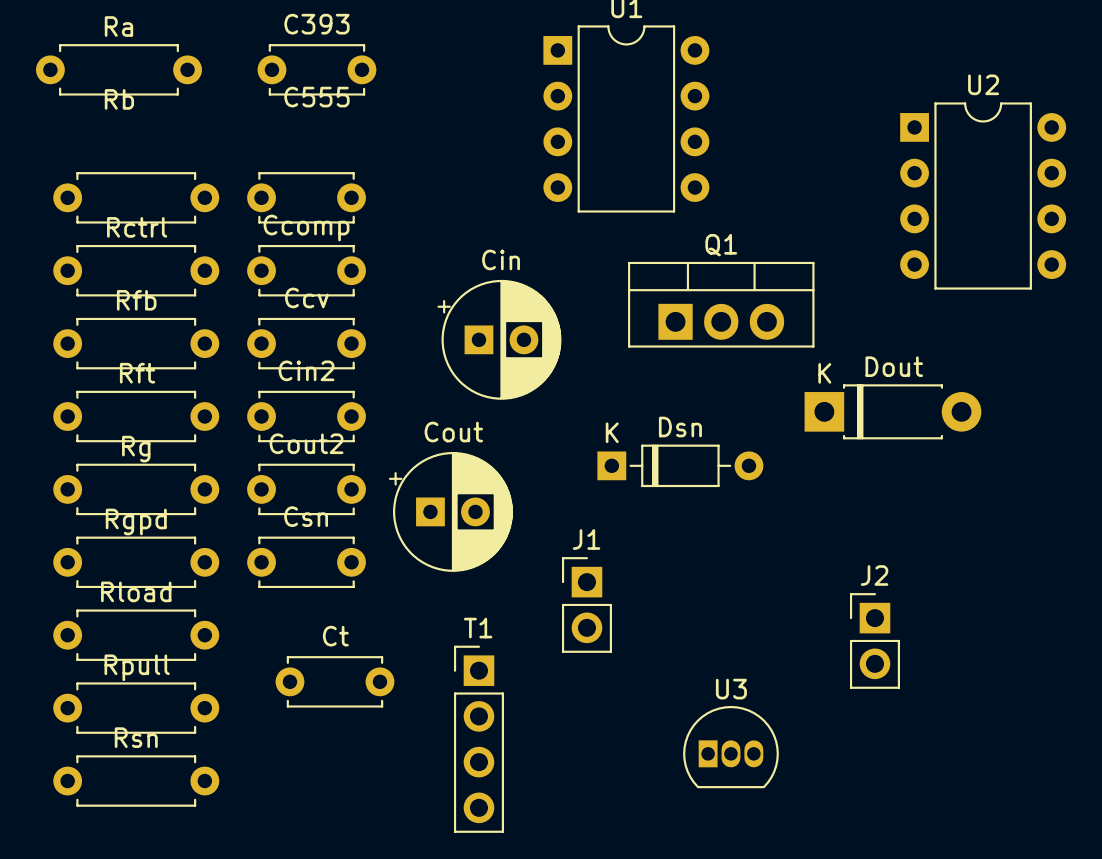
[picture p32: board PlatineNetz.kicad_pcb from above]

Board: 2 copper layers, 29 parts (0 on the bottom side), 13 nets, no tracks yet.

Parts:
C393, C555: 100nF; C_Disc_D5.0mm_W2.5mm_P5.00mm
Ccomp: 10nF; C_Disc_D5.0mm_W2.5mm_P5.00mm
Ccv: 10nF; C_Disc_D5.0mm_W2.5mm_P5.00mm
Cin: 100uF/25V; CP_Radial_D6.3mm_P2.50mm
Cin2: 100nF; C_Disc_D5.0mm_W2.5mm_P5.00mm
Cout: 220uF/16V; CP_Radial_D6.3mm_P2.50mm
Cout2: 100nF; C_Disc_D5.0mm_W2.5mm_P5.00mm
Csn: 1nF; C_Disc_D5.0mm_W2.5mm_P5.00mm
Ct: 1nF; C_Disc_D5.0mm_W2.5mm_P5.00mm
Dout: 1N5819; D_DO-41_SOD81_P7.62mm_Horizontal
Dsn: 1N4148; D_DO-35_SOD27_P7.62mm_Horizontal
J1: 12V DC IN; PinHeader_1x02_P2.54mm_Vertical
J2: VOUT; PinHeader_1x02_P2.54mm_Vertical
Q1: IRLZ44N; TO-220-3_Vertical
Ra: 2k2; R_Axial_DIN0207_L6.3mm_D2.5mm_P7.62mm_Horizontal
Rb: 9k1; R_Axial_DIN0207_L6.3mm_D2.5mm_P7.62mm_Horizontal
Rctrl: 2k2; R_Axial_DIN0207_L6.3mm_D2.5mm_P7.62mm_Horizontal
Rfb: 10k; R_Axial_DIN0207_L6.3mm_D2.5mm_P7.62mm_Horizontal
Rft: 10k; R_Axial_DIN0207_L6.3mm_D2.5mm_P7.62mm_Horizontal
Rg: 22; R_Axial_DIN0207_L6.3mm_D2.5mm_P7.62mm_Horizontal
Rgpd: 10k; R_Axial_DIN0207_L6.3mm_D2.5mm_P7.62mm_Horizontal
Rload: 25; R_Axial_DIN0207_L6.3mm_D2.5mm_P7.62mm_Horizontal
Rpull: 4k7; R_Axial_DIN0207_L6.3mm_D2.5mm_P7.62mm_Horizontal
Rsn: 100; R_Axial_DIN0207_L6.3mm_D2.5mm_P7.62mm_Horizontal
T1: EE16, Np:Ns=2:1; PinHeader_1x04_P2.54mm_Vertical
U1: NE555; DIP-8_W7.62mm
U2: LM393; DIP-8_W7.62mm
U3: TL431; TO-92_Inline

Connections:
CLAMP: Csn.1, Dsn.1, Rsn.1
COMPOUT: Rg.1, Rpull.2, U2.1
CONTROL: Ccomp.1, Rctrl.2, U2.3, U3.3
DRAIN: Dsn.2, Q1.2, T1.1
FB: Ccomp.2, Rfb.1, Rft.2, U3.1
GATE: Q1.1, Rg.2, Rgpd.1
GND: C393.2, C555.2, Ccv.2, Cin.2, Cin2.2, Cout.2, Cout2.2, Ct.2, J1.2, J2.2, Q1.3, Rfb.2, Rgpd.2, Rload.2, T1.4, U1.1, U2.4, U2.5, U3.2
unnamed: Ra.2, Rb.1, U1.7
unnamed: Ccv.1, U1.5
RAMP: Ct.1, Rb.2, U1.2, U1.6, U2.2
SEC: Dout.2, T1.3
VIN: C393.1, C555.1, Cin.1, Cin2.1, Csn.2, J1.1, Ra.1, Rctrl.1, Rpull.1, Rsn.2, T1.2, U1.4, U1.8, U2.6, U2.8
VOUT: Cout.1, Cout2.1, Dout.1, J2.1, Rft.1, Rload.1

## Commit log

2026-07-12 HeftAnsicht des Netzteils
2026-07-13 Falstad-Schaltplan, KiCad-Board (PlatineNetz) und Heft-Update
    - Detaillierter Falstad-Schaltplan (SVG+PNG) + Abschnitt in NetzgeraetFalstadKi.md
    - KiCad-Demoboard: SKiDL-Skript, Netzliste, Projekt PlatineNetz (sch/pcb/render)
    - NetzgeraetHeft.pdf: Schaltplan als Seite 10 eingefuegt
    - Falstad-Schaltungsdateien (.txt) und Heft-Quelle (HTML)
    - .gitignore fuer KiCad-/SKiDL-Artefakte
    [PlatineNetz.kicad_pcb, PlatineNetz.kicad_sch]
2026-07-14 Falstad-Simulation: funktionierende Regelung (Screenshot + Kurzfassung)
    - NetzRegelung.png (Falstad-Regelkreis, TP ~11,5 V)
    - NetzgeraetHeft.pdf: Simulations-Seite (S.11) mit Zahlencheck/Kurzfassung
    - NetzgeraetFalstadKi.md: Abschnitt 'Funktionierende Simulation'
2026-07-18 Ansicht der Platine
2026-09-14 Aufgaben der Drossel im Schaltnetzteil
2026-10-06 Buch drucken Vorlage A5, 170 x 240mm
2026-11-01 Bauteile-Stückliste der Platine in Exel
